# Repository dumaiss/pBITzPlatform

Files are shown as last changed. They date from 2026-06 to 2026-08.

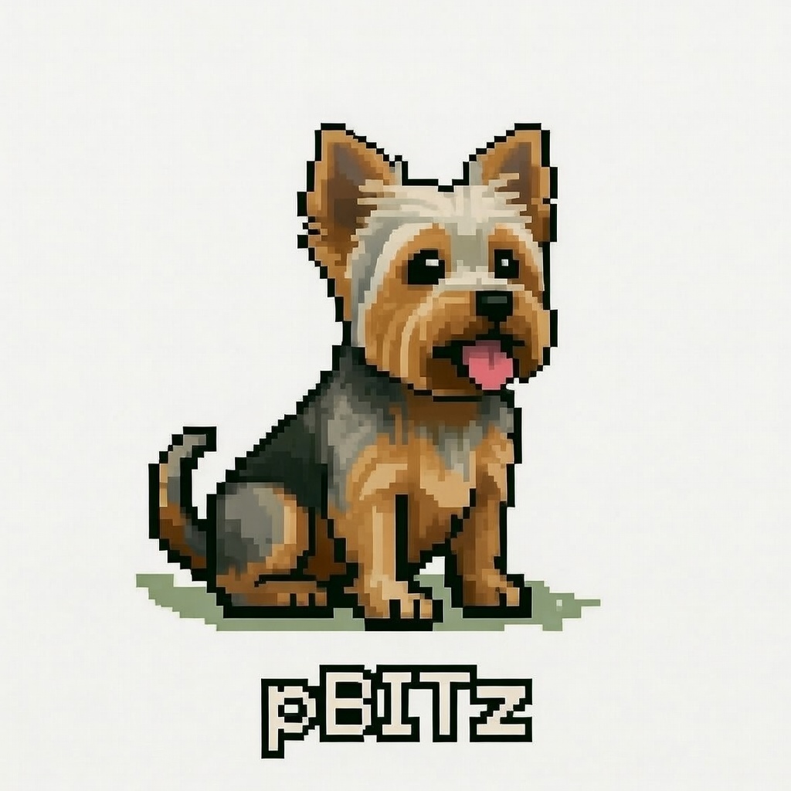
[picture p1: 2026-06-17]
pBITz.jpg

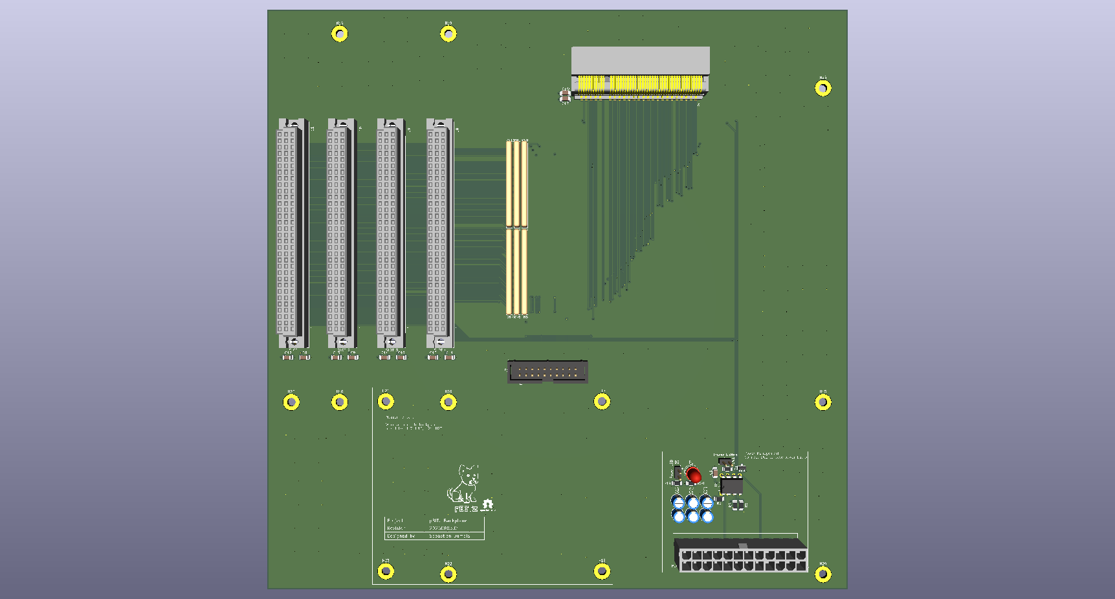
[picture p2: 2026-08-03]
pBITzBackplane/pBITzBackplane.png

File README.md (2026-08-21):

# pBITz Platform

pBITz is the shared hardware platform used by the **Coffee Series** of homebrew computers. It provides the common physical and electrical foundation — backplane, power control, service interfaces, reusable KiCad assets, test hardware, and platform tools — while leaving the personality of each machine to its CPU board and machine-specific peripherals.

The goal is not to define one rigid computer architecture. Instead, pBITz provides a practical common platform on which very different machines can be built: 8-bit, 16-bit, and eventually wider systems can share the same mechanical infrastructure, power distribution, expansion-card format, and platform services without pretending that a Z80, 6309, 68000, 68030, or ARM-class processor has the same bus semantics.

This repository contains the **platform-level** hardware and support material. Machine-specific CPU, video, sound, and operating-system work normally lives in the corresponding Coffee Series repository.

> **Important:** pBITz is a custom parallel expansion bus. The current platform uses DIN 41612-style connectors; it is not PCI Express and is not electrically compatible with PC expansion buses.

## Design philosophy

pBITz deliberately keeps the backplane simple.

The backplane distributes signals, power, clocks, and service connections, but it does not try to impose a universal bus controller or chipset. The CPU board for a particular machine is responsible for turning that machine's native bus into the pBITz signal conventions and for defining how the generic control lines are interpreted.

That leads to a few guiding principles:

- **The backplane is infrastructure, not the computer.** The machine emerges from the CPU board, IO Controller, and installed peripheral cards.
- **Use conventional parallel buses where practical.** Address, data, read/write, interrupt, arbitration, and timing signals remain visible rather than being hidden behind an FPGA SoC.
- **Share mechanics and services without forcing identical CPU semantics.** An 8-bit machine may use only part of the available data/address width; a 16-bit machine can use more of it.
- **Keep platform services separate from machine personality.** Power management, the service SPI bus, removable storage, USB hosting, test interfaces, and reusable CAD assets belong here.
- **Prefer inspectable hardware.** The project is intended to remain understandable with schematics, logic probes, oscilloscopes, PLDs, and ordinary firmware tools.

## Platform overview

At a high level, a pBITz system looks like this:

```text
                        +----------------------+
                        |   Coffee Series      |
                        |     CPU board        |
                        +----------+-----------+
                                   |
          +------------------------+------------------------+
          |                    pBITz bus                    |
          | address / data / control / clocks / power      |
          +-----+------------------+------------------+-----+
                |                  |                  |
          +-----+-----+      +-----+-----+      +-----+-----+
          |  Video    |      |   Sound   |      | Other I/O |
          |   card    |      |   card    |      |   cards   |
          +-----------+      +-----------+      +-----------+
                                   |
                           pBITz backplane
                                   |
                +------------------+------------------+
                |                                     |
          ATX power / PMU                    service / SPI header
                                                      |
                                             +--------+--------+
                                             |   mezzanine     |
                                             | USB host + SD   |
                                             +-----------------+
```

The exact cards and signal meanings depend on the machine being built.

## pBITz bus

The pBITz expansion bus is intentionally broader than any one Coffee Series CPU requires. The current signal set provides room for:

- up to a **24-bit address bus**;
- up to a **16-bit data bus**;
- generic CPU control/status lines (`CTRL_*`) whose meanings are assigned by the CPU implementation;
- chip-select lines;
- multiple clock lines;
- interrupt and bus-control signals;
- a shared platform **SPI/service bus**;
- system reset and power-management signals;
- `+5 V`, `+3.3 V`, and ground distribution.

An individual machine does not need to use every signal. For example, an 8-bit CPU board can use the low data byte and the subset of address/control lines it needs, while a 16-bit machine can make use of the wider path.

The generic control-line approach is deliberate. Signals such as read, write, memory request, I/O request, bus arbitration, wait/ready, interrupt, and byte strobes differ significantly between processor families. The CPU board performs the required mapping rather than forcing every machine through a single artificial protocol.

See [`pBITz_Control_Signals.md`](pBITz_Control_Signals.md) and, more importantly, the current KiCad schematics for the concrete mapping used by a particular hardware revision.

## Backplane

[`pBITzBackplane/`](pBITzBackplane/) contains the main pBITz backplane.

It is primarily a passive bus-distribution board with an always-on power-management island. Its responsibilities include:

- distributing the pBITz address, data, control, clock, and service signals between slots;
- distributing `+5 V`, `+3.3 V`, and ground from an ATX supply;
- providing bus pull-ups where required;
- exposing the platform service interface on an IDC header;
- coordinating ATX power-up and orderly shutdown through the PMU.

The directory contains the KiCad source, fabrication outputs, architecture notes, and revision-specific validation material.

### Power management

The backplane includes an ATtiny-based **PMU** powered from the ATX standby rail. It handles the enclosure power switch and ATX `PS_ON#` / `PWR_OK` sequencing and can coordinate an orderly shutdown with the machine's IO Controller.

PMU firmware lives under [`Code/PMU/`](Code/PMU/).

## Backplane mezzanine

[`pBITzBackplaneMezzanine/`](pBITzBackplaneMezzanine/) contains the platform I/O mezzanine attached through the backplane service connector.

The current design provides:

- a **MAX3421E** SPI USB host controller;
- an **FE1.1** USB hub;
- multiple downstream USB connections;
- an **SD card** operating in SPI mode;
- the necessary buffering, level conversion, power distribution, and card-detect/interrupt paths.

This keeps common storage and USB services out of the CPU-specific logic while still making them available to machines through the platform service interface.

## Platform support hardware

### pBITz Test Card

[`pBITzTestCard/`](pBITzTestCard/) is a work-in-progress platform development and diagnostic card. The current schematic work includes concepts for:

- a console interface;
- external programming support;
- an MCU-based controller;
- USB/JTAG programming and test functions.

This project is currently development hardware rather than a finished production design.

### pBITz Terminal

[`pBITzTerminal/`](pBITzTerminal/) explores a standalone serial terminal suitable for use with pBITz and other retro systems.

The current architecture is based around an HD63C03-family CPU and MC6845-compatible CRTC, with a VGA-style text display, PS/2 keyboard support, serial communications, banked SRAM, programmable character memory, and PLD-based video/bus arbitration.

The terminal is an experimental design and should not be treated as a completed board yet.

## Platform tools and firmware

[`Code/`](Code/) contains code that belongs to the platform rather than to one specific Coffee Series machine.

Current contents include:

- [`Code/PMU/`](Code/PMU/) — ATtiny power-management firmware, including a host-testable state machine;
- [`Code/tools/kicad_nettrace.py`](Code/tools/kicad_nettrace.py) — a KiCad schematic connectivity-analysis helper used during design reviews.

A typical connectivity check is:

```sh
python3 Code/tools/kicad_nettrace.py pBITzBackplane/pBITzBackplane.kicad_sch --check
```

`kicad_nettrace.py` is a review aid, not a replacement for KiCad's own connectivity model. When the helper and KiCad disagree, the **KiCad schematic/netlist is authoritative**.

## Shared KiCad assets

[`99-KiCad-Lib/`](99-KiCad-Lib/) is the shared CAD library used across the platform and Coffee Series projects. It contains:

- custom schematic symbols;
- footprints;
- 3D models;
- pBITz connector definitions;
- reusable parts used by the various machines;
- project artwork and board logos.

Keeping these assets in the platform repository avoids maintaining slightly different copies in every machine repository.

## Datasheets

[`00-Datasheets/`](00-Datasheets/) collects component documentation used while designing the platform and Coffee Series machines. It is organized by broad component class, including:

- analog;
- CPUs and MCUs;
- connectors;
- logic;
- memory;
- oscillators;
- peripherals;
- power components.

The datasheet directory is a working engineering reference, not intended to be a complete historical semiconductor archive.

## Repository layout

| Path | Purpose | Status |
| --- | --- | --- |
| `pBITzBackplane/` | Main backplane, ATX interface, PMU hardware, service bus | Active hardware design |
| `pBITzBackplaneMezzanine/` | Shared USB/SD service mezzanine | Active hardware design |
| `Code/PMU/` | Backplane power-management firmware | Implemented / evolving |
| `Code/tools/` | Platform engineering and KiCad-analysis tools | Active |
| `pBITzTestCard/` | Platform diagnostic/programming card | Work in progress |
| `pBITzTerminal/` | Standalone serial/VGA terminal experiment | Experimental |
| `99-KiCad-Lib/` | Shared KiCad symbols, footprints, and 3D models | Shared infrastructure |
| `00-Datasheets/` | Engineering reference datasheets | Shared infrastructure |
| `pBITz_Control_Signals.md` | Cross-CPU control-signal mapping notes | Design reference |

## Relationship to the Coffee Series

pBITz exists so that the Coffee Series machines can share a physical platform without becoming variants of the same computer.

Examples of machines built or planned around the platform include architectures based on processors such as the Z80, HD6309, 68000/68030, and ARM-class CPUs. Each machine is free to define its own memory architecture, CPU timing, interrupt model, video hardware, sound hardware, firmware, and operating system while reusing the pBITz mechanical and platform infrastructure where it makes sense.

In other words:

> **pBITz provides the chassis and electrical vocabulary; the CPU and peripheral set define the computer.**

## Source of truth and revision notes

This is an actively developed hardware platform. Schematics, PCB layouts, production files, architecture notes, and validation reports do not always change at the same time.

When reviewing a design:

1. treat the current **KiCad schematic and PCB files** as the source of truth for the active hardware revision;
2. use architecture documents to explain intent and operation;
3. check the date/revision of validation reports and fabrication outputs before assuming they describe the current board;
4. regenerate production files after a hardware revision rather than assuming an older BOM/Gerber package remains current.

This is particularly important when a mechanical or connector revision changes without altering the higher-level bus concept.

## Hardware status and validation

Validation reports in this repository document engineering checks performed against particular revisions of the design files. They are useful review records, but they are not certification and do not replace physical bring-up.

Unless explicitly stated otherwise, repository-level validation may include schematic/netlist consistency and selected PCB checks, while powered measurements, signal-integrity characterization, enclosure fit, manufacturing tolerances, and real-hardware testing remain separate activities.

## License

Unless noted otherwise, the hardware and associated source material in this repository are released under the **Solderpad Hardware License v2.1**, with the option described in the license to treat the work under Apache License 2.0.

See [`Licence.md`](Licence.md) for the complete terms.

---

pBITz is an evolving homebrew-computer platform. Expect the schematics to remain understandable, the buses to remain visible, and occasionally a logic analyzer to become part of the debugging process.

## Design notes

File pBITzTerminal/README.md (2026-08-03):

# HD63C03Y VGA Terminal — Preliminary BOM

**Revision:** Rev A draft
**Board:** 100 × 100 mm, 4 layers
**Supply:** Regulated +5 V
**Display target:** 80 × 30 characters, 8 × 16 glyphs, approximately 640 × 480 at 60 Hz
**Host interfaces:** RS-232 fitted; RS-422/pBITz interface DNP
**Keyboard:** PS/2
**Terminal target:** VT100-compatible firmware with ANSI color extensions

## 1. Architecture summary

* Hitachi HD63C03Y CPU at 3 MHz
* Motorola MC6845B CRTC at 3 MHz
* 24.000 MHz master video clock
* 14.7456 MHz baud-rate reference
* 32 KiB firmware EEPROM
* 512 KiB banked SRAM
* 8 KiB programmable character EEPROM
* Two independently mapped 16 KiB CPU SRAM windows
* One independently selected 16 KiB video bank
* Four-slot shared-SRAM cycle:

  1. Character fetch
  2. Primary attribute fetch
  3. Secondary attribute fetch
  4. CPU access
* Multiple ATF22V10 PLDs for clocks, decode, arbitration, baud generation, and video attributes

## 2. CPU memory map

| Address | Function |
| --- | --- |
| `0000–0027` | HD63C03Y internal registers |
| `0028–003F` | Unused/reserved external space |
| `0040–013F` | HD63C03Y internal 256-byte RAM |
| `0140–3FFF` | SRAM window A, selected by `BANK_A` |
| `4000–7FEF` | SRAM window B, selected by `BANK_B` |
| `7FF0–7FFF` | External control-register block |
| `8000–FFFF` | AT28C256 firmware EEPROM and interrupt vectors |

Although the internal register/RAM area obscures part of logical window A, no physical SRAM is lost: the same physical bank can be mapped into window B to access offsets `0000–013F`.

### External register block

| Address | Register | Access |
| --- | --- | --- |
| `7FF0` | MC6845 register index | Write |
| `7FF1` | MC6845 register data  | Read/write |
| `7FF2` | SRAM bank A, bits 0–4 | Write |
| `7FF3` | SRAM bank B, bits 0–4 | Write |
| `7FF4` | Video bank/control | Write |
| `7FF5–7FFF` | Reserved | — |

Suggested `VIDEO_BANK/CONTROL` format:

| Bit | Function |
| --: | --- |
| 0–4 | Physical 16 KiB video bank |
| 5 | Global font-bank select |
| 6 | Video enable |
| 7 | Reserved |

## 3. Video-bank layout

Each video bank is 16 KiB:

| Offset |  Size | Function |
| --- | ----: | --- |
| `0000–0FFF` | 4 KiB | Character cells |
| `1000–1FFF` | 4 KiB | Primary attributes |
| `2000–2FFF` | 4 KiB | Secondary attributes |
| `3000–3FFF` | 4 KiB | Spare: line metadata, tab state, future use |

An 80 × 30 display requires 2,400 entries in each plane, leaving spare space for circular scrolling.

### Suggested attributes

Primary attribute byte:

| Bits | Function |
| ---- | --- |
| 0–2  | Foreground RGB |
| 3–5  | Background RGB |
| 6 | Bright/bold |
| 7 | Blink |

Secondary attribute byte:

| Bit | Function |
| --: | --- |
| 0 | Underline |
| 1 | Protected field |
| 2 | Application-defined |
| 3 | Application-defined |
| 4–7 | Reserved |

Reverse video and conceal can be encoded when the character is written by swapping or replacing foreground/background colors.

## 4. Character EEPROM layout

The AT28C64B contains two programmable 256-character fonts:

| Address | Function |
| --- | --- |
| `0000–0FFF` | Font bank 0: 256 × 16-byte glyphs |
| `1000–1FFF` | Font bank 1: alternate font |

Address assignment:

```text
A0–A3   = MC6845 raster address RA0–RA3
A4–A11  = character code
A12      = global font-bank select
```

DEC Special Graphics characters can be placed in unused positions of the 256-character font and selected by firmware character translation.

## 5. Main integrated circuits

| Ref. | Qty | Selected part/function | Package | Source |
| ---- | --: | --- | --- | --- |
| U1 | 1 | HD63C03YCP CPU | PLCC-68 | BUY |
| U2 | 1 | MC6845B CRTC | DIP-40  | STASH |
| U3 | 1 | AT28C256-15PU firmware EEPROM, 32 KiB  | DIP-28  | STASH |
| U4 | 1 | AS6C4008-55PIN SRAM, 512 KiB | DIP-32  | STASH |
| U5 | 1 | AT28C64B-15PU character EEPROM, 8 KiB  | DIP-28  | STASH |
| U6 | 1 | ATF22V10C-10SU system decode PLD | SOIC-24 | STASH—VERIFY |
| U7 | 1 | ATF22V10C-10SU SRAM arbitration PLD | SOIC-24 | STASH—VERIFY |
| U8 | 1 | ATF22V10C-10SU master-clock/timing PLD | SOIC-24 | STASH—VERIFY |
| U9 | 1 | ATF22V10C-10SU baud-rate PLD | SOIC-24 | STASH—VERIFY |
| U10  | 1 | ATF22V10C-10SU attribute/RGB PLD | SOIC-24 | STASH—VERIFY |

### Intended PLD responsibilities

**U6 — SYS**

* EEPROM chip enable
* MC6845 select
* external register decode
* bank-latch write strobes
* video-control write strobe
* readback qualification

**U7 — ARB**

* shared-SRAM CPU/video ownership
* `MR` wait generation
* SRAM `/OE` and `/WE`
* SRAM/data-transceiver enable
* bank-latch output enables
* CPU/video address-mux select

**U8 — CLOCK**

* 24 MHz phase counter
* 12 MHz HD63C03 EXTAL output
* 3 MHz MC6845 character clock
* character/attribute fetch strobes
* character-boundary pipeline load

**U9 — BAUD**

* programmable division of 14.7456 MHz
* external SCI clocks for:

  * 115200 baud
  * 57600 baud
  * 38400 baud
  * 19200 baud
  * 9600 baud

**U10 — VIDEO**

* foreground/background selection
* bold/highlight
* blink
* underline
* cursor rendering
* blanking
* six RGB intensity outputs

## 6. SRAM banking and video pipeline

| Ref. | Qty | Part/function | Package | Source |
| --- | --: | --- | --- | --- |
| U11–U13 | 3 | SN74HC373 bank/control latches | TSSOP-20 | STASH—VERIFY |
| U14 | 1 | SN74HC373 character staging latch | TSSOP-20 | STASH—VERIFY |
| U15 | 1 | SN74HC373 primary-attribute staging latch | TSSOP-20 | STASH—VERIFY |
| U16 | 1 | SN74HC373 secondary-attribute staging latch | TSSOP-20 | STASH—VERIFY |
| U17 | 1 | SN74HC373 active primary-attribute latch | TSSOP-20 | STASH—VERIFY |
| U18 | 1 | SN74HC273 pipeline/control latch | SOIC-20 | STASH—VERIFY |
| U19–U22 | 4 | 74AHCT157 quad 2:1 address multiplexers | TSSOP-16/SOIC-16 | BUY |
| U23 | 1 | 74HCT245 bidirectional SRAM bus transceiver | TSSOP-20/SOIC-20 | BUY |
| U24 | 1 | CD74HC299 universal shift register | SOIC-20 | STASH—VERIFY |
| U25 | 1 | SN74HC244 VGA output buffer | SOIC-20 | STASH—VERIFY |
| U26 | 1 | 74HC00 sync inversion/miscellaneous glue | SOIC-14 | STASH |

### Bank-latch arrangement

`BANK_A`, `BANK_B`, and `VIDEO_BANK` latch outputs share SRAM physical address lines `A14–A18`.

Only one latch output is enabled at a time:

```text
CPU access in window A → enable BANK_A
CPU access in window B → enable BANK_B
Video fetch            → enable VIDEO_BANK
```

The PLD must guarantee mutually exclusive, break-before-make output enables.

### Shared-SRAM timing

At 24 MHz, one character period contains eight pixel clocks.

```text
Pixel clocks 0–1: character-plane SRAM read
Pixel clocks 2–3: primary-attribute SRAM read
Pixel clocks 4–5: secondary-attribute SRAM read
Pixel clocks 6–7: CPU SRAM access
```

The CPU `MR` input aligns and stretches SRAM accesses when required. EEPROM and internal-register accesses do not require SRAM arbitration.

## 7. Clock generation

| Ref. | Qty | Part/function | Package | Source |
| ---- | --: | --- | --- | --- |
| X1 | 1 | 24.000 MHz, 5 V HCMOS oscillator | SMD | BUY |
| X2 | 1 | ECS-2100AX-147.4, 14.7456 MHz oscillator | Through-hole XO | STASH  |
| Cx | 2 | 100 nF oscillator decoupling | 0603 | STASH  |
| Rx | 2 | 10 kΩ oscillator-enable pull resistors, if required | 0603 | STASH  |

Clock tree:

```text
24.000 MHz
 ├── direct → pixel shift clock
 ├── ÷2     → 12 MHz HD63C03 EXTAL
 └── ÷8     → 3 MHz MC6845 character clock

14.7456 MHz
 └── programmable divider → HD63C03 P22/SCLK
```

## 8. RS-232 interface

| Ref.  | Qty | Part/function | Package | Source |
| ----- | --: | --- | --- | --- |
| U27 | 1 | MAX233-compatible dual RS-232 transceiver | SOIC-20 | BUY |
| J1 | 1 | DE-9 serial connector | Right-angle through-hole | BUY/TBD |
| R1–R6 | 6 | 0 Ω DTE/DCE routing links | 0603 | BUY/STASH |
| C1 | 1 | 100 nF decoupling | 0603 | STASH |
| D1 | 1 | RS-232 ESD protection array | SMD | OPTIONAL/DNP |

One transmitter/receiver pair carries TX/RX. The second pair may carry RTS/CTS.

The connector routing should permit DTE or DCE population through 0 Ω links.

## 9. PS/2 keyboard interface

| Ref. | Qty | Part/function | Package | Source |
| --- | --: | --- | --- | --- |
| J2 | 1 | Mini-DIN-6 PS/2 receptacle | Right-angle through-hole | BUY |
| R7–R8  | 2 | 4.7 kΩ CLK/DATA pull-ups | 0603 | STASH |
| R9–R10 | 2 | 100–220 Ω series resistors | 0603 | BUY/TBD |
| D2 | 1 | Low-capacitance ESD array | SMD | OPTIONAL/DNP |
| F1 | 1 | Keyboard +5 V resettable fuse | 1206 | STASH/TBD |

The HD63C03 drives CLK and DATA low by changing the relevant port pin to an output-low state and releases the line by returning it to input mode.

## 10. VGA output

| Ref. | Qty | Part/function | Package | Source |
| --- | --: | --- | --- | --- |
| J3 | 1 | DE-15 VGA receptacle | Right-angle through-hole | BUY |
| R11–R16 | 6 | 1.0 kΩ RGB normal/bright resistors | 0603 | STASH |
| R17–R18 | 2 | 33 Ω HSYNC/VSYNC series resistors  | 0603 | STASH |
| D3 | 1 | VGA ESD protection array | SMD | OPTIONAL/DNP |

Each color channel uses two approximately equal resistor branches:

```text
normal-color output ── 1 kΩ ──┐
bright-color output ── 1 kΩ ──┼── VGA color pin
                              └── 75 Ω termination in monitor
```

Approximate levels:

```text
Normal:  one 1 kΩ branch active  → approximately 0.35 V
Bright:  two 1 kΩ branches active → approximately 0.65 V
```

U25 supplies six RGB outputs and buffered HSYNC/VSYNC.

## 11. Reset, configuration, and indicators

| Ref. | Qty | Part/function | Package | Source |
| --- | --: | --- | --- | --- |
| U28 | 1 | 5 V active-low reset supervisor, ≥20 ms delay | SOT-23 | BUY |
| SW1 | 1 | Momentary reset switch | SMD/TH | BUY |
| SW2 | 1 | 4-position configuration DIP switch | SMD/TH | STASH/BUY |
| LED1 | 1 | Power LED | 0603/1206 | STASH |
| LED2 | 1 | Status/RX LED | 0603/1206 | STASH |
| LED3 | 1 | Status/TX LED | 0603/1206 | STASH |
| R19–R21 | 3 | 1 kΩ LED resistors | 0603 | STASH |
| BZ1 | 1 | 5 V piezoelectric terminal bell | Through-hole/SMD | OPTIONAL  |
| Q1 | 1 | Small transistor/MOSFET for bell | SOT-23 | OPTIONAL  |
| R22 | 1 | Bell gate/base resistor | 0603 | OPTIONAL  |

The internal 256-byte RAM is available immediately after reset, allowing firmware to establish a stack and initialize the undefined external bank latches before using external SRAM.

## 12. Power and decoupling

| Ref. | Qty | Part/function | Package | Source  |
| --- | --: | --- | --- | --- |
| J4 | 1 | Regulated +5 V input connector | TBD | BUY |
| F2 | 1 | 0.75–1.0 A resettable fuse | SMD | BUY/TBD |
| D4 | 1 | Reverse-polarity protection device | SMD | BUY/TBD |
| C2–C31  | ~30 | 100 nF ceramic decoupling | 0603 | STASH |
| C32–C35 | 4 | 4.7–10 µF local bulk capacitors | 0603/1206 | STASH |
| C36 | 1 | 100 µF input bulk capacitor | Radial TH | STASH |
| TP1 | 1 | +5 V test point | — | PCB |
| TP2 | 1 | Ground test point | — | PCB |

Use one 100 nF capacitor per IC, placed at the power pins. Additional bulk capacitors should be placed near the PLD cluster, memory/video cluster, and external connectors.

## 13. Sockets and mechanical items

| Qty | Item | Source |
| --: | --- | --- |
| 1 | PLCC-68 socket for HD63C03YCP  | BUY |
| 1 | DIP-40 socket for MC6845B | STASH/BUY |
| 1 | DIP-32 socket for AS6C4008 | BUY |
| 2 | DIP-28 sockets for EEPROMs | STASH/BUY |
| 4 | M3 mounting holes and hardware | BUY |
| 1 | 100 × 100 mm four-layer PCB | FAB |
| 1 | Enclosure | TBD |

SOIC ATF22V10 devices must be programmed before assembly. Provide accessible test pads for all PLD pins and retain an optional DIP-24 development footprint or adapter strategy if frequent PLD iterations are expected.

## 14. Future RS-422/pBITz interface — DNP

Do not finalize these parts until the pBITz external peripheral electrical standard is frozen.

| Ref. | Qty | Placeholder function | Status  |
| --- | --: | --- | --- |
| U29 | 1 | RS-422 line driver, e.g. AM26C31 class | DNP |
| U30 | 1 | RS-422 line receiver, e.g. AM26C32 class | DNP |
| J5 | 1 | pBITz external peripheral connector | DNP/TBD |
| R23–R24 | 2 | 120 Ω termination | DNP |
| R25–R28 | 4 | Receiver bias resistors | DNP/TBD |
| D5 | 1 | Differential-line TVS array | DNP |

## 15. Optional service/debug connections

| Ref. | Qty | Function |
| --- | --: | --- |
| J6 | 1 | TTL-level serial/debug header |
| J7 | 1 | Logic-analyzer header: E, R/W, MR, phase bits, SRAM controls |
| J8 | 1 | Video test header: pixel, DE, HSYNC, VSYNC, glyph load |
| TP3–TP8 | 6 | Major clock and arbitration test points |

## 16. Immediate purchase list

### Required

* 1 × HD63C03YCP, verified PLCC-68
* 1 × PLCC-68 socket
* 1 × 24.000 MHz 5 V HCMOS oscillator
* 4 × 74AHCT157 address multiplexers
* 1 × SMD 74HCT245 bus transceiver
* 1 × MAX233-compatible SMD RS-232 transceiver
* 1 × DE-15 VGA connector
* 1 × Mini-DIN-6 PS/2 connector
* 1 × serial connector
* 1 × reset supervisor
* 1 × appropriately rated resettable fuse
* remaining sockets and mechanical hardware

### Verify in stash before ordering

* 5 × ATF22V10C-10SU
* 7 × SN74HC373 SMD
* 1 × SN74HC273 SMD
* 1 × CD74HC299 SMD
* 1 × SN74HC244 SMD
* 1 × 74HC00 SMD
* 1 × 14.7456 MHz oscillator
* AT28C256
* AT28C64B
* AS6C4008-55PIN
* MC6845B

## 17. Open engineering items

1. Verify the exact MC6845B markings and timing grade.
2. Simulate or bench-test the 83.3 ns SRAM fetch slots with the chosen `157` family.
3. Confirm `MR` phase alignment against the HD63C03Y external bus timing.
4. Determine VGA horizontal/vertical totals for the 24 MHz pixel clock.
5. Freeze the DE-9 DTE/DCE arrangement.
6. Confirm SOIC PLD programming and rework strategy.
7. Establish worst-case +5 V current before selecting the input fuse.
8. Freeze the attribute-byte definitions before writing the video PLD equations.
9. Decide whether the second font EEPROM bank is:

   * alternate terminal font,
   * CP437,
   * Japanese/graphics experiment,
   * or a diagnostic font.

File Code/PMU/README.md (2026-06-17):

# PMU Firmware

Power management unit firmware for the Zephyr-80 system.

The project is intentionally self-contained so additional MCU firmware projects
can be added beside it under `Code/MCU/`.

## Layout

```text
PMU/
  Makefile          AVR-GCC build and flash targets
  include/          Project headers and configuration
  src/              Firmware source
  docs/             Device-specific notes, pinout, and programming details
  build/            Generated objects and firmware images
```

## Toolchain

Expected tools:

- `avr-gcc`
- `avr-objcopy`
- `avr-size`
- `avrdude`

On Debian/Ubuntu systems these are usually provided by:

```sh
sudo apt install gcc-avr avr-libc avrdude
```

## Build

```sh
make
```

Generated files are written to `build/`.

## Test

The power-control policy is implemented as a host-testable state machine.

```sh
make test
```

The tests compile with the host C compiler and do not require the AVR toolchain.

## Flash

Update `PROGRAMMER`, `PORT`, and fuse values in `Makefile` before programming a
real device.

```sh
make flash
```

Fuse programming is separated from firmware flashing:

```sh
make fuses
```

## Power-Control Signals

| Signal | Port | Direction | Active State |
| --- | --- | --- | --- |
| `PWR_OFF_RQ` | PB4 | Input | Low |
| `PWR_STATE` | PB3 | Output | High holds reset, low allows run |
| `PWR_SW` | PB2 | Input | Low |
| `PWR_OK` | PB1 | Input | High |
| `PS_ON` | PB0 | Output | High at PB0, low at ATX `PS_ON#` |

See `docs/pinout.md` for the full pinout and signal behavior.

## IO Controller Bypass

Set `PMU_IGNORE_IO_CONTROLLER_SIGNALS` to `1` in `include/config.h`, or pass it
as a compiler define, to build the PMU without the IO Controller handshake. In
that mode the PMU ignores `PWR_OFF_RQ` and leaves `PWR_STATE` as a high
impedance input instead of driving reset/run state toward the IO Controller.
The 5 second force-off button hold remains available when the handshake is
disabled.

## Power-Off Handshake

When the system is already powered and the enclosure power switch is pressed,
the PMU sets `PWR_STATE` high. This tells the IO Controller to hold the
system in reset and finish its shutdown work. The PMU keeps the PSU enabled
until the IO Controller asserts `PWR_OFF_RQ` low. At that point PB0 is turned
off, disabling the `PS_ON#` MOSFET and allowing the ATX supply to shut down.

If the enclosure power switch is held for 5 seconds while the system is powered,
the PMU turns PB0 off directly and shuts the PSU down without waiting for the IO
Controller.

## Power-On Sequence

When the enclosure power switch is pressed while the system is off, the PMU
turns PB0 on immediately, pulling ATX `PS_ON#` low to start the PSU.
`PWR_STATE` remains high during this startup window so the IO Controller holds
the system in reset. When `PWR_OK` is asserted, the PMU sets `PWR_STATE` low to
allow the IO Controller to run.

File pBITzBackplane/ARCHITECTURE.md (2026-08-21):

# pBITz Backplane Architecture

This document describes the current architecture and physical signal distribution of the `pBITzBackplane` KiCad project.

The source of truth for connectivity is the schematic hierarchy rooted at [`pBITzBackplane.kicad_sch`](pBITzBackplane.kicad_sch). This document explains that design in human-readable form; if this document and the current KiCad sources disagree, the **KiCad schematic wins**.

The logical meaning of the portable `CTRL_*` and `CS[3:0]` conventions is documented separately in [`../pBITz_Control_Signals.md`](../pBITz_Control_Signals.md). This file is intentionally the place where the **physical backplane connectors and their pin mappings** are documented.

---

## 1. Schematic hierarchy

The active design is divided into three sheets:

| Sheet | File | Role |
| --- | --- | --- |
| Root | `pBITzBackplane.kicad_sch` | Top-level hierarchy and board-level interconnect. |
| Power | `Power.kicad_sch` | ATX input, standby-powered PMU, power switch, indicators, and `PS_ON#` control. |
| Backplane | `Backplane.kicad_sch` | DIN expansion connectors, cartridge connector, service header, bus pull-ups, and slot decoupling. |

The backplane is deliberately simple. Apart from the power-management island it is primarily a passive distribution board; CPU-specific decode, timing adaptation, and bus semantics live on the CPU board or its associated glue logic.

---

## 2. Physical connector architecture

The current backplane has **two different expansion connector types** serving different mechanical roles:

| Ref | Role | Connector | Notes |
| --- | --- | --- | --- |
| `J8` | pBITz expansion slot | DIN 41612, 96-position | Amphenol `86093968114T55F1LF`; right-angle backplane connector. |
| `J9` | pBITz expansion slot | DIN 41612, 96-position | Same electrical pinout as J8. |
| `J10` | pBITz expansion slot | DIN 41612, 96-position | Same electrical pinout as J8. |
| `J11` | pBITz expansion slot | DIN 41612, 96-position | Same electrical pinout as J8. |
| `J6` | Cartridge slot | PCIe x8-style, 98-contact | Samtec `PCIE-098-02-X-D-RA`; right-angle connector. **Mechanical connector only: this is not PCI Express.** |
| `J7` | Platform service header | 2x10 IDC | Exposes power and the SPI/service interface to the backplane mezzanine. |

The four ordinary expansion positions therefore use the DIN connector introduced with the current pBITz mechanical architecture, while the cartridge slot deliberately retains the compact right-angle PCIe x8 connector.

### Important: the cartridge connector is not PCI Express

`J6` uses a connector mechanically associated with PCI Express, but its electrical interface is the **pBITz parallel bus**. A PCI Express card must never be connected to it, and a pBITz cartridge must never be inserted into a PC PCIe slot.

The cartridge connector is now part of the **main backplane**, not the USB/SD mezzanine. It receives the same current pBITz bus presented to the DIN expansion slots, including the general clock lines.

---

## 3. pBITz bus carried by the backplane

The current backplane distributes the following logical groups:

| Group | Signals | Notes |
| --- | --- | --- |
| Address | `A0..A23` | 24-bit parallel address bus. |
| Data | `D0..D15` | 16-bit parallel data bus. |
| Control | `CTRL_0..CTRL_19` | Cross-CPU control vocabulary; see `pBITz_Control_Signals.md`. |
| Device select | `CS0..CS3` | Push-pull 4-bit device address `CS[3:0]`; `0000` means no device selected. |
| General clocks | `CLK0`, `CLK1` | Two current general-purpose pBITz clock lines. Passive distribution only. |
| Auxiliary control | `/PROG`, `/CART` | Platform/machine auxiliary control lines. |
| Service SPI | `SPI_CLK`, `MOSI`, `MISO`, `SPI_CS0`, `SPI_CS1`, `/SPI_INT`, `/SPI_CD` | Shared platform service interface. `SPI_CLK` is separate from the general pBITz clock lines. |
| Power management | `/PWR_OFF`, `/SHUTDOWN_RQ` | PMU/IO-controller shutdown handshake. |
| Power | `+5V`, `+3V3`, `GND` | Distributed to expansion and cartridge connectors. |

### Clock count

The **current bus has two general clock lines: `CLK0` and `CLK1`**.

Older pBITz connector symbols and documentation contained additional `CLK2`/`CLK3` names. They are not active clocks in the current backplane. On the instantiated cartridge connector `J6`, the legacy A5/A6 positions associated with those old symbol names are explicitly unconnected; `CLK0` and `CLK1` are carried on J6 B5 and B6.

`SPI_CLK` is the clock of the separate service SPI interface and is not counted as a general pBITz CPU/peripheral clock.

The backplane does not synthesize or condition `CLK0` or `CLK1`; it only distributes them. Their source and meaning are defined by the machine/CPU implementation.

---

## 4. DIN 41612 expansion-slot pinout

`J8` through `J11` are electrically identical 96-position DIN 41612 pBITz slots. The connector uses rows A, B, and C with positions 1 through 32.

| Pos. | Row A | Row B | Row C |
| ---: | --- | --- | --- |
| 1 | `+5V` | `+5V` | `/PWR_OFF` |
| 2 | `+5V` | `+5V` | `/SHUTDOWN_RQ` |
| 3 | `+3V3` | `+3V3` | `GND` |
| 4 | `+3V3` | `+3V3` | `GND` |
| 5 | `CLK0` | `CLK1` | `SPI_CLK` |
| 6 | `/PROG` | `/CART` | `/SPI_CD` |
| 7 | `CTRL_0` (`/RESET`) | `CTRL_1` | `CTRL_2` |
| 8 | `CTRL_3` | `CTRL_4` | `CTRL_5` |
| 9 | `CTRL_6` | `CTRL_7` | `CTRL_8` |
| 10 | `CTRL_9` | `CTRL_10` | `CTRL_11` |
| 11 | `CTRL_12` | `CTRL_13` | `CTRL_14` |
| 12 | `CTRL_15` | `CTRL_16` | `CTRL_17` |
| 13 | `CTRL_18` | `CTRL_19` | `CS0` |
| 14 | `CS1` | `CS2` | `CS3` |
| 15 | `D0` | `D1` | `D2` |
| 16 | `D3` | `D4` | `D5` |
| 17 | `D6` | `D7` | `D8` |
| 18 | `D9` | `D10` | `D11` |
| 19 | `D12` | `D13` | `D14` |
| 20 | `D15` | `GND` | `GND` |
| 21 | `A0` | `A1` | `A2` |
| 22 | `A3` | `A4` | `A5` |
| 23 | `A6` | `A7` | `A8` |
| 24 | `A9` | `A10` | `A11` |
| 25 | `A12` | `A13` | `A14` |
| 26 | `A15` | `A16` | `A17` |
| 27 | `A18` | `A19` | `A20` |
| 28 | `A21` | `A22` | `A23` |
| 29 | `GND` | `GND` | `GND` |
| 30 | `/SPI_INT` | `MISO` | `MOSI` |
| 31 | `SPI_CS0` | `SPI_CS1` | `GND` |
| 32 | `GND` | `GND` | `GND` |

The connector shield/mechanical contacts `S1` and `S2` are also tied to `GND`.

The DIN layout deliberately groups related signals while inserting ground positions through the connector, particularly around the address and service portions of the bus.

---

## 5. Cartridge slot J6

`J6` is the dedicated cartridge connector. It uses the right-angle Samtec `PCIE-098-02-X-D-RA`, a 98-contact connector with A and B sides numbered 1 through 49.

Although the mechanical format is PCIe x8, **the entire electrical assignment is custom pBITz**.

### 5.1 Cartridge bus coverage

The cartridge connector exposes the full current pBITz interface needed by a cartridge to behave like a directly attached bus device:

- all `A0..A23` address lines;
- all `D0..D15` data lines;
- all `CTRL_0..CTRL_19` control lines;
- all four `CS[3:0]` device-select lines;
- both current general clocks, `CLK0` and `CLK1`;
- `/PROG` and `/CART`;
- the complete SPI/service interface;
- `/PWR_OFF` and `/SHUTDOWN_RQ`;
- `+5V`, `+3V3`, and ground.

The cartridge slot is therefore not a reduced sideband interface. Electrically it is another endpoint on the pBITz bus, with a different mechanical connector chosen for cartridge use.

### 5.2 Cartridge physical pinout

| Pos. | Side A | Side B |
| ---: | --- | --- |
| 1 | `+5V` | `+5V` |
| 2 | `+5V` | `+5V` |
| 3 | `/SHUTDOWN_RQ` | `/PWR_OFF` |
| 4 | `GND` | `GND` |
| 5 | **NC** (legacy `CLK2` position) | `CLK0` |
| 6 | **NC** (legacy `CLK3` position) | `CLK1` |
| 7 | `SPI_CLK` | `/SPI_CD` |
| 8 | `/PROG` | `/CART` |
| 9 | `+3V3` | `+3V3` |
| 10 | `+3V3` | `+3V3` |
| 11 | `CTRL_10` | `CTRL_0` (`/RESET`) |
| 12 | `CTRL_11` | `CTRL_1` |
| 13 | `CTRL_12` | `CTRL_2` |
| 14 | `CTRL_13` | `CTRL_3` |
| 15 | `CTRL_14` | `CTRL_4` |
| 16 | `CTRL_15` | `CTRL_5` |
| 17 | `CTRL_16` | `CTRL_6` |
| 18 | `CTRL_17` | `CTRL_7` |
| 19 | `CTRL_18` | `CTRL_8` |
| 20 | `CTRL_19` | `CTRL_9` |
| 21 | `CS2` | `CS0` |
| 22 | `CS3` | `CS1` |
| 23 | `D8` | `D0` |
| 24 | `D9` | `D1` |
| 25 | `D10` | `D2` |
| 26 | `D11` | `D3` |
| 27 | `D12` | `D4` |
| 28 | `D13` | `D5` |
| 29 | `D14` | `D6` |
| 30 | `D15` | `D7` |
| 31 | `GND` | `GND` |
| 32 | `A12` | `A0` |
| 33 | `A13` | `A1` |
| 34 | `A14` | `A2` |
| 35 | `GND` | `GND` |
| 36 | `A15` | `A3` |
| 37 | `A16` | `A4` |
| 38 | `A17` | `A5` |
| 39 | `GND` | `GND` |
| 40 | `A18` | `A6` |
| 41 | `A19` | `A7` |
| 42 | `A20` | `A8` |
| 43 | `GND` | `GND` |
| 44 | `A21` | `A9` |
| 45 | `A22` | `A10` |
| 46 | `A23` | `A11` |
| 47 | `/SPI_INT` | `GND` |
| 48 | `MISO` | `MOSI` |
| 49 | `SPI_CS0` | `SPI_CS1` |

The two explicit NC entries at A5 and A6 are intentional in the current design. They are remnants of the older connector symbol's larger clock allocation and must not be interpreted as active `CLK2`/`CLK3` signals.

---

## 6. Device selection and control semantics

The backplane transports the four `CS0..CS3` lines without decoding them. Collectively they form the push-pull 4-bit pBITz device address `CS[3:0]`:

- `0000` means **no pBITz device selected**;
- `0001` through `1111` select device addresses 1 through 15.

The CPU-side I/O decoder/MMU determines that a valid peripheral access is occurring and drives the device address. The selected card normally compares that value with a configured device number and then uses normal address lines for register or sub-device decode.

The meanings and CPU-family mappings of `CTRL_0..CTRL_19` are intentionally not duplicated here. See [`../pBITz_Control_Signals.md`](../pBITz_Control_Signals.md).

---

## 7. Backplane pull-ups and idle state

The backplane defines the idle state of the ordinary parallel bus with pull-up resistor networks.

The following shared bus groups are pulled high by the backplane:

- `A0..A23`;
- `D0..D15`;
- the parallel `CTRL_*` controls, including reset;
- `CS0..CS3`;
- the non-clock auxiliary parallel controls such as `/PROG` and `/CART`.

The current design uses 4.7 kΩ bussed resistor networks (`4614X-101-472LF`) for these parallel-bus pull-ups.

The general clock lines and SPI/service bus are **not** part of this pull-up network:

- `CLK0` and `CLK1` are not pulled up by the general bus networks;
- `SPI_CLK`, `MOSI`, `MISO`, `SPI_CS0`, `SPI_CS1`, `/SPI_INT`, and `/SPI_CD` are not treated as ordinary pulled-up parallel bus lines.

The power-management handshake lines have their own electrical rules and are described separately below.

This distinction is important for card design: cards can assume a defined high idle state on the normal address/data/control bus, but must not assume the same biasing on clocks or the SPI/service interface.

---

## 8. Platform service header J7

`J7` is a 2x10 IDC header (`SBH11-PBPC-D10-ST-BK`) used to connect the backplane service interface to the USB/SD mezzanine.

| J7 pin | Signal |
| ---: | --- |
| 1 | `+5V` |
| 2 | `+3V3` |
| 3 | `MOSI` |
| 4 | `SPI_CS0` |
| 5 | `MISO` |
| 6 | `GND` |
| 7 | `GND` |
| 8 | `SPI_CS1` |
| 9 | `SPI_CLK` |
| 10 | `GND` |
| 11 | `GND` |
| 12 | NC |
| 13 | `/SPI_INT` |
| 14 | `GND` |
| 15 | `GND` |
| 16 | `GND` |
| 17 | `/SPI_CD` |
| 18 | `GND` |
| 19 | `GND` |
| 20 | `GND` |

The service SPI bus is a platform facility and is separate from CPU-family-specific parallel bus timing. The mezzanine currently uses this interface for shared USB-host and SD-card services.

---

## 9. Power architecture

### 9.1 ATX input

`J1` is the 24-pin ATX power connector. The backplane uses:

- `+3.3V` to create the distributed `+3V3` rail;
- `+5V` to create the distributed `+5V` rail;
- `+5VSB` as the always-on `+5V_AON` rail for the PMU;
- `GND`;
- `PWR_OK`; and
- `PS_ON#`.

The pBITz bus does not distribute the ATX `+12V` or `-12V` rails in the current design.

### 9.2 PMU

The backplane contains a small always-on power-management island built around:

- `U1`, an `ATtiny85-20P` powered from `+5V_AON`;
- `Q1`, a `BSS138` used to pull ATX `PS_ON#` low;
- the enclosure power-switch input;
- `PWR_OK` sensing; and
- the `/PWR_OFF` / `/SHUTDOWN_RQ` handshake with the machine's IO Controller.

This is the only significant active logic on the backplane itself.

### 9.3 Shutdown handshake

The intended active-low power-control protocol is:

| Signal | Role | Electrical behavior |
| --- | --- | --- |
| `/PWR_OFF` | Request to the PMU to remove main power | Pulled up to `+5V_AON` on the backplane. Requesters assert by driving low and otherwise release the line. |
| `/SHUTDOWN_RQ` | PMU request for orderly machine shutdown | PMU asserts low/release; the IO Controller provides the operating-side pull-up. |

Typical orderly shutdown sequence:

1. `/PWR_OFF` is high during normal operation.
2. The PMU asserts `/SHUTDOWN_RQ` to ask the IO Controller to perform shutdown cleanup.
3. The IO Controller completes pending work and prepares the machine for power removal.
4. The IO Controller asserts `/PWR_OFF` low.
5. The PMU removes main ATX power through `PS_ON#` control.

The exact PMU state machine is implemented in [`../Code/PMU/`](../Code/PMU/).

---

## 10. Architectural boundaries

The backplane deliberately does **not** define:

- the CPU's memory map;
- where the pBITz peripheral aperture lives;
- which physical CPU signal directly corresponds to every `CTRL_*` line;
- clock frequencies carried on `CLK0` or `CLK1`;
- interrupt encoding inside a particular CPU family;
- wait-state translation for a particular CPU; or
- which device number is assigned to a particular peripheral card.

Those decisions belong to the CPU board and machine architecture. The backplane provides the common electrical vocabulary and mechanical infrastructure on which those machines are built.

---

## 11. Source-of-truth and revision policy

For the current hardware revision:

1. the KiCad schematic hierarchy rooted at `pBITzBackplane.kicad_sch` is authoritative for connectivity;
2. this architecture document describes the intent and physical pin mapping of that schematic;
3. [`../pBITz_Control_Signals.md`](../pBITz_Control_Signals.md) is authoritative for the portable logical meanings of `CTRL_*` and `CS[3:0]`;
4. PCB, BOM, Gerber, validation, and production files should always be checked against the revision from which they were generated.

Useful repo-relative review commands include:

```sh
python3 Code/tools/kicad_nettrace.py pBITzBackplane/pBITzBackplane.kicad_sch --check
python3 Code/tools/kicad_nettrace.py pBITzBackplane/pBITzBackplane.kicad_sch --list-nets
```

When helper tooling and KiCad disagree, the current KiCad schematic/netlist is the source of truth.

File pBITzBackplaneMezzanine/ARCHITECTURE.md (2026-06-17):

# pBITzBackplaneMezzanine Architecture

This document describes the active `pBITzBackplaneMezzanine` KiCad project as
checked out in this repository. The source of truth for connectivity is the
schematic hierarchy rooted at `pBITzBackplaneMezzanine.kicad_sch`, with the
generated KiCad schematic netlist used to resolve cases where
`kicad_nettrace.py` misses a connection. If the schematic and
`kicad_nettrace.py` disagree, the schematic wins.

## Scope And Sources

Active schematic hierarchy:

| Sheet | File | Role |
| --- | --- | --- |
| Root | `pBITzBackplaneMezzanine.kicad_sch` | Board-level hierarchy wiring between mezzanine connector, USB subsystem, and SD-card subsystem. |
| USBPorts | `USBPorts.kicad_sch` | MAX3421E SPI USB host controller, FE1.1 USB hub, downstream USB connectors, fuses, crystals, and USB support parts. |
| MezzanineConnector | `MezzanineConnector.kicad_sch` | 2x10 IDC mezzanine connector and mounting holes. |
| SD_Card | `SD_Card.kicad_sch` | SD-card socket, CD74HC4050 level shifter, SD-card pull-up, and decoupling. |

Trace commands used:

```sh
HOME=/tmp XDG_CONFIG_HOME=/tmp XDG_DATA_HOME=/tmp kicad-cli sch export netlist -o /tmp/pbitzbackplane-mezzanine-kicad.net pBITzBackplaneMezzanine/pBITzBackplaneMezzanine.kicad_sch
python3 Code/tools/kicad_nettrace.py pBITzBackplaneMezzanine/pBITzBackplaneMezzanine.kicad_sch
python3 Code/tools/kicad_nettrace.py pBITzBackplaneMezzanine/pBITzBackplaneMezzanine.kicad_sch --check
```

`kicad_nettrace.py` reported:

| Sheet | Pin hits | Coverage |
| --- | ---: | ---: |
| Root | 0/0 | 0% |
| USBPorts | 136/173 | 79% |
| MezzanineConnector | 27/28 | 96% |
| SD_Card | 31/37 | 84% |

The tracer found 97 nets and 211 placed pins, with no output-driver conflicts.
Its `--check` output is useful for finding obvious opens, but it misses several
connections that the KiCad schematic netlist resolves, including global power
connections on J5, fuses, the SD-card VDD pin, and 4050 power pins. The KiCad
schematic netlist is therefore used for the final connectivity tables.

## Board Overview

The mezzanine is an SPI-attached peripheral module. It takes power, ground, SPI,
interrupt, and card-detect/service signals from a 2x10 IDC mezzanine connector
and provides:

- A MAX3421E SPI USB host controller.
- An FE1.1 USB 2.0 hub behind the MAX3421E host interface.
- Two downstream USB-A receptacles on a stacked USB connector.
- Two auxiliary downstream USB 1x4 headers.
- An SPI-mode SD-card socket.

Physical PCB facts from `pBITzBackplaneMezzanine.kicad_pcb`:

| Item | Value |
| --- | --- |
| KiCad PCB version | 20260206 format |
| Copper stack | 4 layers: `F.Cu`, `In1.Cu`, `In2.Cu`, `B.Cu` |
| Footprints | 41 placed footprints |
| Mezzanine connector | `J5`, 2x10 IDC, footprint `Connector_IDC:IDC-Header_2x10_P2.54mm_Vertical` |
| USB-A connector | `J1`, stacked USB-A, footprint `Connector_USB:USB3_A_Molex_48406-0001_Horizontal_Stacked` |
| Auxiliary USB headers | `J2`, `J3`, 1x4 pin headers |
| SD-card connector | `J4`, footprint `Footprints:AMPHENOL_10067847-001RLF` |

Mechanical fit, board outline, connector mating height, and enclosure concerns
are outside the validation scope.

## Mezzanine Connector J5

`J5` is the module interface to the rest of the pBITz system. It carries both
rails, ground, SPI, interrupt, and SD-card-present information.

| J5 pin | Net | Role |
| ---: | --- | --- |
| 1 | `+5V` | USB hub supply and downstream USB VBUS source. |
| 2 | `+3V3` | Logic, MAX3421E, 4050 buffers, and SD-card supply. |
| 3 | `/MezzanineConnector/MOSI` | SPI MOSI from host/backplane into the mezzanine. |
| 4 | `/MezzanineConnector/SPI_CS0` | SD-card chip select input. |
| 5 | `/MezzanineConnector/MISO` | Shared SPI MISO back to host/backplane. |
| 6 | `GND` | Ground. |
| 7 | `GND` | Ground. |
| 8 | `/MezzanineConnector/SPI_CS1` | USB controller chip select input. |
| 9 | `/MezzanineConnector/SPI_CLK` | SPI clock input. |
| 10 | `GND` | Ground. |
| 11 | `GND` | Ground. |
| 12 | `unconnected-(J5-Pin_12-Pad12)` | Intentionally unused. |
| 13 | `/MezzanineConnector/~{SPI_INT}` | MAX3421E interrupt output to host/backplane. |
| 14 | `GND` | Ground. |
| 15 | `GND` | Ground. |
| 16 | `GND` | Ground. |
| 17 | `/MezzanineConnector/~{SD_PRESENT}` | SD-card-detect output to host/backplane. On the backplane service header this occupies the pin named `SPI_CD`. |
| 18 | `GND` | Ground. |
| 19 | `GND` | Ground. |
| 20 | `GND` | Ground. |

## Power Architecture

The board does not generate the main `+5V` or `+3V3` rails. They enter through
`J5`.

| Rail | Source | Loads |
| --- | --- | --- |
| `+5V` | `J5.1` | FE1.1 `VBUSM`/`VDD5`, USB downstream VBUS fuses, bulk/decoupling capacitors. |
| `+3V3` | `J5.2` | MAX3421E `VL`, `VCC`, and `~{RES}` pull-high; U3/U4 CD74HC4050 supplies; SD-card `VDD`; SD MISO pull-up; local decoupling. |
| `+3V3_INTERNAL` | FE1.1 `U1.21/VD33F` | FE1.1 support net for `OVCJ`, `BUSJ`/`XRSTJ` pull-ups, and local decoupling. |
| `GND` | J5 ground pins | Logic ground, shields, mounting-hole pads, hub/controller ground, SD ground. |

Downstream USB VBUS is protected per port by 500 mA polyfuses:

| Fuse | Input | Output |
| --- | --- | --- |
| `F2` | `+5V` | `/USBPorts/VBUS_PIN1` to stacked USB-A port 1. |
| `F1` | `+5V` | `/USBPorts/VBUS_PIN2` to stacked USB-A port 2. |
| `F3` | `+5V` | `/USBPorts/VBUS_PIN3` to auxiliary header `J2`. |
| `F4` | `+5V` | `/USBPorts/VBUS_PIN4` to auxiliary header `J3`. |

## SPI Fanout And Level Buffering

The mezzanine uses two CD74HC4050 non-inverting buffers to present 3.3 V logic
to local devices on host-driven SPI signals.

| Signal | Host/backplane net | Buffer | Local target net | Target |
| --- | --- | --- | --- | --- |
| USB MOSI | `/MezzanineConnector/MOSI` | `U3.3 -> U3.2` | `/USBPorts/MOSI` | `U2.16/MOSI` |
| USB chip select | `/MezzanineConnector/SPI_CS1` | `U3.5 -> U3.4` | `/USBPorts/~{CS}` | `U2.14/~{SS}` |
| USB SPI clock | `/MezzanineConnector/SPI_CLK` | `U3.7 -> U3.6` | `/USBPorts/CLK` | `U2.13/SCLK` |
| SD MOSI | `/MezzanineConnector/MOSI` | `U4.9 -> U4.10` | `/SD_Card/MOSI` | `J4.2/CMD` |
| SD chip select | `/MezzanineConnector/SPI_CS0` | `U4.11 -> U4.12` | `/SD_Card/~{CS}` | `J4.1/DAT3/CD` |
| SD SPI clock | `/MezzanineConnector/SPI_CLK` | `U4.14 -> U4.15` | `/SD_Card/CLK` | `J4.5/CLK` |

Shared return and status paths:

| Signal | Net | Members |
| --- | --- | --- |
| MISO | `/MezzanineConnector/MISO` | `J5.5`, `U2.15/MISO`, `J4.7/DAT0`, `R6.2`. |
| MISO pull-up | `+3V3` through `R6` | `R6.1` is `+3V3`, `R6.2` is MISO. |
| USB interrupt | `/MezzanineConnector/~{SPI_INT}` | `U2.18/INT`, `J5.13`. |
| SD present | `/MezzanineConnector/~{SD_PRESENT}` | `J4.CD`, `J5.17`. |

Unused 4050 inputs are tied to `GND`, and their paired outputs are intentionally
left unconnected. This keeps unused buffer inputs from floating.

## USB Subsystem

`U2` is a MAX3421E USB peripheral/host controller with SPI interface. In this
design it is the SPI-attached USB host controller for the module.

Key MAX3421E connections:

| U2 pin | Function | Net |
| ---: | --- | --- |
| 2 | `VL` | `+3V3` |
| 3, 19, 33 | Ground/exposed pad | `GND` |
| 12 | `~{RES}` | `+3V3` |
| 13 | `SCLK` | `/USBPorts/CLK` |
| 14 | `~{SS}` | `/USBPorts/~{CS}` |
| 15 | `MISO` | `/MezzanineConnector/MISO` |
| 16 | `MOSI` | `/USBPorts/MOSI` |
| 18 | `INT` | `/MezzanineConnector/~{SPI_INT}` |
| 20 | `D-` | `Net-(U2-D-)` through `R5` to `/USBPorts/D-` |
| 21 | `D+` | `Net-(U2-D+)` through `R4` to `/USBPorts/D+` |
| 23 | `VCC` | `+3V3` |
| 24, 25 | `XI`, `XO` | 12 MHz crystal `Y2` with 22 pF load capacitors. |

The MAX3421E USB pair connects to the FE1.1 upstream port:

| Path | Net |
| --- | --- |
| `U2.21/D+` -> `R4.2` -> `R4.1` -> `U1.16/DPU` | `Net-(U2-D+)` then `/USBPorts/D+` |
| `U2.20/D-` -> `R5.2` -> `R5.1` -> `U1.15/DMU` | `Net-(U2-D-)` then `/USBPorts/D-` |

`U1` is the FE1.1 USB 2.0 hub. It is supplied from `+5V`, generates
`+3V3_INTERNAL` on `VD33F`, and uses a 12 MHz crystal `Y1`. `R1` and `R2`
pull `BUSJ` and `XRSTJ` to `+3V3_INTERNAL`; `R3` is the 2.7k `REXT` resistor
to ground. `OVCJ` is tied to `+3V3_INTERNAL`, which holds the overcurrent input
inactive in this design.

Downstream ports:

| Port | FE1.1 nets | Connector |
| --- | --- | --- |
| 1 | `/USBPorts/DM1`, `/USBPorts/DP1`, `/USBPorts/VBUS_PIN1` | `J1` stacked USB-A port 1 |
| 2 | `/USBPorts/DM2`, `/USBPorts/DP2`, `/USBPorts/VBUS_PIN2` | `J1` stacked USB-A port 2 |
| 3 | `/USBPorts/DM3`, `/USBPorts/DP3`, `/USBPorts/VBUS_PIN3` | `J2` 1x4 auxiliary header |
| 4 | `/USBPorts/DM4`, `/USBPorts/DP4`, `/USBPorts/VBUS_PIN4` | `J3` 1x4 auxiliary header |

The current schematic and PCB assign the stacked USB-A connector `J1` USB 2.0
pins as follows:

| J1 pin | USB-A function | Current net |
| ---: | --- | --- |
| 2 | `D1-` | `/USBPorts/DM1` |
| 3 | `D1+` | `/USBPorts/DP1` |
| 11 | `D2-` | `/USBPorts/DM2` |
| 12 | `D2+` | `/USBPorts/DP2` |

This matches the expected polarity: FE1.1 `DMx` nets go to USB `D-` pins, and
`DPx` nets go to USB `D+` pins.

The USB3 SuperSpeed pins on `J1` are intentionally unconnected. This board uses
USB 2.0 signaling from the FE1.1 hub.

## SD-Card Subsystem

`J4` is wired for SPI-mode SD-card operation.

| J4 pin | SD function | Net |
| --- | --- | --- |
| 1 | `DAT3/CD` used as SPI CS | `/SD_Card/~{CS}` |
| 2 | `CMD` used as SPI MOSI | `/SD_Card/MOSI` |
| 3 | `VSS` | `GND` |
| 4 | `VDD` | `+3V3` |
| 5 | `CLK` | `/SD_Card/CLK` |
| 6 | `VSS` | `GND` |
| 7 | `DAT0` used as SPI MISO | `/MezzanineConnector/MISO` |
| 8 | `DAT1` | Intentionally unconnected. |
| 9 | `DAT2` | Intentionally unconnected. |
| `CD` | Card detect | `/MezzanineConnector/~{SD_PRESENT}` |
| `WP` | Write protect | Intentionally unconnected. |
| `G1`, `G2` | Shield/ground | `GND` |

`U4` buffers host-driven SD inputs down to the local 3.3 V domain. The SD MISO
line is not buffered; it is shared directly with the mezzanine MISO net and has
a 10k pull-up to `+3V3` through `R6`.

## Intentional Opens And No-Connects

Important intentional no-connects in the schematic netlist:

| Ref pins | Reason |
| --- | --- |
| `J5.12` | Unused mezzanine connector pin. |
| `J1.5`, `J1.6`, `J1.8`, `J1.9`, `J1.14`, `J1.15`, `J1.17`, `J1.18` | USB3 SuperSpeed pins unused on a USB 2.0 hub design. |
| `J4.8`, `J4.9`, `J4.WP` | SD `DAT1`, `DAT2`, and write-protect unused in SPI-mode design. |
| `U1.12`, `U1.13`, `U1.22`, `U1.23`, `U1.24`, `U1.25`, `U1.27`, `U1.28` | FE1.1 pins not used by this design. |
| `U2` GPIN/GPOUT pins, `U2.17/GPX`, `U2.22/VBCOMP` | MAX3421E auxiliary GPIO/status features not used by this design. |
| `U3.10`, `U3.12`, `U3.15`, `U4.2`, `U4.4`, `U4.6` | Outputs of unused 4050 buffer sections. |

Review note: the local MAX3421E datasheet identifies `VBCOMP` as the VBUS
comparator input and recommends bypassing it to ground. The current schematic
marks `U2.22/VBCOMP` no-connect. This was not counted as a blocking validation
failure because the comparator may be intentionally unused, but it should be
reviewed before fabrication.

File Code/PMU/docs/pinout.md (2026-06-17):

# PMU Pinout Notes

Power-control firmware pin assignments.

| Signal | PMU Pin | AVR Port | Direction | Active State | Type | Notes |
| --- | --- | --- | --- | --- | --- | --- |
| RESET | Physical pin 1 | PB5 | Input | High | Level | Held high for normal operation |
| PWR_OFF_RQ | Physical pin 3 | PB4 | Input | Low | Level | IO Controller requests soft power off |
| PWR_STATE | Physical pin 2 | PB3 | Output | High holds reset, low allows run | Level | Controls whether the IO Controller may run |
| PWR_SW | Physical pin 7 | PB2 | Input | Low | Edge | Physical power switch on the enclosure |
| PWR_OK | Physical pin 6 | PB1 | Input | High | Level | ATX connector `PWR_OK` |
| PS_ON | Physical pin 5 | PB0 | Output | High at PB0, low at ATX `PS_ON#` | Level | Drives ATX connector `PS_ON#` through a MOSFET |

## Firmware Behavior

- If `PMU_IGNORE_IO_CONTROLLER_SIGNALS` is set to `1`, the PMU does not sample
  `PWR_OFF_RQ` and leaves `PWR_STATE` as a high impedance input.
- `PWR_OFF_RQ` and `PWR_SW` use the PMU internal pull-ups.
- `PWR_OK` is treated as an externally driven ATX status signal.
- PB0 controls the `PS_ON#` MOSFET gate. PB0 high turns the MOSFET on and pulls
  ATX `PS_ON#` low. PB0 low turns the MOSFET off and lets the PSU turn off.
- `PWR_STATE` is a level signal. Low means the IO Controller is allowed to run.
  High means the IO Controller must hold the system in reset.
- During startup, `PWR_STATE` stays high until `PWR_OK` is asserted. When
  `PWR_OK` is asserted, the PMU sets `PWR_STATE` low.
- A falling edge on `PWR_SW` while off turns PB0 on immediately, pulling ATX
  `PS_ON#` low to start the PSU. `PWR_STATE` stays high until `PWR_OK` is
  asserted.
- When the system is already powered and the user presses `PWR_SW`, the PMU
  sets `PWR_STATE` high so the IO Controller can finish its shutdown
  work.
- The PMU waits for the IO Controller to assert `PWR_OFF_RQ` low before
  shutting off the PSU in the normal shutdown path.
- If the system is already powered and `PWR_SW` is held for 5 seconds, the
  PMU turns PB0 off directly, disabling the PSU without waiting for the IO
  Controller.
- Holding `PWR_OFF_RQ` low turns PB0 off, disabling the MOSFET and allowing the
  ATX supply to turn off.

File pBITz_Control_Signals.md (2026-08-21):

# pBITz Control Signal Conventions

This document defines the **logical meaning and recommended use of the pBITz control and device-selection signals**.

It intentionally does **not** define connector pin numbers, connector rows, PCB routing, pull-up component values, or other connector-specific implementation details. Those belong in the pBITz Backplane Architecture documentation and the KiCad design files.

The purpose of the pBITz signal convention is to make expansion cards as reusable as practical across machines built around different CPU and bus families. In particular, simple video, sound, storage, and I/O cards should see a familiar peripheral-facing bus even when the CPU itself does not natively provide Z80-style `/RD`, `/WR`, `/MREQ`, or `/IORQ` signals.

The guiding principle is:

> **CPU boards translate their native bus into pBITz transaction semantics; expansion cards should not need to understand the CPU that is driving the backplane.**

This is a compatibility convention rather than an attempt to force every processor into an identical bus architecture. Some CPU-specific signals have no useful cross-family equivalent and are therefore optional or reserved.

---

## 1. Design goals

The control-signal map is intended to provide four things:

1. **A stable peripheral interface.** Common cards should be able to depend on reset, read, write, device-select, wait-state, and interrupt semantics without caring which CPU family is installed.
2. **A natural mapping for simple 8-bit CPUs.** A Z80-like bus can expose most of the core pBITz controls directly.
3. **A normalization target for other buses.** Memory-mapped CPUs, 16/32-bit CPUs, and MCU/SoC external buses can use glue logic to synthesize the same peripheral-facing controls.
4. **Room for family-specific extensions.** Signals with no meaningful common semantic are not forced into false equivalence merely to fill the connector.

The CPU board, or the glue logic associated with it, is therefore responsible for generating canonical pBITz transactions when the native processor bus does not already provide them.

---

## 2. Naming, polarity, and idle state

The physical control signals remain named `CTRL_0` through `CTRL_19`.

This document assigns semantic names such as `/RD` or `/WAIT` to those signals for discussion. A leading `/` means **active low**.

The four device-selection lines are named `CS0` through `CS3` and are treated collectively as the 4-bit device-select address `CS[3:0]`. They are described separately from the `CTRL_*` block because they encode **which peripheral is being addressed**, rather than the type or phase of the bus transaction.

Unless a machine-specific extension explicitly says otherwise, expansion cards should interpret the canonical controls according to the semantics in this document rather than according to the native signal name of any particular CPU.

### Backplane pull-ups

The pBITz backplane provides pull-ups on the shared **control, device-select, address, and data lines**. This includes:

- `CTRL_*`;
- `CS[3:0]`;
- the address bus; and
- the data bus.

The backplane does **not** provide these general pull-ups on the clock signals or on the SPI/service-bus signals.

This gives the ordinary parallel bus a defined high idle state when a driver is inactive, in reset, or has released the bus. Card designs should take this into account and should not add strong conflicting bias networks to these shared lines without a specific reason.

The exact pull-up implementation and resistor values remain a backplane electrical-design detail and belong in the Backplane Architecture and KiCad design rather than in this logical signal convention.

---

## 3. Canonical control map

| pBITz signal | Canonical role | Direction relative to CPU board | Portability | Notes |
| --- | --- | --- | --- | --- |
| `CTRL_0` | `/RESET` | System → cards/CPU | **Core** | Shared system reset. Low means reset asserted. |
| `CTRL_1` | `/RD` | CPU → card | **Core** | Peripheral read strobe. Low means the selected target must drive read data. |
| `CTRL_2` | `/WR` | CPU → card | **Core** | Peripheral write strobe. Low means the selected target should capture write data. |
| `CTRL_3` | `/MREQ` | CPU → card | Common | Memory-space transaction qualifier. May be synthesized on CPUs with only memory-mapped I/O. |
| `CTRL_4` | `/IORQ` | CPU → card | Common | I/O-space transaction qualifier. May be synthesized from an address aperture on CPUs with no native I/O space. |
| `CTRL_5` | Primary CPU cycle/status | CPU → card | Family-specific | Directly useful on buses with an instruction/special-cycle qualifier. Portable cards should not require it. |
| `CTRL_6` | Reserved family status | — | Reserved | Available for family-specific status such as refresh if a future design requires it. |
| `CTRL_7` | `/HALT` or CPU-stop status | Normally CPU → card | Family-specific | Indicates a stopped/halted CPU where the processor provides a useful status output. Direction and semantics are not portable across all families. |
| `CTRL_8` | `/BYTE_HI` | CPU → card | 16-bit extension | Recommended upper-byte lane qualifier for `D15..D8`. Unused by an 8-bit bus master. |
| `CTRL_9` | `/BYTE_LO` | CPU → card | 16-bit extension | Recommended lower-byte lane qualifier for `D7..D0`. Unused by an 8-bit bus master. |
| `CTRL_10` | `/BUSREQ` | Bus master/card → CPU | DMA extension | Requests that the CPU release the bus. Native arbitration may require glue logic. |
| `CTRL_11` | `/BUSACK` | CPU → bus master/card | DMA extension | Indicates that the CPU-side bridge has granted/released the bus. |
| `CTRL_12` | `/WAIT` | Card → CPU | **Core optional** | Low means the current transaction must be extended because the selected target is not ready. |
| `CTRL_13` | Reserved | — | Reserved | Intentionally unassigned. Suitable for a future cross-family function only when a real requirement exists. |
| `CTRL_14` | `/IRQ` | Card → CPU | **Core optional** | Normal maskable interrupt request. CPU-side glue converts this to the processor's native interrupt mechanism. |
| `CTRL_15` | `/NMI` | Card → CPU | Common optional | Highest-priority/non-maskable interrupt request where the CPU architecture supports such a concept. |
| `CTRL_16` | Secondary interrupt / family extension | Card → CPU | Optional | Reserved for a useful secondary interrupt class, such as a fast interrupt, when a machine defines one. Portable cards should not require it. |
| `CTRL_17` | Reserved | — | Reserved | No portable interrupt-chain or vectoring semantic is currently assigned. |
| `CTRL_18` | Reserved | — | Reserved | No portable interrupt-chain or vectoring semantic is currently assigned. |
| `CTRL_19` | `/CS_CART` | CPU/decode → card | Platform optional | Dedicated cartridge/boot-ROM select generated by machine decode when that feature exists. It is separate from the normal `CS[3:0]` device-select address. |

### Core peripheral subset

A simple reusable 8-bit peripheral should ideally need only:

- its normal address and data lines;
- the `CS[3:0]` device-select address;
- `CTRL_0` (`/RESET`);
- `CTRL_1` (`/RD`);
- `CTRL_2` (`/WR`);
- optionally `CTRL_12` (`/WAIT`); and
- optionally `CTRL_14` (`/IRQ`).

This is the preferred compatibility target for video, sound, and other register-oriented cards.

A card that is fully qualified by its decoded device-select generally does **not** need to depend on `/MREQ` or `/IORQ`. This is desirable because it allows the CPU board to choose whether a peripheral appears in native I/O space, a memory-mapped compatibility aperture, or another MMU-defined region.

---

## 4. Transaction and device-selection semantics

### 4.1 `/RD` and `/WR` are peripheral strobes, not raw CPU pins

`CTRL_1` and `CTRL_2` are deliberately defined as separate active-low transaction strobes even though many processors expose only a single `R/W` signal.

The CPU-side glue must generate clean pBITz `/RD` and `/WR` strobes qualified by the processor's valid-bus-cycle timing.

This is important for card reuse: a peripheral designed around `/RD` and `/WR` should not need alternate logic merely because the host CPU happens to use `R/W`, `/AS`, `E`, or some other bus-cycle convention.

### 4.2 `/MREQ` and `/IORQ` describe address spaces

Some CPUs provide distinct memory and I/O cycles; others are entirely memory mapped.

For a CPU with native memory and I/O strobes, `CTRL_3` and `CTRL_4` can map naturally to those cycles.

For a memory-mapped CPU, the CPU board may reserve an address region as a **pBITz I/O aperture** and generate:

- `CTRL_4` (`/IORQ`) for accesses inside that aperture; and
- `CTRL_3` (`/MREQ`) for ordinary memory-space accesses.

This lets a card that genuinely requires an I/O-cycle qualifier remain reusable on a memory-mapped processor.

Simple cards should still prefer the standard decoded device-select mechanism where possible and avoid depending on the distinction.

### 4.3 `CS[3:0]` is a device address, not four one-hot chip selects

The pBITz device-selection mechanism separates **device selection** from **device-internal address decoding**.

The CPU-side I/O decoder, MMU, or equivalent glue first determines whether the current CPU access represents a valid pBITz peripheral transaction. When it does, the normal address bus is presented as usual **and** the CPU-side decode logic drives a 4-bit device address on `CS[3:0]`.

The encoding is:

| `CS[3:0]` | Meaning |
| --- | --- |
| `0000` | No pBITz device selected; reserved and invalid as a card address |
| `0001`–`1111` | Device address 1–15 selected |

Thus pBITz supports up to **15 normal device addresses** through this first-stage decode.

On an expansion card, the usual implementation is:

1. decode or compare `CS[3:0]` against the card's configured device address;
2. generate a local card-select signal when the values match; and
3. use the ordinary address lines for any required register, port, memory-window, or sub-device decoding within that card.

The device address is commonly configured with a small DIP switch, rotary hexadecimal/BCD-style switch, jumper field, or equivalent configuration mechanism. **Device address `0000` must never be assigned to a card.** It is the actively driven "no pBITz device selected" value, not a disabled or tri-stated condition.

This distinction is important because `CS[3:0]` is driven push-pull by the CPU-side decode logic. During cycles that are not valid pBITz peripheral accesses—including ordinary memory cycles—the decode logic drives `CS[3:0] = 0000`. A card configured to compare equal to device address zero would therefore falsely select itself on those cycles.

Conceptually:

```text
CPU address/MMU decode
        │
        ├── normal address bus ───────────────────────► card sub-decode
        │
        └── valid pBITz device number ─► CS[3:0] ───► address compare
                                                        │
                                                        └── local /CS
```

This mechanism is deliberately independent of the CPU's native I/O model. A Z80 can derive it from an `/IORQ` decode, a 6809/68k system can derive it from a memory-mapped I/O aperture, and an MCU can derive it from an external-memory-controller region. In each case, the expansion card sees the same device number.

The CPU-side decoder must drive `CS[3:0] = 0000` whenever no pBITz peripheral is selected. A non-zero device address therefore represents an explicit first-stage selection rather than requiring every card to decode the full system address map itself.

`CTRL_19` (`/CS_CART`) is a separate optional dedicated cartridge/boot-ROM select and is **not** device address 15 or otherwise part of the `CS[3:0]` namespace.

### 4.4 `/WAIT` always means "the target is not ready"

`CTRL_12` has one portable semantic:

> **Low means extend the current bus transaction.**

The CPU board must translate that request into the processor's native cycle-extension mechanism.

This distinction matters on buses such as the 68000 family. `/DTACK` is an active-low **completion/acknowledge** signal, while pBITz `/WAIT` is an active-low **hold/not-ready** signal. They therefore must not simply be treated as the same wire. A 68k CPU-side bridge should withhold `/DTACK` while pBITz `/WAIT` is asserted and complete the native transaction only when the pBITz target is ready.

### 4.5 Interrupt lines carry semantic requests

`CTRL_14` and `CTRL_15` describe interrupt classes rather than specific CPU pins.

- `CTRL_14` is the normal maskable interrupt request.
- `CTRL_15` is the highest-priority/non-maskable request when the host architecture supports one.

A CPU with encoded interrupt-priority inputs should use glue logic to convert these requests into its native interrupt representation. The pBITz lines should **not** be wired arbitrarily to individual encoded priority bits merely because the pin count happens to match.

Interrupt acknowledge cycles, vector presentation, and priority daisy chains are **not currently part of the portable pBITz control convention**. Cards that require CPU-family-specific vectoring are therefore family-aware unless a later pBITz extension standardizes a common mechanism.

---

## 5. CPU-family mapping guidance

The mappings below describe how a CPU board should normally adapt its native signals to the pBITz semantics. They are guidance for CPU-board glue design, not additional signals exposed by the backplane.

For every CPU family, the CPU-side address decoder or MMU is also responsible for producing the `CS[3:0]` device address for a valid peripheral access and `0000` when no pBITz device is selected. This first-stage device decode is intentionally kept on the CPU side so expansion cards do not need to know the host machine's full address map.

### 5.1 Z80-family buses

A Z80-style bus is close to the canonical pBITz model and requires little translation.

| pBITz signal | Z80-family mapping |
| --- | --- |
| `CTRL_0` | `/RESET` |
| `CTRL_1` | `/RD` |
| `CTRL_2` | `/WR` |
| `CTRL_3` | `/MREQ` |
| `CTRL_4` | `/IORQ` |
| `CTRL_5` | `/M1` |
| `CTRL_6` | Normally unused; `/RFSH` is a possible family-specific use if ever required |
| `CTRL_7` | `/HALT` |
| `CTRL_8` | Unused on an 8-bit implementation |
| `CTRL_9` | Unused on an 8-bit implementation |
| `CTRL_10` | `/BUSREQ` |
| `CTRL_11` | `/BUSACK` |
| `CTRL_12` | `/WAIT` |
| `CTRL_13` | Reserved |
| `CTRL_14` | `/INT` |
| `CTRL_15` | `/NMI` |
| `CTRL_16` | Unused / family extension |
| `CTRL_17` | Reserved |
| `CTRL_18` | Reserved |
| `CTRL_19` | `/CS_CART`, generated by address decode if supported |

For ordinary peripherals, the I/O decoder can use the Z80 address and `/IORQ` cycle to produce the appropriate `CS[3:0]` device number. The card then needs only the device-select code plus whatever low-order address bits it uses internally.

`/M1` is useful as a native Z80 status signal, but portable expansion cards should not assume that another CPU family can reproduce its exact semantics.

The pBITz convention does **not** currently require the Z80 `IEI`/`IEO` daisy chain to be carried by `CTRL_17` and `CTRL_18`. A physical interrupt-priority chain is topology-sensitive and should not be implied by two ordinary shared control signals.

### 5.2 6809 / 6309-family buses

The 6809/6309 family is memory mapped and uses `R/W` rather than separate read and write strobes. CPU-side glue should therefore normalize the bus before presenting it to pBITz.

Recommended behaviour:

- Generate `CTRL_1` (`/RD`) and `CTRL_2` (`/WR`) from `R/W`, qualified by the valid portion of the processor bus cycle.
- Generate `CTRL_3` (`/MREQ`) from the processor's valid-memory-cycle timing.
- If I/O-space compatibility is desired, reserve an address aperture and generate `CTRL_4` (`/IORQ`) when that aperture is accessed.
- Decode that aperture into `CS[3:0]` device numbers so normal pBITz cards do not need to decode the machine's full memory map.
- Do not force an approximate instruction-cycle signal onto `CTRL_5` merely to imitate `/M1`; leave it unused unless a machine has a genuine use for family-specific cycle status.
- Treat `CTRL_7` cautiously. The native `HALT` function on this family is primarily a CPU-control input, not a portable equivalent of the Z80 `/HALT` status output.
- Translate `CTRL_10`/`CTRL_11` into the family's bus-release mechanism. A typical implementation can use HALT/bus-control logic for the request and BA/BS-derived state to determine when the bus is actually available.
- Translate `CTRL_12` to the processor's memory-ready or cycle-stretching mechanism.
- Map `CTRL_14` to `/IRQ` and `CTRL_15` to `/NMI`.
- `CTRL_16` is a natural candidate for `/FIRQ` on a machine that chooses to use the optional secondary-interrupt convention, but a portable card must not assume it is present.
- `CTRL_8` and `CTRL_9` remain unused on the native 8-bit bus.

### 5.3 65xx / 65816-family buses

65xx-family processors are also memory mapped and expose `R/W` rather than separate peripheral strobes.

Recommended behaviour:

- Generate pBITz `/RD` and `/WR` from `R/W` and the valid phase of `PHI2`.
- On a 65816, use `VDA`/`VPA` as appropriate to ensure that pBITz transactions are generated only for valid external address cycles.
- Generate `CTRL_4` (`/IORQ`) from an address-decoded I/O aperture when compatibility with I/O-space peripherals is useful; otherwise peripherals may simply remain memory mapped and use `CS[3:0]` as their first-stage selection.
- Decode the chosen I/O/peripheral region into `CS[3:0]` device numbers 1–15.
- `VPA` may be useful internally to CPU glue, but it is not an exact replacement for Z80 `/M1` and should not be treated as a portable `CTRL_5` semantic.
- Translate pBITz `/WAIT` into the native `RDY` mechanism.
- Map `CTRL_14` and `CTRL_15` to the native maskable and non-maskable interrupt inputs where available.
- The 65816 has an 8-bit external data bus despite its 16-bit CPU architecture, so `CTRL_8` and `CTRL_9` are normally unused.
- Bus mastering on parts with a bus-enable facility should still be mediated by CPU-side glue so `CTRL_10` means **request ownership** and `CTRL_11` means **ownership has actually been granted**. CPU-specific lock/state signals must be respected before the grant is issued.

The 65816 `ABORT` input has no current portable pBITz control assignment. It should not be silently mapped onto a reserved control line without first defining a platform-wide bus-fault semantic.

### 5.4 68000 / 68010-family buses

The 68000 family differs more substantially from an 8-bit peripheral bus, but its asynchronous bus can be translated cleanly by CPU-side glue.

Recommended behaviour:

- Derive `CTRL_1` (`/RD`) and `CTRL_2` (`/WR`) from `/AS`, `R/W`, and the active byte-lane strobes. Do **not** expose the raw `R/W` line as though it were pBITz `/WR`.
- Generate `CTRL_3` (`/MREQ`) for ordinary pBITz memory transactions.
- Since the 68000 has memory-mapped I/O, generate `CTRL_4` (`/IORQ`) from a reserved pBITz I/O aperture if I/O-space card compatibility is desired.
- Decode that aperture into `CS[3:0]`, leaving the card to use only its local address bits for sub-decoding.
- For a native 16-bit pBITz transfer, map `CTRL_8` to the upper-byte lane and `CTRL_9` to the lower-byte lane. On a 68000/68010 these correspond naturally to `/UDS` and `/LDS` respectively.
- For reusable 8-bit cards on `D7..D0`, the CPU-side bridge/address decode should hide the 68000's byte-lane and odd/even-address details from the card whenever practical.
- Map the arbitration request toward `/BR`; generate the pBITz `/BUSACK` semantic only when the native grant/acknowledge sequence has actually made the bus available.
- Do **not** connect pBITz `/WAIT` directly to `/DTACK`. The CPU-side state machine should delay `/DTACK` while the selected pBITz target asserts `/WAIT`.
- Convert pBITz interrupt requests into the native encoded `/IPL[2:0]` levels. A normal `/IRQ` may be assigned a machine-defined interrupt level; pBITz `/NMI` can be represented by the architecture's highest-priority interrupt level when appropriate.
- Native interrupt-acknowledge cycles and autovector/vector-device behaviour remain CPU-family glue concerns unless a future pBITz extension standardizes them.

### 5.5 68020 / 68030-family buses

Later 68k processors should generally be treated as requiring a **bus bridge**, not a collection of one-to-one signal substitutions.

Their wider buses and transfer-size/acknowledge conventions should be translated into the canonical pBITz transaction model:

- separate `/RD` and `/WR` peripheral strobes;
- the pBITz memory/I/O-space convention;
- CPU/MMU first-stage decode into the `CS[3:0]` device address;
- appropriate `CTRL_8`/`CTRL_9` byte-lane qualification for the 16-bit pBITz data path;
- `/WAIT` translated into the CPU's native acknowledge/termination mechanism;
- bus arbitration translated into pBITz `/BUSREQ` and `/BUSACK`; and
- interrupt requests encoded into the CPU's native priority inputs.

A 32-bit CPU board may use only a 16-bit portion of the pBITz data bus for expansion cycles or may implement lane steering in glue logic. That is a CPU-board implementation detail; expansion cards should continue to see the same pBITz semantics.

### 5.6 Other external-memory buses and MCU/SoC buses

A processor does not need to resemble any of the classic buses above to participate in pBITz.

An MCU or SoC with an asynchronous external-memory controller can normally provide the canonical interface by translating its native chip-select, read, write, wait/ready, and interrupt mechanisms in glue logic.

The same rules apply:

- expose clean peripheral-facing `/RD` and `/WR` strobes;
- synthesize `/IORQ` from an address aperture when useful;
- map native address regions or chip-selects into the portable `CS[3:0]` device-address namespace;
- preserve the pBITz `/WAIT` meaning rather than copying a native acknowledge signal with opposite polarity/semantics; and
- hide native interrupt encoding and bus-width details from ordinary expansion cards.

---

## 6. Card compatibility profiles

The following informal profiles help card designers decide how portable a design is likely to be.

### Profile A — Simple peripheral

Uses `CS[3:0]` device selection, `CTRL_0`, `CTRL_1`, and `CTRL_2`, plus address/data lines.

The card compares `CS[3:0]` against its configured device address and uses only the address bits needed for its own internal register or memory map. Valid configured device addresses are `0001` through `1111`; `0000` is reserved for "no device selected" and must not be used by a card.

Optional use of `CTRL_12` and `CTRL_14` is still considered highly portable.

**Typical examples:** sound generators, register-based video devices, UART-like peripherals, simple storage interfaces.

This is the preferred profile for maximum Coffee-series reuse.

### Profile B — Address-space-aware peripheral

Adds `CTRL_3` and/or `CTRL_4` because the device needs to distinguish memory and I/O transactions in addition to its `CS[3:0]` selection.

This remains portable, but memory-mapped CPU boards may need to synthesize the distinction.

### Profile C — 16-bit peripheral

Adds `CTRL_8` and `CTRL_9` for byte-lane qualification.

The card should still use canonical `/RD` and `/WR` semantics and `CS[3:0]` device selection rather than depending on a native 68k-style bus cycle.

### Profile D — Bus master / DMA device

Adds `CTRL_10`, `CTRL_11`, and usually `CTRL_12`.

The CPU board is responsible for translating the request/grant handshake into its processor's native arbitration protocol.

### Profile E — CPU-family-aware device

Depends on `CTRL_5`, `CTRL_6`, `CTRL_7`, `CTRL_16`, or future assignments of the reserved controls.

Such a card may still be useful, but it should be documented as requiring a particular CPU-family capability rather than presented as a generally portable pBITz peripheral.

---

## 7. Reserved controls and future extensions

A reserved `CTRL_*` line should remain reserved until a requirement exists on more than one design or there is a strong compatibility reason to standardize it.

In particular:

- `CTRL_6` is **not automatically `/RFSH`** simply because a Z80 can provide that signal.
- `CTRL_13` is intentionally available for a future cross-family function such as bus fault/abort handling, but no such semantic is currently standardized.
- `CTRL_17` and `CTRL_18` are **not automatically Z80 `IEI`/`IEO`**. Interrupt priority chains have physical topology requirements that are distinct from assigning two shared connector signals.

When a new assignment is proposed, the preferred question is not "what unused CPU pin can go here?" but:

> **What peripheral-facing function would make a useful card portable across more than one CPU family?**

That keeps the pBITz control block focused on compatibility rather than on reproducing the pinout of whichever CPU board happened to be designed first.

---

## 8. Source of truth

This document is the source of truth for the **logical convention** associated with `CTRL_0` through `CTRL_19`, the `CS[3:0]` device-selection convention, and the platform-level shared-bus idle/pull-up rule.

It is **not** the source of truth for physical connector locations or the component-level implementation of the pull-ups. Physical signal placement, connector orientation, power pins, ground pins, resistor values, clocks, SPI wiring, and other electrical implementation details belong to the current pBITz backplane schematic and Backplane Architecture document.

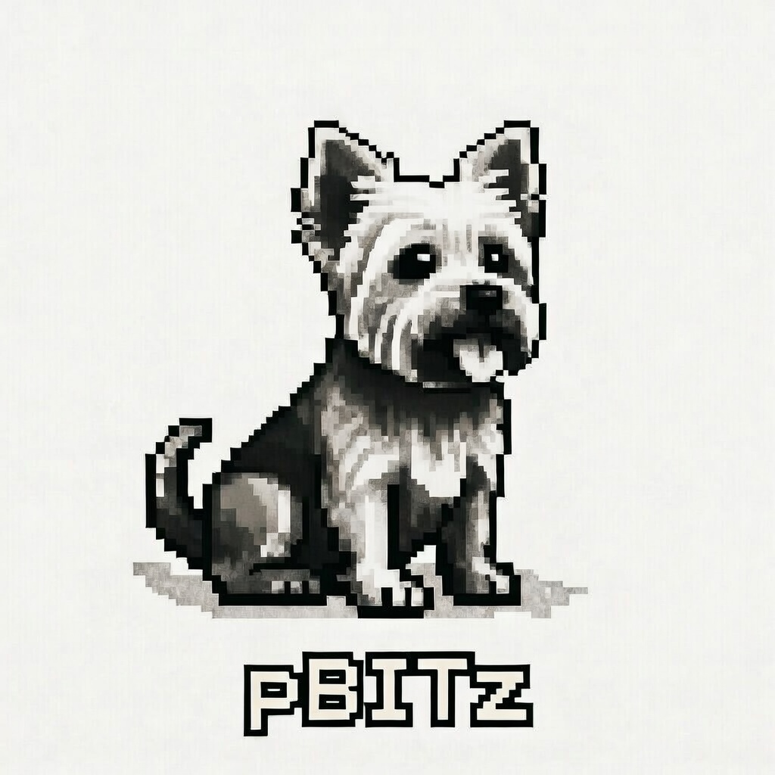
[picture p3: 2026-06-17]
pBITz-HiC.jpg

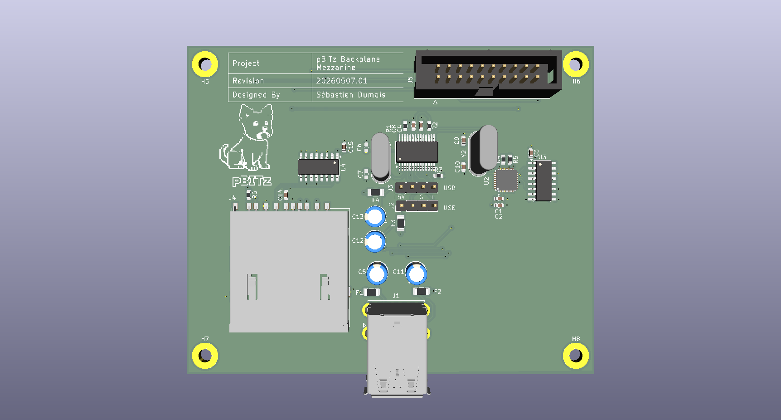
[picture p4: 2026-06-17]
pBITzBackplaneMezzanine/pBITzBackplaneMezzanine.png

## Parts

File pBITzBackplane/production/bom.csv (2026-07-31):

Designator | Footprint | Quantity | Value | LCSC Part #
C1, C10, C11, C12, C13, C14, C15, C16, C17, C8, C9 | 1206 | 11 | 100n
C2, C4, C6 | CP_Radial_D5.0mm_P2.00mm | 3 | 100u
C3, C5, C7 | CP_Radial_D5.0mm_P2.00mm | 3 | 47u
J1 | MOLEX_39281243 | 1 | ATX-24
J10, J11, J8, J9 | AMPHENOL_86093968114T55F1LF | 4 | ~
J6 | SAMTEC_PCIE-098-02-X-D-RA | 1 | pBITzBus
J7 | IDC-Header_2x10_P2.54mm_Vertical | 1 | Conn_02x10_Odd_Even
Q1 | SOT-23 | 1 | BSS138
R1, R5, R6, R8 | 1206 | 4 | 10k
R19, R20 | 1206 | 2 | 4k7
RN10, RN5, RN6, RN7, RN8, RN9 | R_Array_SIP14 | 6 | 4614X-101-472LF
U1 | DIP-8_W7.62mm | 1 | ATtiny85-20P

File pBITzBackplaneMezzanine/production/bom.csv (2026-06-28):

Designator | Footprint | Quantity | Value | LCSC Part #
C1, C16 | 0603 | 2 | 1u
C10, C6, C7, C9 | 0603 | 4 | 22p
C11, C12, C13, C5 | CP_Radial_D5.0mm_P2.50mm | 4 | 100u
C14, C15, C2, C3 | 0603 | 4 | 100n
C4, C8 | 0603 | 2 | 10u
F1, F2, F3, F4 | 1206 | 4 | 1206L050YR
J1 | USB3_A_Molex_48406-0001_Horizontal_Stacked | 1 | USB3_A_Stacked
J2, J3 | PinHeader_1x04_P2.54mm_Vertical | 2 | Conn_01x04
J4 | AMPHENOL_10067847-001RLF | 1 | 10067847-001RLF
J5 | IDC-Header_2x10_P2.54mm_Vertical | 1 | Conn_02x10_Odd_Even
R1, R2 | 0603 | 2 | 100k
R3 | 0603 | 1 | 2k7
R4, R5 | 0603 | 2 | 33
R6, R7 | 0603 | 2 | 10k
U1 | SSOP-28_5.3x10.2mm_P0.65mm | 1 | FE1.1S-BSOP28BCN
U2 | QFN50P500X500X80-33N | 1 | MAX3421EETJ_T
U3, U4 | SOIC-16_3.9x9.9mm_P1.27mm | 2 | CD74HC4050M96
Y1, Y2 | Crystal_HC49-U_Vertical | 2 | ABL-12.000MHZ-B2

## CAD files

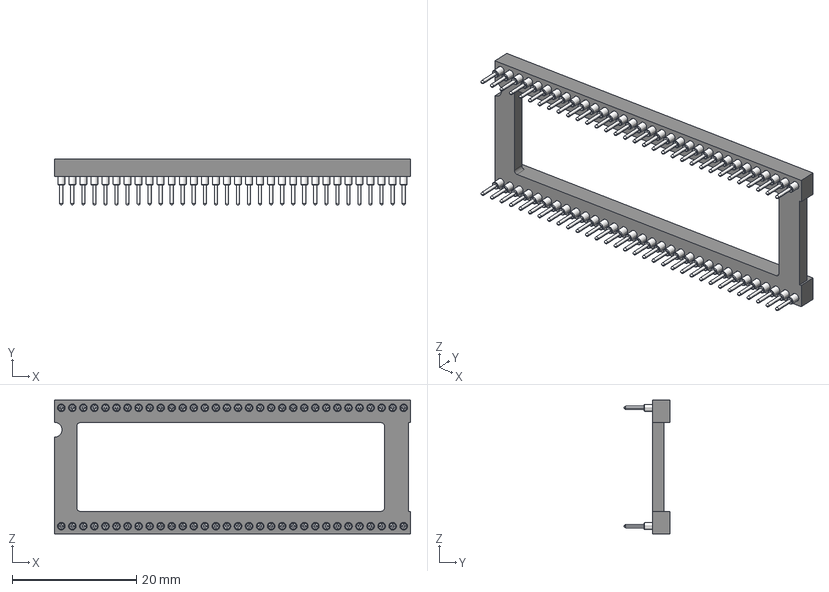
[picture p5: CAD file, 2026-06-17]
99-KiCad-Lib/3D-Models/D8864-42_asm.stp
57.3 x 7.40 x 21.5 mm
D8864-MOULD
D8864-SHELL x 64
D8864-CLIP x 64

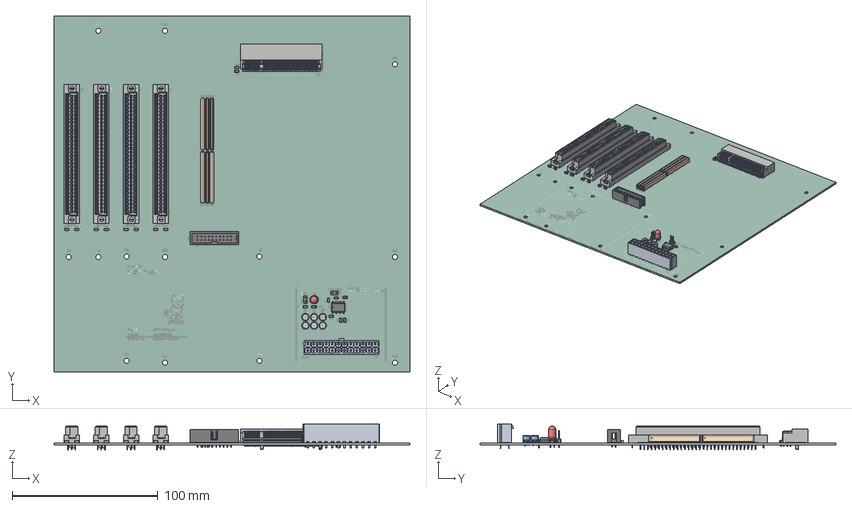
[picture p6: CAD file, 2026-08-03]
pBITzBackplane/pBITzBackplane.step
243.8 x 243.8 x 17.5 mm
R_Array_SIP14 x 6
SOT-23
C_1206_3216Metric x 11
LED_D5.0mm
CP_Radial_D50mm_P200mm x 6
DIP-8_W7.62mm
PinHeader_1x02_P254mm_Vertical
R_1206_3216Metric x 6
86093968114T55F1LF x 4
IDC_Header_2x10_P254mm_Vertical
PinHeader_2x01_P254mm_Vertical
PCIE-098-02-F-D-RA_body
PCIE-098-02-F-D-RA_pins1
PCIE-098-02-F-D-RA_pins2
pBITzBackplane-unsaved-export-sTe9Gk_silkscreen
pBITzBackplane-unsaved-export-sTe9Gk_soldermask x 2
pBITzBackplane-unsaved-export-sTe9Gk_PCB

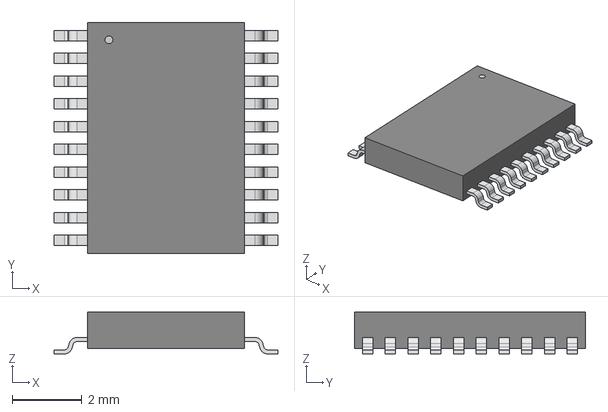
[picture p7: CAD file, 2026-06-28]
99-KiCad-Lib/3D-Models/RU_20_ADI.step
6.40 x 6.60 x 1.20 mm

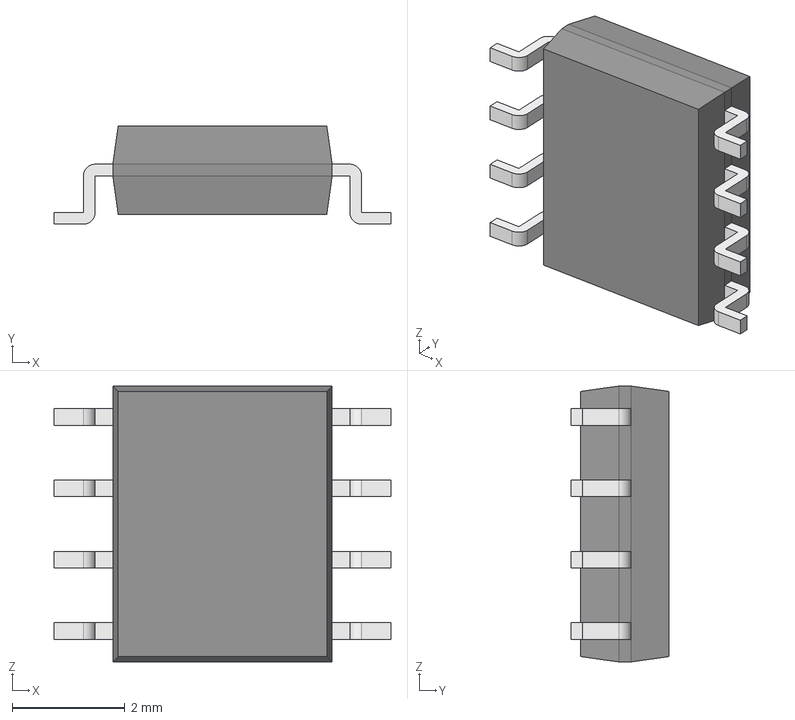
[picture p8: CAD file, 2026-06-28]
99-KiCad-Lib/3D-Models/LM4871MX_NOPB.step
5.99 x 1.75 x 4.91 mm
Body001 (Mirror #1) x 4
XY-plane x 12
X-axis x 12

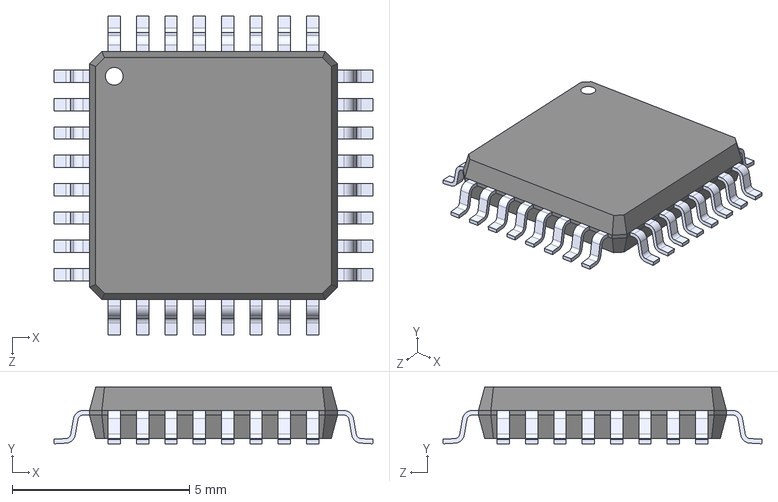
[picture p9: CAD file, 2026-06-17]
99-KiCad-Lib/3D-Models/TUSB2046BVFR.step
9.00 x 1.60 x 9.00 mm

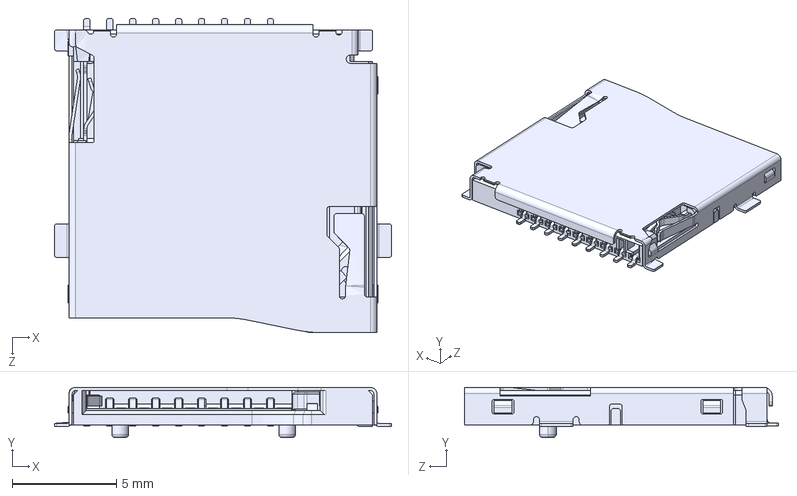
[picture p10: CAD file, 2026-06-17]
99-KiCad-Lib/3D-Models/MSD-1-A.step
16.1 x 2.40 x 15.0 mm

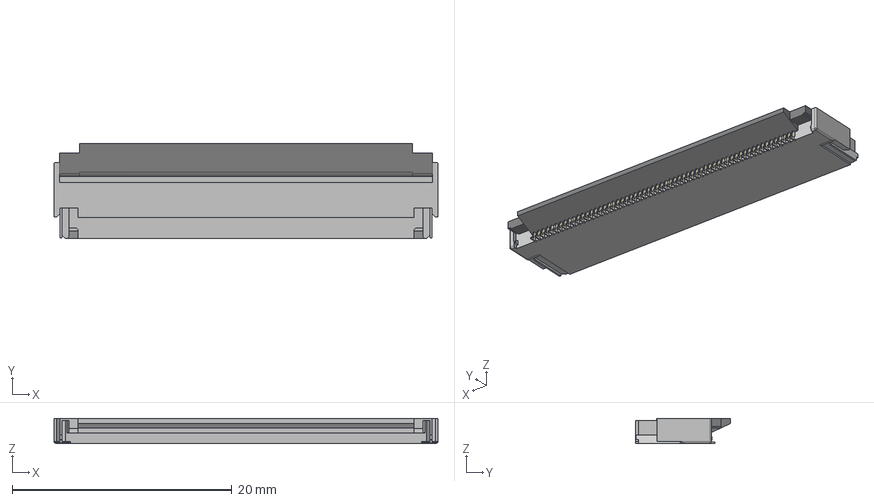
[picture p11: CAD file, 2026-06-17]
99-KiCad-Lib/3D-Models/fh69-60s-0_5sh.step
35.0 x 8.68 x 2.30 mm

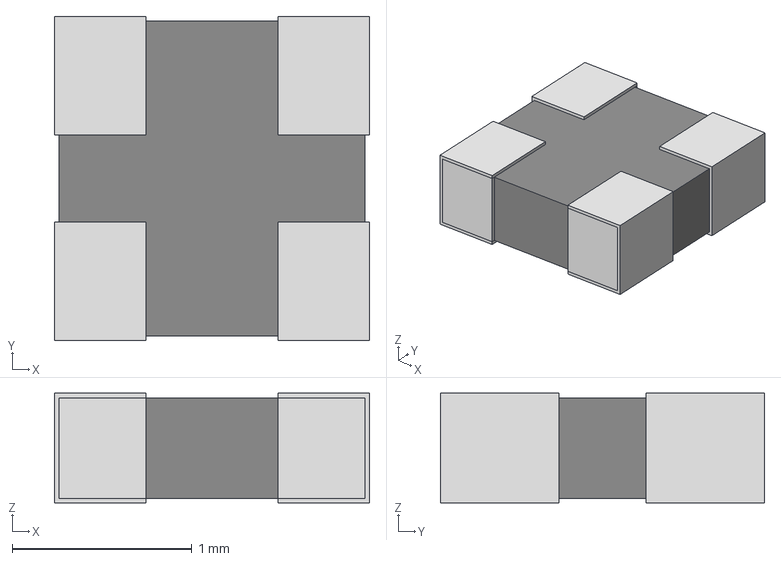
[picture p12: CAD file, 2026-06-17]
99-KiCad-Lib/3D-Models/C_ARRAY_EXB34V_PAN.step
1.75 x 1.80 x 0.61 mm

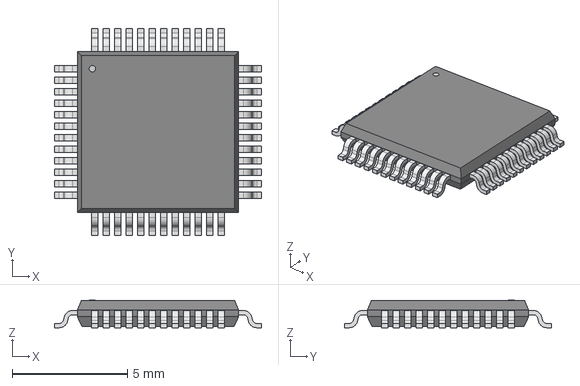
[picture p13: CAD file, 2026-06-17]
99-KiCad-Lib/3D-Models/TQFP48_PT_MCH.step
8.99 x 8.99 x 1.20 mm

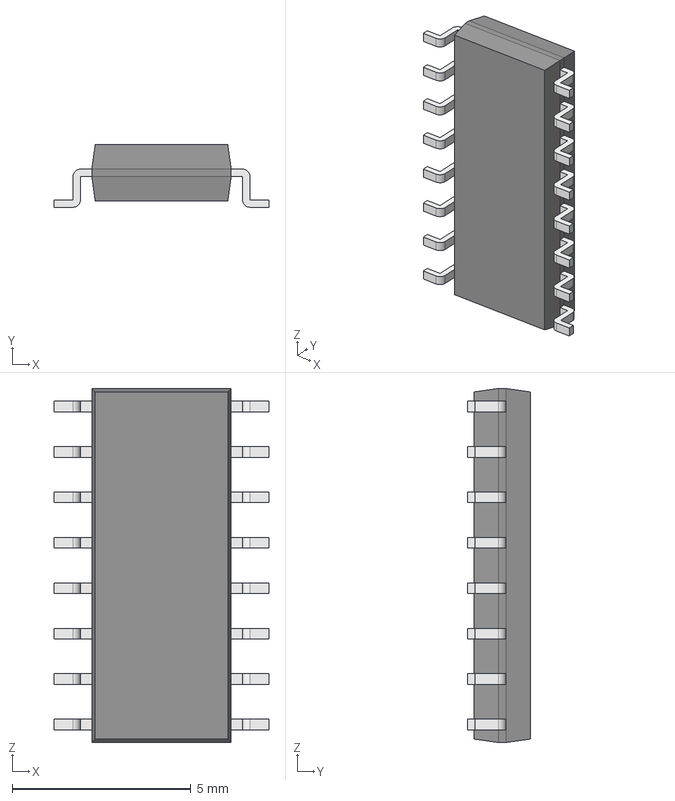
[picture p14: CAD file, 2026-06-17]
99-KiCad-Lib/3D-Models/CD74HC4050M96.step
6.00 x 1.75 x 9.90 mm
Body001 (Mirror #1) x 8
XY-plane x 12
X-axis x 12

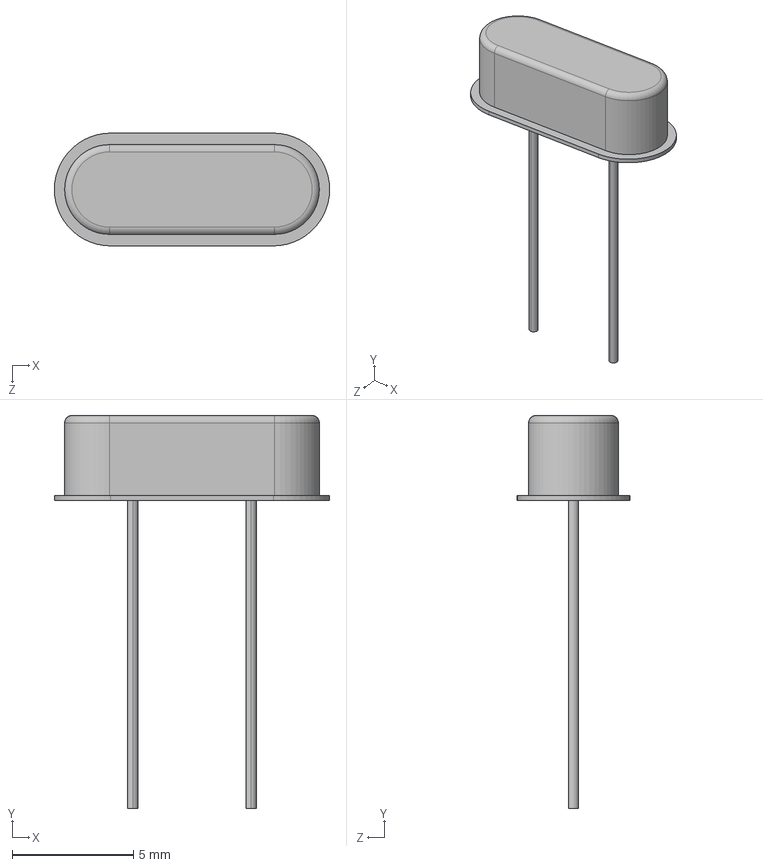
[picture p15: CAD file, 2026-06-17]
99-KiCad-Lib/3D-Models/ECS-221-S-4X.step
11.3 x 16.2 x 4.65 mm

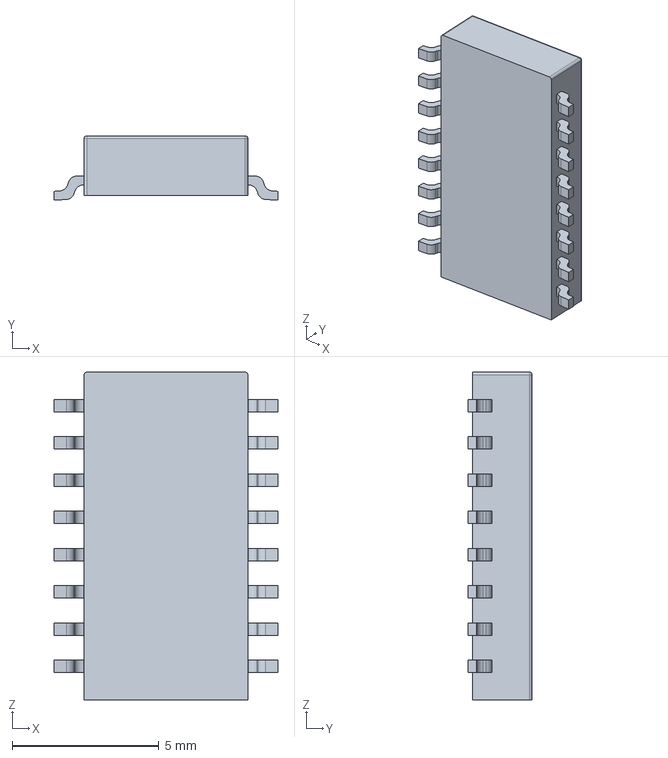
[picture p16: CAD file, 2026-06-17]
99-KiCad-Lib/3D-Models/4816p.stp
7.62 x 2.20 x 11.2 mm

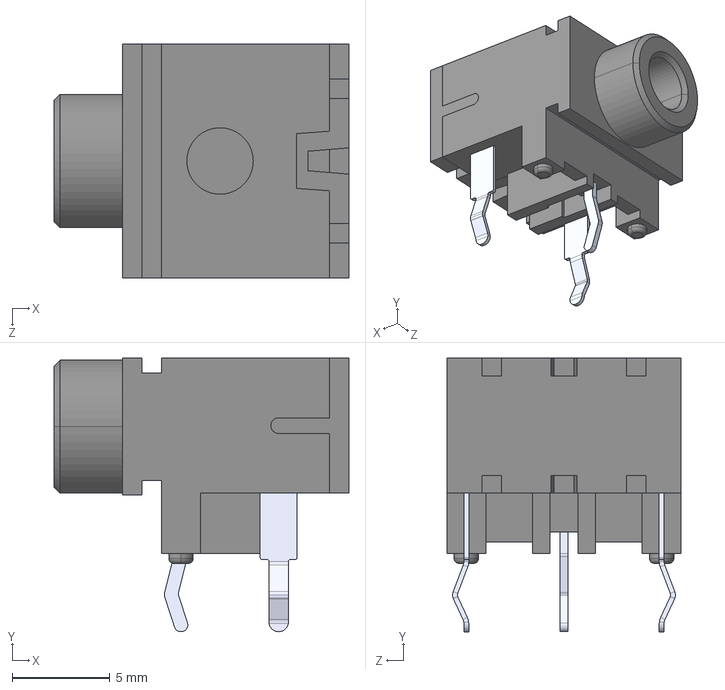
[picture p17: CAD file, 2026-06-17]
99-KiCad-Lib/3D-Models/STX-3120-3B.step
15.1 x 14.0 x 12.0 mm

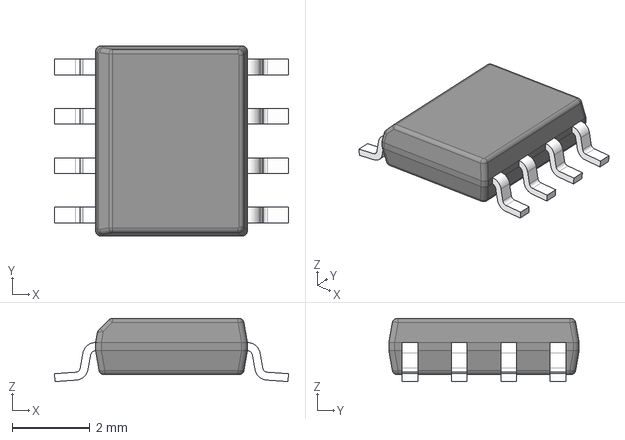
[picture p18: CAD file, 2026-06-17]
99-KiCad-Lib/3D-Models/D0008A.stp
6.02 x 4.90 x 1.63 mm
BODY-SO
LEAD-D0008A x 8

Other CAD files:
99-KiCad-Lib/3D-Models/FT230XS-U.step
99-KiCad-Lib/3D-Models/EXB-2HV330JV.STEP
99-KiCad-Lib/3D-Models/TSOP-44_MIL400_ALL.step
99-KiCad-Lib/3D-Models/4820p.stp
99-KiCad-Lib/3D-Models/039281243.stp
99-KiCad-Lib/3D-Models/1-2199300-2.STEP
99-KiCad-Lib/3D-Models/10018783-10202TLF.step
99-KiCad-Lib/3D-Models/10067847-001RLF.step
99-KiCad-Lib/3D-Models/39281243.step
99-KiCad-Lib/3D-Models/484060001.stp
99-KiCad-Lib/3D-Models/548190519.stp
99-KiCad-Lib/3D-Models/86093967113T55F1LF.step
99-KiCad-Lib/3D-Models/86093968114T55F1LF.step
99-KiCad-Lib/3D-Models/C_ARRAY_EXB28V_PAN.step
99-KiCad-Lib/3D-Models/D0016A.stp
99-KiCad-Lib/3D-Models/ECS-2100AX-147.4.step
99-KiCad-Lib/3D-Models/EXB-2HV330JV.step
99-KiCad-Lib/3D-Models/EXB-E10C472J.step
99-KiCad-Lib/3D-Models/LTC2954CTS8-2_TRMPBF.step
99-KiCad-Lib/3D-Models/MAX3421EETJ_T.step
99-KiCad-Lib/3D-Models/PJ-037A.step
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

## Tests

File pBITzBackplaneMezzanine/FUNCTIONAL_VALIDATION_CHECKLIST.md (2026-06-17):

# pBITzBackplaneMezzanine Functional Validation Checklist

This checklist validates the `pBITzBackplaneMezzanine` design files for
reasonable functional assurance before fabrication or bring-up. The goal is to
catch obvious gotchas that would stop the board from powering on or acting as
the intended SPI-attached USB/SD mezzanine, not to prove certification readiness
or remove all possible risk.

Out of scope:

- Mechanical fit, dimensions, connector keying, mounting, and enclosure fit.
- DRC/ERC closure.
- Power-budget/current-capacity analysis.
- Firmware/software behavior for MAX3421E, SD-card protocol, or host drivers.
- Physical-board continuity, powered voltage measurements, and bench bring-up.

Authority rule: the schematic and KiCad schematic netlist are authoritative. If
`kicad_nettrace.py` disagrees with the schematic, the schematic wins.

## 1. Source And Artifact Setup

- [ ] Confirm the active root schematic is `pBITzBackplaneMezzanine.kicad_sch`.
- [ ] Confirm the active hierarchy contains only `USBPorts.kicad_sch`, `MezzanineConnector.kicad_sch`, and `SD_Card.kicad_sch`.
- [ ] Export a fresh KiCad schematic netlist:

```sh
HOME=/tmp XDG_CONFIG_HOME=/tmp XDG_DATA_HOME=/tmp kicad-cli sch export netlist -o /tmp/pbitzbackplane-mezzanine-kicad.net pBITzBackplaneMezzanine/pBITzBackplaneMezzanine.kicad_sch
```

- [ ] Run the hierarchy tracer as a secondary cross-check:

```sh
python3 Code/tools/kicad_nettrace.py pBITzBackplaneMezzanine/pBITzBackplaneMezzanine.kicad_sch
python3 Code/tools/kicad_nettrace.py pBITzBackplaneMezzanine/pBITzBackplaneMezzanine.kicad_sch --check
```

- [ ] Confirm the tracer reports no output-driver conflicts.
- [ ] Record tracer-reported opens that are resolved by the KiCad netlist as tracer limitations, not design failures.

## 2. Mezzanine Connector J5

Validate J5 as the board interface for rails, ground, SPI, interrupt, and SD
card-detect.

- [ ] Confirm `J5.1` is `+5V`.
- [ ] Confirm `J5.2` is `+3V3`.
- [ ] Confirm `J5.3` is `/MezzanineConnector/MOSI`.
- [ ] Confirm `J5.4` is `/MezzanineConnector/SPI_CS0`.
- [ ] Confirm `J5.5` is `/MezzanineConnector/MISO`.
- [ ] Confirm `J5.8` is `/MezzanineConnector/SPI_CS1`.
- [ ] Confirm `J5.9` is `/MezzanineConnector/SPI_CLK`.
- [ ] Confirm `J5.13` is `/MezzanineConnector/~{SPI_INT}`.
- [ ] Confirm `J5.17` is `/MezzanineConnector/~{SD_PRESENT}`.
- [ ] Confirm `J5.12` is intentionally unconnected.
- [ ] Confirm J5 ground pins 6, 7, 10, 11, 14, 15, 16, 18, 19, and 20 are `GND`.

Pass criteria: J5 maps exactly to the interface table in `ARCHITECTURE.md`.

## 3. Rail And Ground Distribution

Validate rail presence and support connections, not current capacity.

- [ ] Confirm `+5V` enters at `J5.1`.
- [ ] Confirm `+5V` powers FE1.1 `U1.18/VBUSM` and `U1.20/VDD5`.
- [ ] Confirm `+5V` feeds the four downstream USB VBUS fuses `F1` through `F4`.
- [ ] Confirm `+3V3` enters at `J5.2`.
- [ ] Confirm `+3V3` powers MAX3421E `U2.2/VL`, `U2.23/VCC`, and reset pin `U2.12/~{RES}`.
- [ ] Confirm `+3V3` powers U3/U4 `VCC` pins and SD socket `J4.4/VDD`.
- [ ] Confirm FE1.1 `U1.21/VD33F` generates `+3V3_INTERNAL`.
- [ ] Confirm `+3V3_INTERNAL` is used for FE1.1 support pull-ups and `U1.26/OVCJ`.
- [ ] Confirm all IC ground pins, SD ground pins, connector shields, and J5 ground pins connect to `GND`.
- [ ] Confirm `+5V`, `+3V3`, `+3V3_INTERNAL`, and `GND` are not shorted together in the schematic netlist.
- [ ] Confirm every schematic symbol intended to create the `+3V3` net uses the actual `power:+3V3` symbol identity, not a relabeled `+5V` power symbol.

Pass criteria: every required supply and ground pin is on the documented net,
and rail names remain distinct except through intended component paths.

## 4. SPI Signal Routing

Validate the host/backplane SPI wiring and local fanout.

- [ ] Confirm `MOSI` from `J5.3` reaches `U3.3` and `U4.9`.
- [ ] Confirm `U3` buffers MOSI to `/USBPorts/MOSI` and that `/USBPorts/MOSI` reaches `U2.16/MOSI`.
- [ ] Confirm `U4` buffers MOSI to `/SD_Card/MOSI` and that `/SD_Card/MOSI` reaches `J4.2/CMD`.
- [ ] Confirm `SPI_CLK` from `J5.9` reaches `U3.7` and `U4.14`.
- [ ] Confirm `U3` buffers SPI clock to `/USBPorts/CLK` and that `/USBPorts/CLK` reaches `U2.13/SCLK`.
- [ ] Confirm `U4` buffers SPI clock to `/SD_Card/CLK` and that `/SD_Card/CLK` reaches `J4.5/CLK`.
- [ ] Confirm `SPI_CS0` from `J5.4` is buffered by `U4` to `/SD_Card/~{CS}` and reaches `J4.1/DAT3/CD`.
- [ ] Confirm `SPI_CS1` from `J5.8` is buffered by `U3` to `/USBPorts/~{CS}` and reaches `U2.14/~{SS}`.
- [ ] Confirm shared MISO connects `J5.5`, `U2.15/MISO`, `J4.7/DAT0`, and `R6.2`.
- [ ] Confirm `R6` pulls shared MISO to `+3V3`.
- [ ] Confirm `U2.18/INT` reaches `J5.13`.
- [ ] Confirm `J4.CD` reaches `J5.17`.

Pass criteria: every SPI and status signal reaches the intended device pin and
no chip-select or clock line is swapped between USB and SD.

## 5. USB Host Controller And Hub

Validate MAX3421E and FE1.1 support wiring.

- [ ] Confirm MAX3421E `U2.21/D+` reaches FE1.1 `U1.16/DPU` through `R4`.
- [ ] Confirm MAX3421E `U2.20/D-` reaches FE1.1 `U1.15/DMU` through `R5`.
- [ ] Confirm `R4` and `R5` are 33 ohm series resistors.
- [ ] Confirm `U2` has a 12 MHz crystal on `XI`/`XO` and 22 pF load capacitors to ground.
- [ ] Confirm `U1` has a 12 MHz crystal on `XIN`/`XOUT` and 22 pF load capacitors to ground.
- [ ] Confirm FE1.1 `BUSJ` and `XRSTJ` are pulled to `+3V3_INTERNAL`.
- [ ] Confirm FE1.1 `REXT` has a 2.7k resistor to `GND`.
- [ ] Confirm FE1.1 `OVCJ` is held inactive by `+3V3_INTERNAL`.
- [ ] Confirm FE1.1 `DRV`, `LED1`, `LED2`, `PWRJ`, and `TESTJ` are intentionally unused or no-connected.

Pass criteria: MAX3421E can electrically talk to the FE1.1 upstream port, and
the FE1.1 support pins match the intended simplified hub design.

## 6. USB Downstream Connectors

Validate downstream VBUS and USB 2.0 D+/D- polarity.

- [ ] Confirm `F2` feeds `/USBPorts/VBUS_PIN1` to `J1.1`.
- [ ] Confirm `F1` feeds `/USBPorts/VBUS_PIN2` to `J1.10`.
- [ ] Confirm `F3` feeds `/USBPorts/VBUS_PIN3` to `J2.1`.
- [ ] Confirm `F4` feeds `/USBPorts/VBUS_PIN4` to `J3.1`.
- [ ] Confirm FE1.1 `DM1` reaches USB-A port 1 `D1-` at `J1.2`.
- [ ] Confirm FE1.1 `DP1` reaches USB-A port 1 `D1+` at `J1.3`.
- [ ] Confirm FE1.1 `DM2` reaches USB-A port 2 `D2-` at `J1.11`.
- [ ] Confirm FE1.1 `DP2` reaches USB-A port 2 `D2+` at `J1.12`.
- [ ] Confirm auxiliary header `J2` carries port 3 as `VBUS`, `DM3`, `GND`, `DP3`.
- [ ] Confirm auxiliary header `J3` carries port 4 as `VBUS`, `DM4`, `GND`, `DP4`.
- [ ] Confirm USB3 SuperSpeed pins on `J1` are intentionally unconnected.
- [ ] Confirm connector shields/drains connect to `GND`.

Pass criteria: each downstream USB 2.0 port has fused VBUS, ground, and correct
D+/D- polarity.

## 7. SD-Card Interface

Validate the SD socket in SPI mode.

- [ ] Confirm `J4.1/DAT3/CD` is `/SD_Card/~{CS}`.
- [ ] Confirm `J4.2/CMD` is `/SD_Card/MOSI`.
- [ ] Confirm `J4.5/CLK` is `/SD_Card/CLK`.
- [ ] Confirm `J4.7/DAT0` is `/MezzanineConnector/MISO`.
- [ ] Confirm `J4.4/VDD` is `+3V3`.
- [ ] Confirm `J4.3`, `J4.6`, `J4.G1`, and `J4.G2` are `GND`.
- [ ] Confirm `J4.CD` is `/MezzanineConnector/~{SD_PRESENT}`.
- [ ] Confirm `J4.8/DAT1`, `J4.9/DAT2`, and `J4.WP` are intentionally unconnected.
- [ ] Confirm SD input signals are driven from U4 3.3 V buffer outputs.

Pass criteria: the socket supports SPI-mode SD access and card detect without
unexpected extra SD-bus dependencies.

## 8. Level-Shifter Unused Gates

Validate unused 4050 channels do not float.

- [ ] Confirm U3 unused inputs are tied to `GND`.
- [ ] Confirm U3 unused outputs are intentionally unconnected.
- [ ] Confirm U4 unused inputs are tied to `GND`.
- [ ] Confirm U4 unused outputs are intentionally unconnected.
- [ ] Confirm the exact U3/U4 device variant permits 5 V inputs while powered from `+3V3`; do not accept a generic buffer whose input absolute maximum is limited to `VCC + 0.3 V`.

Pass criteria: no unused CMOS input is floating.

## 9. Intentional Opens And No-Connects

Validate that unconnected pins are intentional and limited to expected functions.

- [ ] Confirm `J5.12` is unconnected.
- [ ] Confirm USB3 SuperSpeed pins on `J1` are unconnected.
- [ ] Confirm SD `DAT1`, `DAT2`, and `WP` are unconnected.
- [ ] Confirm unused FE1.1 pins are no-connected as documented in `ARCHITECTURE.md`.
- [ ] Confirm unused MAX3421E GPIO/auxiliary pins are no-connected as documented in `ARCHITECTURE.md`.
- [ ] Confirm unused 4050 outputs are no-connected.
- [ ] Confirm MAX3421E `U2.22/VBCOMP` has an optional capacitor footprint directly to `GND`, with no series resistor.
- [ ] Confirm the VBCOMP capacitor is `DNP` by default for host-mode use, and document `1 uF ceramic` as the optional populated value.

Pass criteria: no functional connector, power, ground, USB 2.0, SPI, interrupt,
or SD-card pin is unexpectedly open.

## 10. PCB Pad-Net Agreement

Validate the PCB file agrees with the schematic netlist for functional nets.

- [ ] Confirm J5 schematic nets match J5 PCB pad nets.
- [ ] Confirm J1, J2, and J3 schematic nets match PCB pad nets.
- [ ] Confirm J4 schematic nets match PCB pad nets.
- [ ] Confirm U1, U2, U3, and U4 schematic nets match PCB pad nets.
- [ ] Confirm F1-F4 and R1-R6 schematic nets match PCB pad nets.
- [ ] Confirm crystal and load-capacitor schematic nets match PCB pad nets.

Pass criteria: no key functional component has schematic/PCB net assignment
drift.

## 11. Gotcha Review

Review the design intent at the system level after detailed connectivity checks.

- [ ] Confirm the module has no local voltage regulator for the main `+5V` or `+3V3` rails; those rails must arrive through J5.
- [ ] Confirm MAX3421E reset is held high and any reset behavior must be managed by power cycling or SPI chip reset.
- [ ] Confirm the shared MISO topology depends on inactive SPI devices tri-stating their outputs.
- [ ] Confirm the USB hub's downstream USB-A D+/D- polarity matches connector pin functions, not only net labels.
- [ ] Confirm auxiliary USB header pin order is documented for the intended harness or mating board.
- [ ] Confirm the SD-card detect polarity expected by the host/backplane matches the socket's `CD` behavior.
- [ ] Confirm all tracer limitations are resolved against the KiCad schematic netlist before accepting the result.

Pass criteria: no unresolved design-file issue remains that would obviously
prevent the mezzanine from receiving power, communicating over SPI, operating
the USB hub/controller path, or operating the SD-card path.

## 12. Cross-Board Electrical Compatibility

Validate the mezzanine together with the backplane and IO Controller. This
section catches voltage-domain and naming problems that cannot be seen by
reviewing the mezzanine schematic alone.

- [ ] Confirm J5 pad numbers and signal names agree with the matching backplane/mezzanine connector at the PCB-pad level, not only by schematic label.
- [ ] Confirm `J5.13/~{SPI_INT}` is never pulled above the MAX3421E `VL` rail (`+3V3`).
- [ ] If MAX3421E `INT` is configured open-drain, confirm there is exactly one effective pull-up to `+3V3`; no `+5V` pull-up may remain on the IO Controller or backplane.
- [ ] Confirm the IO Controller input receiving `~{SPI_INT}` recognizes a 3.3 V high while the PIC runs from 5 V; document the required PIC input-threshold/`INLVL` configuration.
- [ ] Confirm shared `MISO` has one intended idle pull-up to `+3V3` on the mezzanine.
- [ ] Confirm any upstream `MISO` pull-up to `+5V` is DNP/removed so it cannot bias the 3.3 V bus above the peripheral supply.
- [ ] Confirm both inactive SPI slaves (MAX3421E and SD card) release `MISO` when their chip selects are inactive.
- [ ] Confirm physical chip-select mapping is documented end-to-end: `SPI_CS0` selects the SD card and `SPI_CS1` selects the MAX3421E.
- [ ] Confirm IO Controller net names and firmware constants match that physical mapping; misleading names must be corrected or explicitly documented.
- [ ] Confirm all host-driven 5 V SPI signals (`MOSI`, `SPI_CLK`, and both chip selects) pass through the 3.3 V translation buffers before reaching the MAX3421E or SD card.
- [ ] Confirm no 3.3 V peripheral output is exposed to an external 5 V pull-up or actively driven 5 V source.

Pass criteria: the complete IO Controller -> backplane -> mezzanine path has no
5 V injection into 3.3 V device pins, no competing pull-ups across voltage
domains, and the physical chip-select mapping is unambiguous.

## 13. Final Acceptance

- [ ] Schematic hierarchy matches the intended active design.
- [ ] KiCad schematic netlist agrees with the architecture document.
- [ ] `kicad_nettrace.py` reports no output-driver conflicts.
- [ ] J5 interface mapping passes.
- [ ] Rail and ground distribution passes.
- [ ] SPI fanout and status routing passes.
- [ ] USB host-controller and hub support wiring passes.
- [ ] USB downstream VBUS and D+/D- polarity passes.
- [ ] SD-card interface passes.
- [ ] Intentional opens are limited to the documented list.
- [ ] PCB pad-net agreement passes for key functional parts.
- [ ] Gotcha review finds no unresolved obvious functional risk.
- [ ] Cross-board voltage-domain and pull-up checks pass for `~{SPI_INT}` and shared `MISO`.
- [ ] Physical `SPI_CS0`/`SPI_CS1` destination mapping agrees with upstream names and firmware documentation.
- [ ] VBCOMP optional-capacitor population decision is recorded (`DNP` default; `1 uF` optional).

Functional validation passes when every applicable item above is checked and
all deviations are either corrected in the design or explicitly recorded as
accepted design changes.

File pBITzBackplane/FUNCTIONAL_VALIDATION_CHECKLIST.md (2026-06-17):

# pBITzBackplane Functional Validation Checklist

This checklist validates the `pBITzBackplane` design files for reasonable
functional assurance before fabrication or bring-up. The goal is to catch
obvious gotchas that would stop the board from powering on or acting as the
intended shared bus backplane, not to prove certification readiness or remove
all possible risk.

Out of scope:

- Mechanical fit, dimensions, connector keying, mounting, and enclosure fit.
- DRC/ERC closure.
- Power-budget/current-capacity analysis.
- ATtiny firmware behavior and any external software behavior.
- Physical-board continuity, powered voltage measurements, and bench bring-up.

Authority rule: the schematic and KiCad schematic netlist are authoritative. If
`kicad_nettrace.py` disagrees with the schematic, the schematic wins.

## 1. Source And Artifact Setup

- [ ] Confirm the active root schematic is `pBITzBackplane.kicad_sch`.
- [ ] Confirm only `Power.kicad_sch` and `Backplane.kicad_sch` are in the active hierarchy.
- [ ] Confirm `ClockTree.kicad_sch` is not used for this validation.
- [ ] Export a fresh KiCad schematic netlist:

```sh
HOME=/tmp XDG_CONFIG_HOME=/tmp XDG_DATA_HOME=/tmp kicad-cli sch export netlist -o /tmp/pbitzbackplane-kicad.net pBITzBackplane/pBITzBackplane.kicad_sch
```

- [ ] Run the hierarchy tracer as a secondary cross-check:

```sh
python3 Code/tools/kicad_nettrace.py /home/kitamura/Documents/pBITzPlatform/pBITzBackplane/pBITzBackplane.kicad_sch
python3 Code/tools/kicad_nettrace.py /home/kitamura/Documents/pBITzPlatform/pBITzBackplane/pBITzBackplane.kicad_sch --check
```

- [ ] Confirm the tracer reports no output-driver conflicts.
- [ ] Record any tracer-reported opens that are resolved by the KiCad netlist as tracer limitations, not design failures.

## 2. Backplane Slot Connectivity

Validate `J2` through `J6` as electrically parallel pBITz slots.

- [ ] For every slot connector `J2`, `J3`, `J4`, `J5`, and `J6`, confirm pins A1-A49 and B1-B49 match the pinout in `ARCHITECTURE.md`.
- [ ] Pick one connector as the reference slot, preferably `J2`.
- [ ] Confirm each address net is commoned across all five slots: `A0` through `A23`.
- [ ] Confirm each data net is commoned across all five slots: `D0` through `D15`.
- [ ] Confirm each control net is commoned across all five slots: `~{RESET}` and `CTRL_1` through `CTRL_19`.
- [ ] Confirm each chip-select net is commoned across all five slots: `CS0`, `CS1`, `CS2`, `CS3`.
- [ ] Confirm each slot clock net is commoned across all five slots: `CLK0`, `CLK1`, `CLK2`, `CLK3`.
- [ ] Confirm each SPI/service net is commoned across all five slots: `MOSI`, `MISO`, `SLK_CLK`, `SPI_CS0`, `SPI_CS1`, `SPI_CD`, `~{SPI_INT}`.
- [ ] Confirm the power-control nets are commoned across all five slots: `~{SHUTDOWN_RQ}` and `~{PWR_OFF}`.
- [ ] Confirm every slot has the same `+5V`, `+3V3`, and `GND` pin distribution.

Pass criteria: every shared bus net appears on all expected slot pins, and no
slot has a swapped, missing, or extra connection relative to the schematic
pinout.

## 3. Bus Isolation

Validate that the backplane behaves as a shared bus without unintended shorts
between unrelated nets.

- [ ] Confirm no address net is shorted to another address net.
- [ ] Confirm no data net is shorted to another data net.
- [ ] Confirm no control net is shorted to another control net.
- [ ] Confirm no chip-select net is shorted to another chip-select net.
- [ ] Confirm no SPI/service net is shorted to another SPI/service net.
- [ ] Confirm no address, data, control, chip-select, clock, or SPI/service net is shorted to `+5V`, `+3V3`, `+5V_AON`, or `GND`, except through intentional pull-ups or component paths.
- [ ] Confirm `+5V`, `+3V3`, and `+5V_AON` are not shorted to each other.
- [ ] Confirm `+5V`, `+3V3`, and `+5V_AON` are not shorted to `GND`.

Pass criteria: unrelated nets are isolated. Nets with resistor-network pull-ups
may show resistance to `+5V`; they must not read as direct shorts.

## 4. Slot Power Rail Distribution

Validate rail presence and distribution, not current capacity.

- [ ] Confirm ATX `J1` pins 4, 6, 21, 22, and 23 connect to schematic net `+5V`.
- [ ] Confirm ATX `J1` pins 1, 2, 12, and 13 connect to schematic net `+3V3`.
- [ ] Confirm ATX `J1` pin 9 connects to schematic net `+5V_AON`.
- [ ] Confirm all ATX ground pins connect to schematic net `GND`.
- [ ] Confirm every slot has `+5V` on A1, A2, B1, and B2.
- [ ] Confirm every slot has `+3V3` on A9, A10, B9, and B10.
- [ ] Confirm every slot has `GND` on A4, A31, A35, A39, A43, B4, B31, B35, B39, B43, and B47.
- [ ] Confirm `J7.1` is `+5V`.
- [ ] Confirm `J7.2` is `+3V3`.
- [ ] Confirm J7 ground pins 6, 7, 10, 11, 14, 15, 16, 18, 19, and 20 connect to `GND`.

Pass criteria: rail and ground distribution matches the schematic netlist.

## 5. Pull-Up Network Function

Validate that the resistor networks implement the D/A/C pull-up architecture:
all Data, Address, and non-SPI/non-clock bus Control/select lines are pulled up
to `+5V`; SPI/service and slot clock nets are not.

- [ ] Confirm `RN1.20` is `+5V`.
- [ ] Confirm `RN1` covers `CART`, `~{RESET}`, `CTRL_1` through `CTRL_8`, `CTRL_10` through `CTRL_17`, and `PROG`.
- [ ] Confirm `RN2.20` is `+5V`.
- [ ] Confirm `RN2` covers `A4` through `A11` and `A15` through `A23`.
- [ ] Confirm `RN2.10` and `RN2.11` are intentionally unconnected.
- [ ] Confirm `RN3.16` is `+5V`.
- [ ] Confirm `RN3` covers `A0` through `A3`, `A12` through `A14`, `D4` through `D7`, and `D12` through `D15`.
- [ ] Confirm `RN4.16` is `+5V`.
- [ ] Confirm `RN4` covers `CTRL_9`, `CTRL_18`, `CTRL_19`, `CS0` through `CS3`, `D0` through `D3`, and `D8` through `D11`.
- [ ] Confirm all address nets `A0` through `A23` are pulled up through `RN1`-`RN4`.
- [ ] Confirm all data nets `D0` through `D15` are pulled up through `RN1`-`RN4`.
- [ ] Confirm bus control/select nets `~{RESET}`, `CTRL_1` through `CTRL_19`, `CS0` through `CS3`, `CART`, and `PROG` are pulled up through `RN1`-`RN4`.
- [ ] Confirm slot clock nets `CLK0` through `CLK3` are not tied into `RN1`-`RN4`.
- [ ] Confirm SPI/service nets `MOSI`, `MISO`, `SLK_CLK`, `SPI_CS0`, `SPI_CS1`, `SPI_CD`, and `~{SPI_INT}` are not tied into `RN1`-`RN4`.

Pass criteria: every D/A/C bus net has a resistor path to `+5V`, and no
SPI/service or slot clock net is pulled up through these networks.

## 6. Service Header J7

Validate J7 as a direct breakout of power, ground, and shared SPI/service nets.

- [ ] Confirm `J7.1` is `+5V`.
- [ ] Confirm `J7.2` is `+3V3`.
- [ ] Confirm `J7.3` is `/Backplane/MOSI`.
- [ ] Confirm `J7.4` is `/Backplane/SPI_CS0`.
- [ ] Confirm `J7.5` is `/Backplane/MISO`.
- [ ] Confirm `J7.8` is `/Backplane/SPI_CS1`.
- [ ] Confirm `J7.9` is `/Backplane/SLK_CLK`.
- [ ] Confirm `J7.13` is `/Backplane/~{SPI_INT}`.
- [ ] Confirm `J7.17` is `/Backplane/SPI_CD`.
- [ ] Confirm `J7.12` is intentionally unconnected.
- [ ] Confirm all J7 ground pins match the schematic netlist.
- [ ] Confirm each J7 SPI/service signal is commoned to the matching pins on `J2` through `J6`.

Pass criteria: J7 is a faithful service breakout and does not introduce any
slot-only or header-only variant of the SPI/service nets.

## 7. Power-Control Signal Paths

Validate electrical connectivity of the always-on power-control island without
validating ATtiny firmware behavior.

- [ ] Confirm `+5V_AON` powers `U1.8`.
- [ ] Confirm `U1.4` connects to `GND`.
- [ ] Confirm `J1.8` ATX `PWR_OK` connects to `U1.6/PB1`.
- [ ] Confirm `U1.5/PB0` connects to `Q1.1` gate.
- [ ] Confirm `Q1.2` source connects to `GND`.
- [ ] Confirm `Q1.3` drain connects to `J1.16` ATX `PS_ON#`.
- [ ] Confirm `R6` pulls the Q1 gate net to `GND`.
- [ ] Confirm `SW1` and `R1` form the schematic-defined `PWR_SW` input path to `U1.7/PB2`.
- [ ] Confirm `R5` pulls the ATtiny reset net to `+5V_AON`.
- [ ] Confirm `R7` pulls `/Backplane/~{SHUTDOWN_RQ}` to `+5V_AON`.
- [ ] Confirm `R8` pulls `/Backplane/~{PWR_OFF}` to `+5V_AON`.
- [ ] Confirm `/Backplane/~{SHUTDOWN_RQ}` appears on every slot A3 and at `U1.2/PB3`.
- [ ] Confirm `/Backplane/~{PWR_OFF}` appears on every slot B3 and at `U1.3/PB4`.

Pass criteria: the ATtiny can electrically observe `PWR_OK`, observe the power
button path, drive the MOSFET gate net, and connect to the two backplane
power-control nets. Firmware behavior is not evaluated here.

## 8. Intentional Opens And No-Connects

Validate that unconnected pins are intentional and limited to the expected list.

- [ ] Confirm ATX `J1.10` and `J1.11` `+12V` are unconnected.
- [ ] Confirm ATX `J1.14` `-12V` is unconnected.
- [ ] Confirm ATX `J1.20` `NC` is unconnected.
- [ ] Confirm `J7.12` is unconnected.
- [ ] Confirm `RN2.10` and `RN2.11` are unconnected.
- [ ] Confirm no additional connector pins or resistor-network pins are unconnected in the KiCad schematic netlist.

Pass criteria: all opens match the schematic netlist and no unexpected open
exists on a functional bus, rail, ground, service, or power-control signal.

## 9. Gotcha Review

Review the design intent at the system level after the detailed connectivity
checks pass.

- [ ] Confirm the board has exactly one active logic island: the always-on ATtiny power-control circuit.
- [ ] Confirm the main pBITz bus is passive and shared across `J2` through `J6`.
- [ ] Confirm the design does not depend on any active local address decode, buffering, or slot-select logic on the backplane.
- [ ] Confirm every net required for a card to see the bus is present on every slot: power, ground, address, data, control, chip select, clock, SPI/service, and power-control nets.
- [ ] Confirm all D/A/C bus lines are pulled up and that pull-ups are not accidentally applied to SPI/service or slot clock nets.
- [ ] Confirm the always-on power-control path can electrically connect ATX `PWR_OK`, `PS_ON#`, power button input, `~{SHUTDOWN_RQ}`, and `~{PWR_OFF}` to the ATtiny pins.
- [ ] Confirm all known unconnected pins are intentional and documented.
- [ ] Confirm any tracer limitations are resolved against the schematic netlist before accepting the result.

Pass criteria: no unresolved design-file issue remains that would obviously
prevent the backplane from distributing rails, ground, slot bus signals,
service signals, or power-control signals as intended.

## 10. Final Acceptance

- [ ] Schematic hierarchy matches the intended active design.
- [ ] KiCad schematic netlist agrees with the architecture document.
- [ ] `kicad_nettrace.py` reports no output-driver conflicts.
- [ ] Slot-to-slot continuity passes for all shared bus nets.
- [ ] Isolation checks pass for unrelated nets and rails.
- [ ] J7 maps exactly to the documented service header pinout.
- [ ] Pull-up networks cover exactly the documented nets.
- [ ] Power-control connectivity passes without requiring firmware validation.
- [ ] Intentional opens are limited to the documented list.
- [ ] Gotcha review finds no unresolved obvious functional risk.

Functional validation passes when every applicable item above is checked and
all deviations are either corrected in the design or explicitly recorded as
accepted design changes.

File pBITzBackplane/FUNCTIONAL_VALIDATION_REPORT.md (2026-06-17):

# pBITzBackplane Functional Validation Report

Date: 2026-06-17

Result: PASS for the workspace-only functional validation scope.

This report validates the `pBITzBackplane` design files for reasonable
assurance that the board should power on and behave as the intended passive
shared bus backplane with an always-on ATtiny power-control island. The goal is
to catch obvious schematic/netlist/PCB gotchas, not to certify the design or
prove hardware behavior on a fabricated board.

## Scope

In scope:

- Active schematic hierarchy.
- KiCad schematic netlist connectivity.
- `kicad_nettrace.py` secondary connectivity cross-check.
- Selected PCB pad-net agreement for functional connectors and control parts.
- Slot-to-slot bus consistency.
- Rail and ground distribution in the design files.
- Pull-up network coverage.
- J7 service-header mapping.
- ATtiny power-control connectivity.
- Intentional opens/no-connects.

Out of scope:

- Physical-board continuity checks.
- Powered rail measurements.
- Bench bring-up.
- Mechanical validation.
- DRC/ERC closure.
- Power-budget/current-capacity validation.
- Firmware/software behavior.

## Artifacts Used

| Artifact | Purpose |
| --- | --- |
| `pBITzBackplane.kicad_sch` | Root schematic and active hierarchy. |
| `Power.kicad_sch` | ATX and always-on power-control circuitry. |
| `Backplane.kicad_sch` | Slot connectors, service header, pull-ups, and rail decoupling. |
| `pBITzBackplane.kicad_pcb` | PCB pad-net cross-check for functional nets. |
| `Code/tools/kicad_nettrace.py` | Secondary hierarchy/connectivity check. |
| `/tmp/pbitzbackplane-kicad.net` | KiCad schematic netlist exported for validation. |
| `ARCHITECTURE.md` | Design intent reference. |
| `FUNCTIONAL_VALIDATION_CHECKLIST.md` | Validation checklist. |

Authority rule: the schematic and KiCad schematic netlist are authoritative.
`kicad_nettrace.py` is used only as a secondary check.

## Commands Run

```sh
HOME=/tmp XDG_CONFIG_HOME=/tmp XDG_DATA_HOME=/tmp kicad-cli sch export netlist -o /tmp/pbitzbackplane-kicad.net pBITzBackplane/pBITzBackplane.kicad_sch
python3 Code/tools/kicad_nettrace.py /home/kitamura/Documents/pBITzPlatform/pBITzBackplane/pBITzBackplane.kicad_sch
python3 Code/tools/kicad_nettrace.py /home/kitamura/Documents/pBITzPlatform/pBITzBackplane/pBITzBackplane.kicad_sch --check
```

Additional temporary Python checks parsed the KiCad schematic netlist and PCB
file to verify the functional pin/net expectations in the checklist.

## Summary Results

| Area | Result | Evidence |
| --- | --- | --- |
| Active hierarchy | PASS | Exported netlist contains only `/`, `/Power/`, and `/Backplane/`. |
| Nettrace coverage | PASS | Root 2/2, Power 75/79, Backplane 613/616 pin hits. |
| Nettrace conflicts | PASS | No driver-driver conflicts reported. |
| Schematic-netlist functional checks | PASS | 712 checks passed, 0 failed. |
| Selected PCB pad-net checks | PASS | 546 checks passed, 0 failed. |
| D/A/C pull-up rule | PASS | 66 expected D/A/C pull-up nets found, none missing; no SPI/service or slot clock nets pulled up through `RN1`-`RN4`. |
| Intentional opens | PASS | Only expected connector/resistor-network opens were found. |
| Hardware/powered checks | OUT OF SCOPE | Requires physical board or powered bench setup. |

## Checklist Results

| Checklist section | Result | Notes |
| --- | --- | --- |
| 1. Source And Artifact Setup | PASS | KiCad netlist export succeeded; active hierarchy matched expected sheets; nettrace found no output-driver conflicts. |
| 2. Backplane Slot Connectivity | PASS | `J2` through `J6` all match the expected 98-pin pBITz slot map. Address, data, control, chip-select, clock, service, rail, ground, and power-control nets are commoned as intended. |
| 3. Bus Isolation | PASS | The schematic netlist shows unrelated bus, service, control, rail, and ground nets remain separate, except for intentional component paths such as resistor-network pull-ups. |
| 4. Slot Power Rail Distribution | PASS | ATX `+5V`, `+3V3`, `+5V_AON`, and `GND` map to the expected slot, J7, and control-circuit pins in the design files. |
| 5. Pull-Up Network Function | PASS | `RN1`, `RN2`, `RN3`, and `RN4` implement the D/A/C pull-up rule: all address, data, and non-SPI/non-clock bus control/select nets are pulled up to `+5V`; SPI/service and slot clock nets are not pulled up through the resistor networks. |
| 6. Service Header J7 | PASS | J7 maps to `+5V`, `+3V3`, `GND`, and the shared SPI/service nets exactly as documented; `J7.12` is intentionally unconnected. |
| 7. Power-Control Signal Paths | PASS | `U1`, `Q1`, `J1`, `SW1`, `R1`, `R5`, `R6`, `R7`, and `R8` connect to the intended power-control nets. Firmware behavior is not evaluated. |
| 8. Intentional Opens And No-Connects | PASS | Expected opens only: ATX `+12V`, `-12V`, `NC`; `J7.12`; `RN2.10`; `RN2.11`. |
| 9. Gotcha Review | PASS | No unresolved design-file issue was found that obviously prevents rail distribution, shared bus distribution, service-header breakout, pull-up behavior, or power-control connectivity. |
| 10. Final Acceptance | PASS | All workspace-only validation items pass. |

## Expected Opens

The KiCad schematic netlist contains these expected connector/resistor-network
opens:

| Ref.pin | Net |
| --- | --- |
| `J1.10` | `unconnected-(J1-+12V-Pad10)` |
| `J1.11` | `unconnected-(J1-+12V-Pad10)` |
| `J1.14` | `unconnected-(J1--12V-Pad14)` |
| `J1.20` | `unconnected-(J1-NC-Pad20)` |
| `J7.12` | `unconnected-(J7-Pin_12-Pad12)` |
| `RN2.10` | `unconnected-(RN2-Pad10)` |
| `RN2.11` | `unconnected-(RN2-Pad11)` |

No pBITz slot connector pins were unconnected.

## Nettrace Notes

`kicad_nettrace.py --check` reported isolated pins on several nets that the
KiCad schematic netlist resolves correctly, including global power/common pins
such as `J7.1`, `J7.2`, resistor-network common pins, and `+5V_AON` pull-up
nodes. These are treated as tracer limitations because the schematic netlist is
the authority and the PCB pad-net cross-check agrees with it.

The useful nettrace result is that it found no output-driver conflicts.

## Functional Assessment

Within the workspace-only scope, the design files provide reasonable assurance
that:

- The ATX connector distributes the intended `+5V`, `+3V3`, `+5V_AON`, and
  `GND` nets.
- Every pBITz slot sees the same address, data, control, chip-select, clock,
  SPI/service, power-control, rail, and ground nets.
- J7 is a direct breakout of the intended service SPI nets plus rails and
  ground.
- The resistor networks pull up the intended bus/control nets and do not
  accidentally pull up the SPI/service or slot clock nets.
- The ATtiny power-control island is electrically connected to `PWR_OK`,
  `PS_ON#`, the power button path, `~{SHUTDOWN_RQ}`, and `~{PWR_OFF}`.
- The only connector/resistor-network opens are expected and documented.

The D/A/C pull-up validation found all 66 expected resistor-network pull-up
nets: `A0`-`A23`, `D0`-`D15`, `~{RESET}`, `CTRL_1`-`CTRL_19`, `CS0`-`CS3`,
`CART`, and `PROG`. No SPI/service nets or slot clock nets were found on the
bus pull-up networks.

No obvious design-file gotcha was found that would prevent the board from
powering on or acting as the intended passive backplane, assuming the out-of-
scope DRC/ERC, power budget, manufacturing, and physical bring-up assumptions
remain valid.

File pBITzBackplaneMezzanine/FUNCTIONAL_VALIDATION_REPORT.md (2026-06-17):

# pBITzBackplaneMezzanine Functional Validation Report

Date: 2026-06-17

Result: PASS for the workspace-only functional validation scope, with one
nonblocking advisory.

The current design files provide reasonable assurance, within the stated
workspace-only scope, that the mezzanine should receive power and support the
intended SPI-attached USB and SD-card functions. The stacked USB-A connector
polarity was explicitly checked against the connector pin functions and passes
in the current schematic and PCB.

## Scope

In scope:

- Active schematic hierarchy.
- KiCad schematic netlist connectivity.
- `kicad_nettrace.py` secondary connectivity cross-check.
- Selected PCB pad-net agreement for functional connectors and active parts.
- J5 mezzanine connector mapping.
- Rail and ground distribution in the design files.
- SPI fanout and status signal routing.
- USB host-controller/hub connectivity.
- SD-card SPI-mode connectivity.
- Intentional opens/no-connects.

Out of scope:

- Physical-board continuity checks.
- Powered rail measurements.
- Bench bring-up.
- Mechanical validation.
- DRC/ERC closure.
- Power-budget/current-capacity validation.
- Firmware/software behavior.

Authority rule: the schematic and KiCad schematic netlist are authoritative.
`kicad_nettrace.py` is used only as a secondary check.

## Artifacts Used

| Artifact | Purpose |
| --- | --- |
| `pBITzBackplaneMezzanine.kicad_sch` | Root schematic and active hierarchy. |
| `USBPorts.kicad_sch` | USB host controller, hub, USB connectors, fuses, crystals, support parts. |
| `MezzanineConnector.kicad_sch` | J5 mezzanine connector and mounting-hole pads. |
| `SD_Card.kicad_sch` | SD-card socket and SD signal buffering. |
| `pBITzBackplaneMezzanine.kicad_pcb` | PCB pad-net cross-check for functional nets. |
| `Code/tools/kicad_nettrace.py` | Secondary hierarchy/connectivity check. |
| `/tmp/pbitzbackplane-mezzanine-kicad.net` | KiCad schematic netlist exported for validation. |
| `00-Datasheets/Peripheral/max3421e.pdf` | Local reference for MAX3421E pin behavior. |
| `00-Datasheets/Peripheral/fe1.1s应用电路.pdf` | Local FE1.1 reference circuit used for D+/D- convention. |
| `ARCHITECTURE.md` | Design intent reference. |
| `FUNCTIONAL_VALIDATION_CHECKLIST.md` | Validation checklist. |

## Commands Run

```sh
HOME=/tmp XDG_CONFIG_HOME=/tmp XDG_DATA_HOME=/tmp kicad-cli sch export netlist -o /tmp/pbitzbackplane-mezzanine-kicad.net pBITzBackplaneMezzanine/pBITzBackplaneMezzanine.kicad_sch
python3 Code/tools/kicad_nettrace.py pBITzBackplaneMezzanine/pBITzBackplaneMezzanine.kicad_sch
python3 Code/tools/kicad_nettrace.py pBITzBackplaneMezzanine/pBITzBackplaneMezzanine.kicad_sch --check
```

Additional temporary Python checks parsed the KiCad schematic netlist and PCB
file to verify the functional pin/net expectations in the checklist.

During this pass, `Code/tools/kicad_nettrace.py` was patched so `_resolve()`
checks a relative path as supplied before joining it to the root schematic
directory. This fixes the tool when called as:

```sh
python3 Code/tools/kicad_nettrace.py pBITzBackplaneMezzanine/pBITzBackplaneMezzanine.kicad_sch
```

## Summary Results

| Area | Result | Evidence |
| --- | --- | --- |
| Active hierarchy | PASS | Exported netlist contains only `/`, `/USBPorts/`, `/SD_Card/`, and `/MezzanineConnector/`. |
| Nettrace coverage | PASS | Root 0/0, USBPorts 136/173, MezzanineConnector 27/28, SD_Card 31/37 pin hits. |
| Nettrace conflicts | PASS | No driver-driver conflicts reported. |
| Schematic/PCB functional checks | PASS | 494 checks run: 494 passed, 0 failed. |
| J5 interface | PASS | J5 maps to `+5V`, `+3V3`, SPI, interrupt, SD-present, and ground as documented. |
| Rails and ground | PASS | `+5V`, `+3V3`, `+3V3_INTERNAL`, and `GND` are distributed to expected pins. |
| SPI fanout | PASS | MOSI, clock, CS0, CS1, MISO, USB interrupt, and SD-present paths match the architecture. |
| USB upstream path | PASS | MAX3421E D+/D- connect through 33 ohm resistors to FE1.1 upstream DPU/DMU. |
| USB downstream J1 polarity | PASS | FE1.1 `DM1/DM2` nets land on USB-A `D-` pins, and `DP1/DP2` nets land on USB-A `D+` pins. |
| SD-card interface | PASS | SPI-mode SD socket wiring and card-detect path match the architecture. |
| Intentional opens | PASS with advisory | Expected no-connects are documented; review `U2.22/VBCOMP` before fabrication. |
| Hardware/powered checks | OUT OF SCOPE | Requires physical board or powered bench setup. |

## Key Gotcha Check

### 1. USB-A D+/D- Polarity Passes On J1

The FE1.1 hub nets use the conventional names `DMx` for D- and `DPx` for D+.
The local FE1.1 reference circuit follows that convention. In the current
mezzanine design, both stacked USB-A ports on `J1` match that convention:

| Port | Connector pin | Connector function | Current net | Expected net |
| --- | ---: | --- | --- | --- |
| 1 | `J1.2` | `D1-` | `/USBPorts/DM1` | `/USBPorts/DM1` |
| 1 | `J1.3` | `D1+` | `/USBPorts/DP1` | `/USBPorts/DP1` |
| 2 | `J1.11` | `D2-` | `/USBPorts/DM2` | `/USBPorts/DM2` |
| 2 | `J1.12` | `D2+` | `/USBPorts/DP2` | `/USBPorts/DP2` |

The PCB has the same assignments as the schematic.

## Advisory Finding

### 2. Review MAX3421E `VBCOMP` No-Connect

`U2.22/VBCOMP` is intentionally marked no-connect in the schematic netlist. The
local MAX3421E datasheet describes `VBCOMP` as the VBUS comparator input and
recommends bypassing it to ground with a 1.0 uF ceramic capacitor. If this
design never uses the MAX3421E VBUS comparator, the no-connect may be an
intentional simplification; however, it should be reviewed before fabrication.

This was not counted as a blocking validation failure because the workspace
design files mark it as intentional and the main MAX3421E USB data path does
not depend on it in the schematic connectivity.

## Checklist Results

| Checklist section | Result | Notes |
| --- | --- | --- |
| 1. Source And Artifact Setup | PASS | KiCad netlist export succeeded; active hierarchy matched expected sheets; nettrace found no driver-driver conflicts. |
| 2. Mezzanine Connector J5 | PASS | J5 pinout matches `ARCHITECTURE.md`. |
| 3. Rail And Ground Distribution | PASS | Rails and grounds route to expected functional pins in schematic and PCB. |
| 4. SPI Signal Routing | PASS | USB and SD chip-selects, MOSI, clock, MISO, interrupt, and SD-present paths are correct. |
| 5. USB Host Controller And Hub | PASS | MAX3421E-to-FE1.1 upstream path and FE1.1 support pins match the intended simplified hub design. |
| 6. USB Downstream Connectors | PASS | J1 stacked USB-A D+/D- polarity passes on ports 1 and 2. J2/J3 auxiliary headers match the documented board nets. |
| 7. SD-Card Interface | PASS | SD socket is wired for SPI mode with card detect and expected no-connects. |
| 8. Level-Shifter Unused Gates | PASS | Unused 4050 inputs are tied to `GND`; paired outputs are no-connected. |
| 9. Intentional Opens And No-Connects | PASS with advisory | Expected no-connects only; `VBCOMP` should be reviewed. |
| 10. PCB Pad-Net Agreement | PASS | Schematic and PCB agree for key functional parts, including the J1 polarity-sensitive USB nets. |
| 11. Gotcha Review | PASS with advisory | No blocking design-file issue remains; review `VBCOMP` no-connect before fabrication. |
| 12. Final Acceptance | PASS with advisory | Current workspace-only validation passes with the `VBCOMP` review note. |
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

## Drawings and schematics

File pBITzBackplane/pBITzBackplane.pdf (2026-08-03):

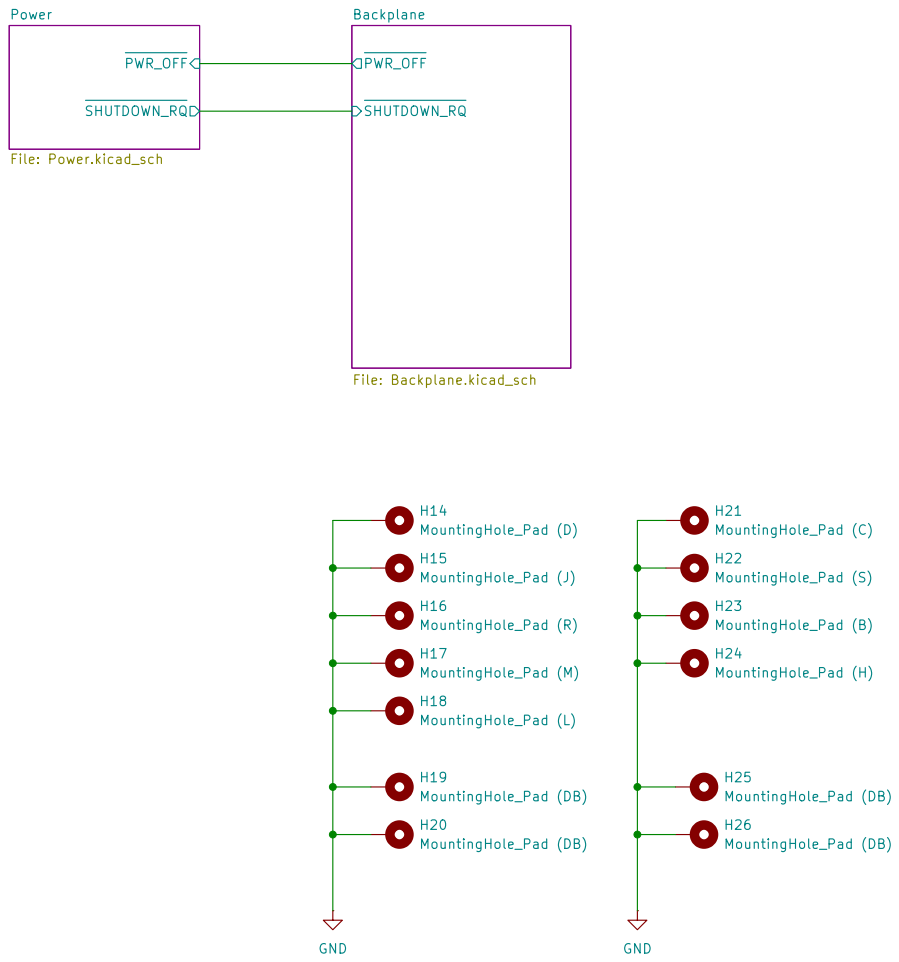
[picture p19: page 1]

Size: D | Rev:
KiCad E.D.A. 10.0.5 | Id: 1/3

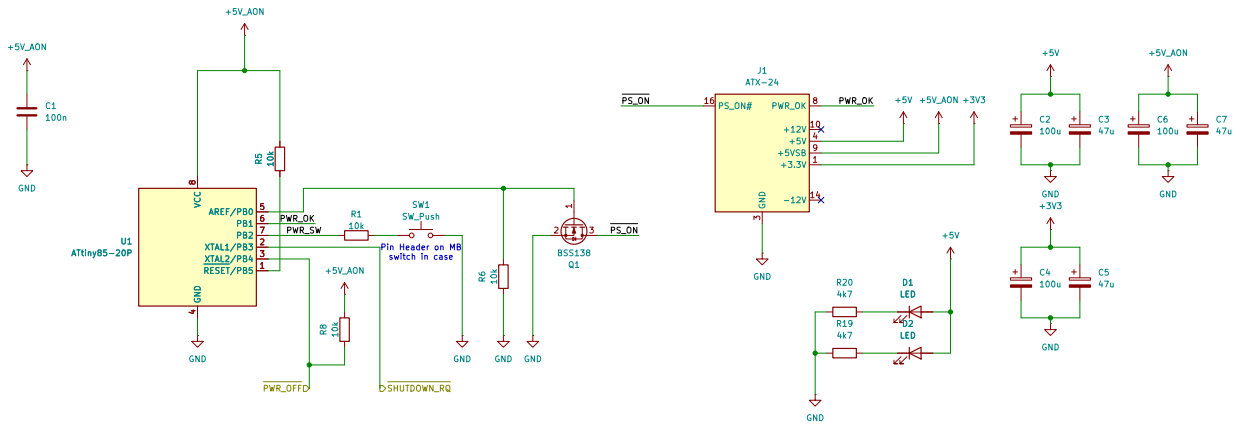
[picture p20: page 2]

Pin Header on MB

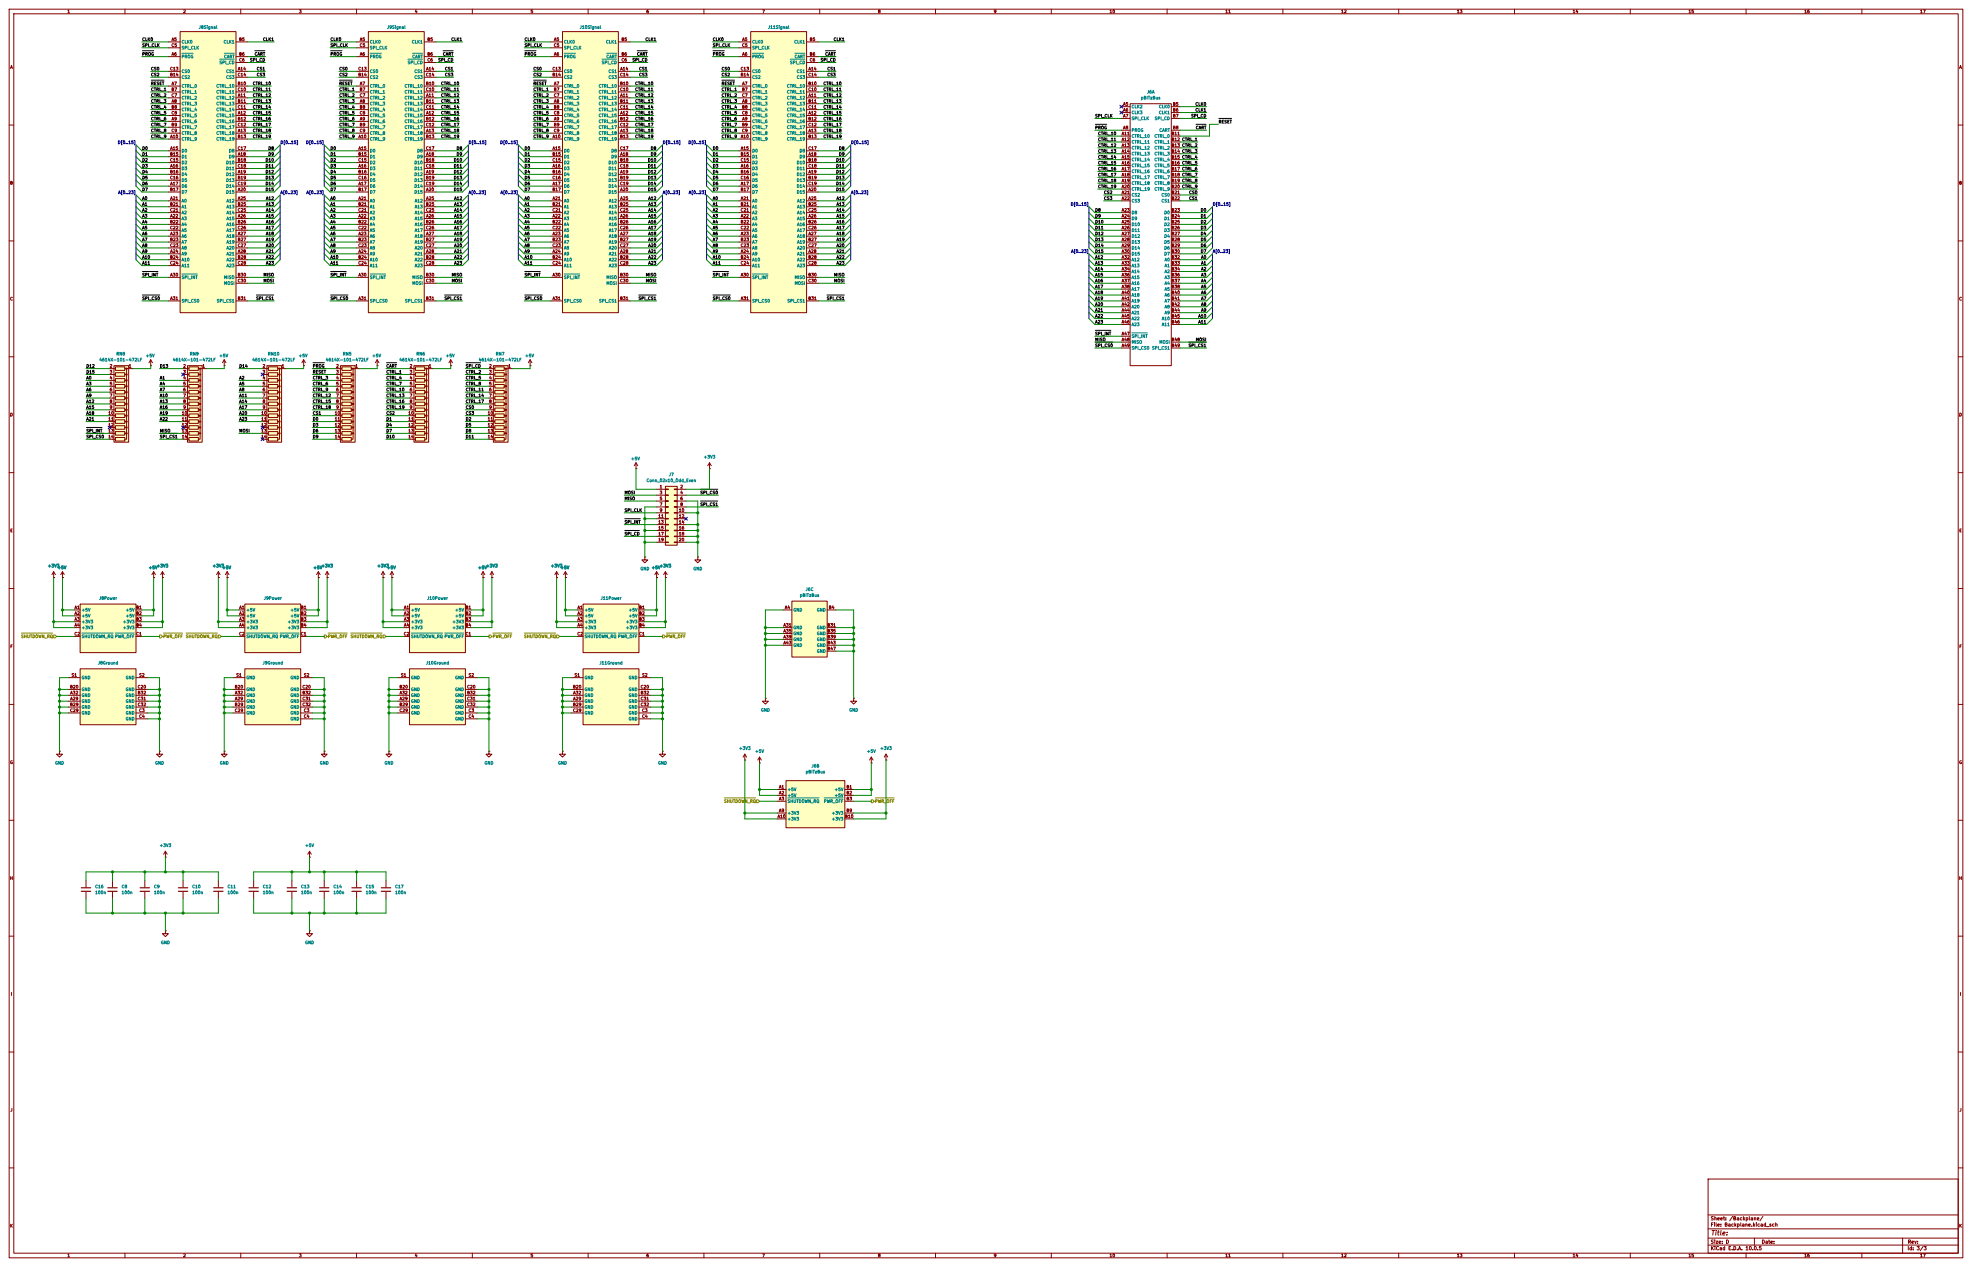
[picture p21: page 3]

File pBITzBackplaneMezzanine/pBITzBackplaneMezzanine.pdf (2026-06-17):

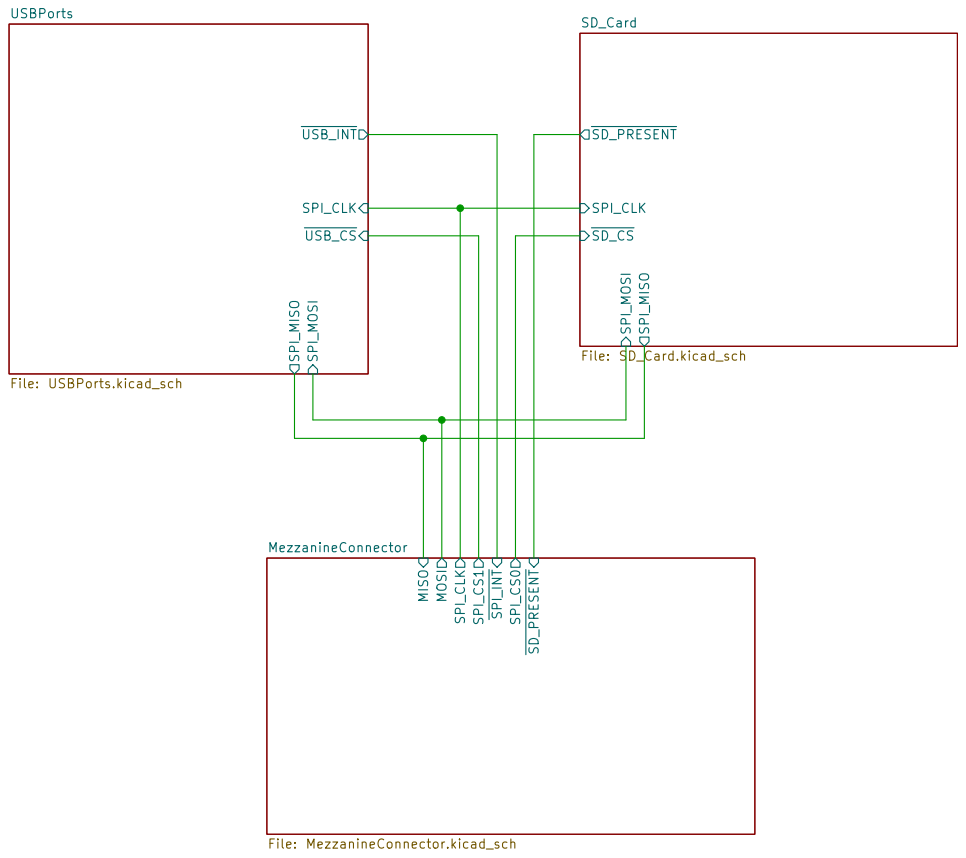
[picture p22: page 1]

Size: D | Rev:
KiCad E.D.A. 10.0.3 | Id: 1/4

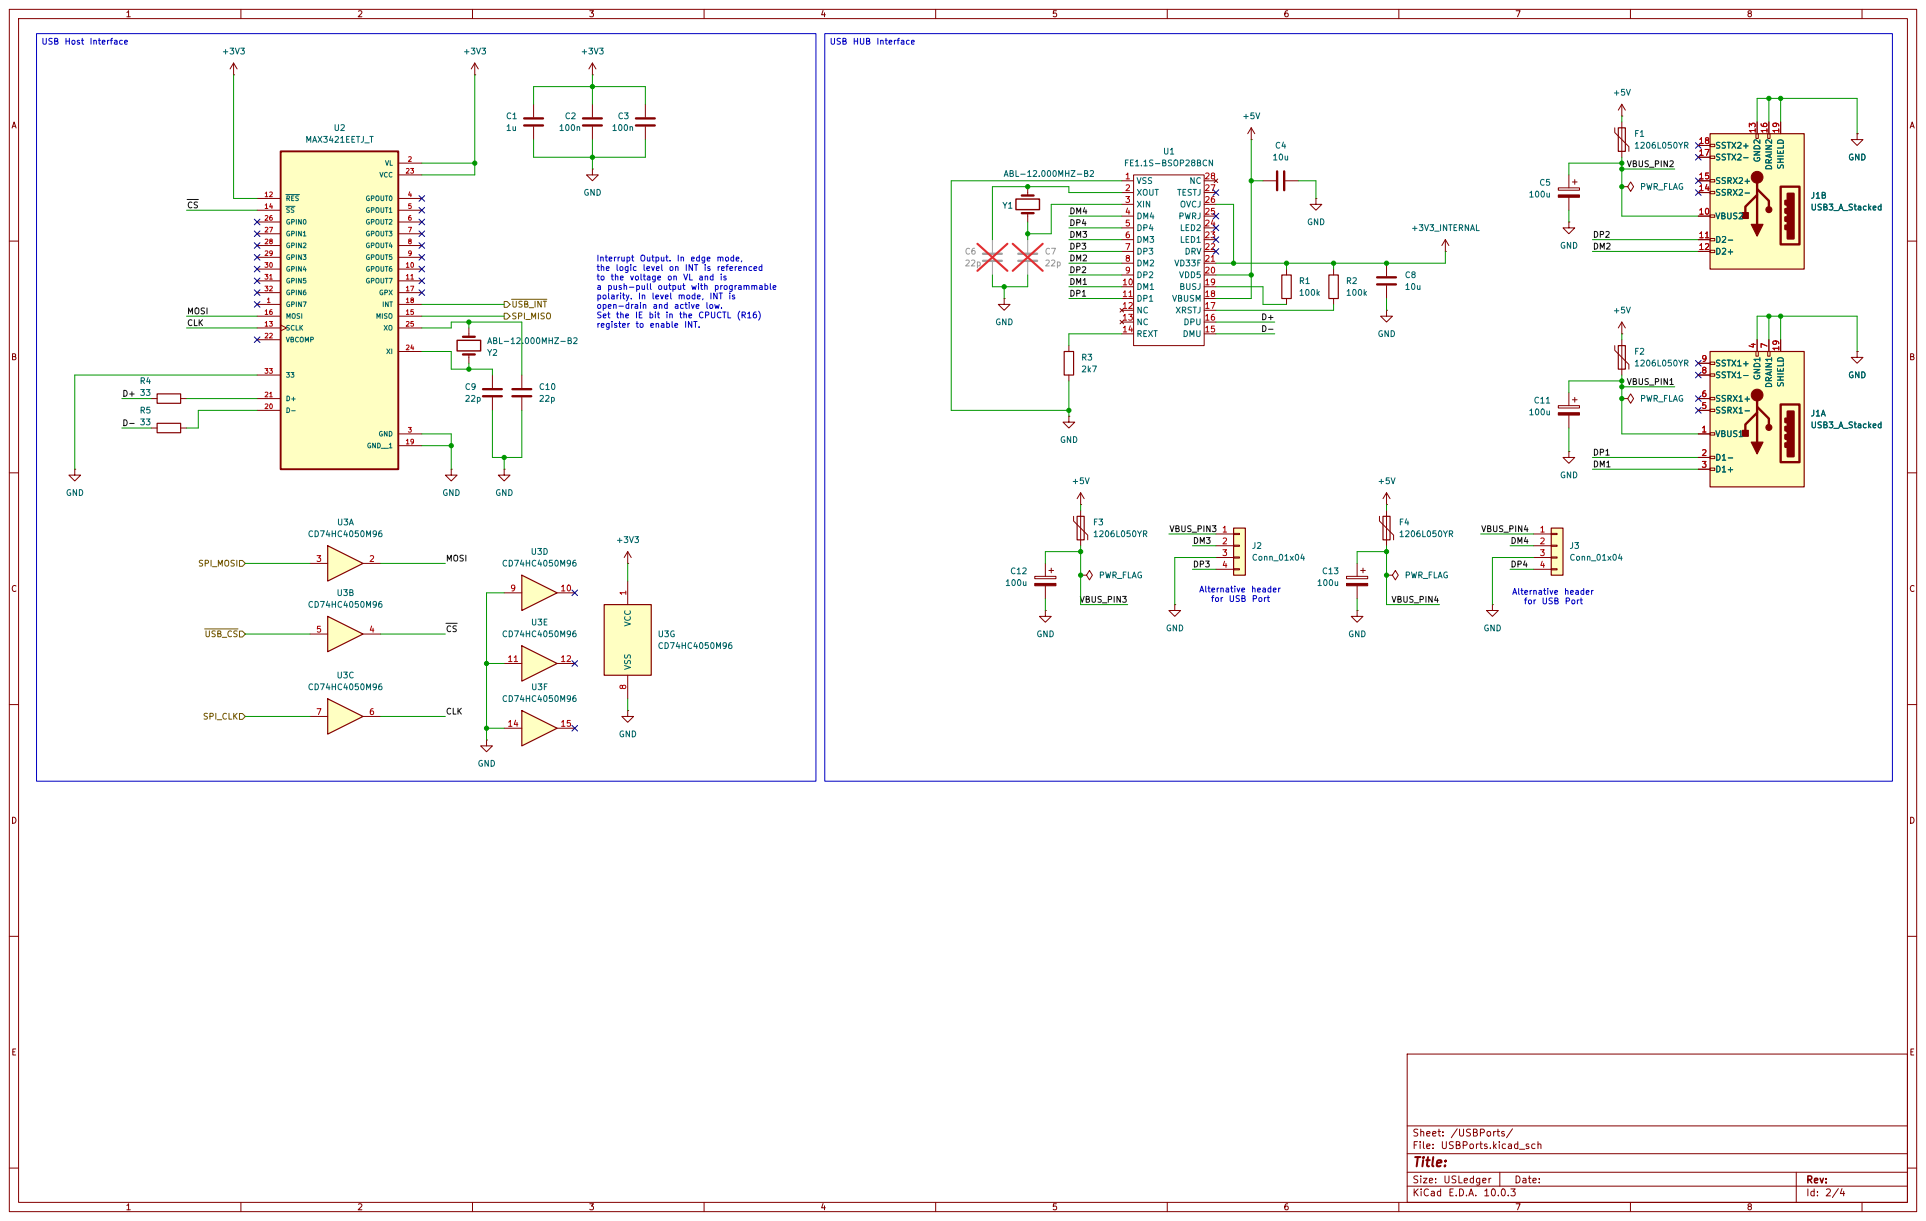
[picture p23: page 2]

Interrupt Output. In edge mode,
the logic level on INT is referenced
to the voltage on VL and is a push-pull output with programmable

polarity. In level mode, INT is open-drain and active low. Set the IE bit in the CPUCTL (R16)

for USB Port Alternative header
for USB Port

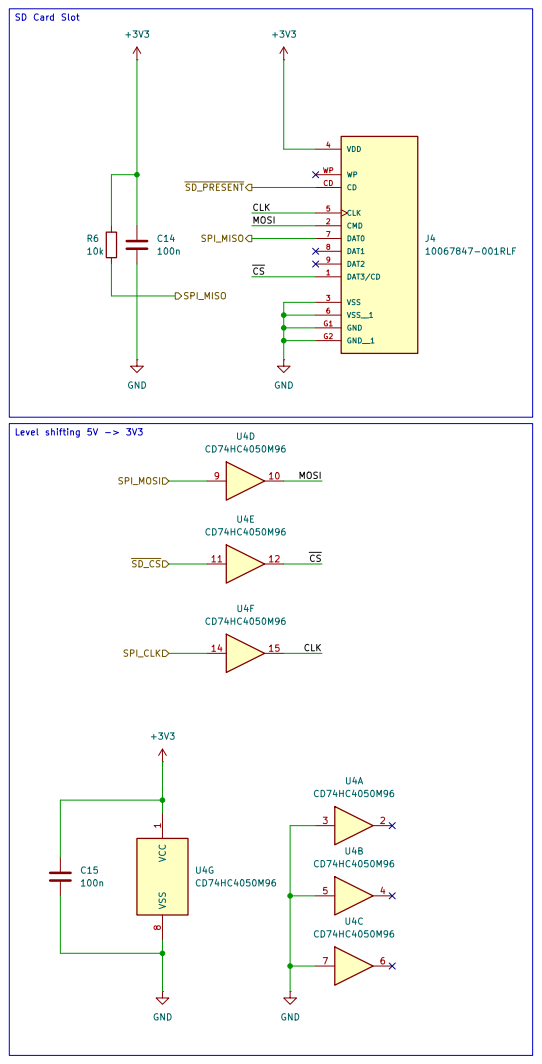
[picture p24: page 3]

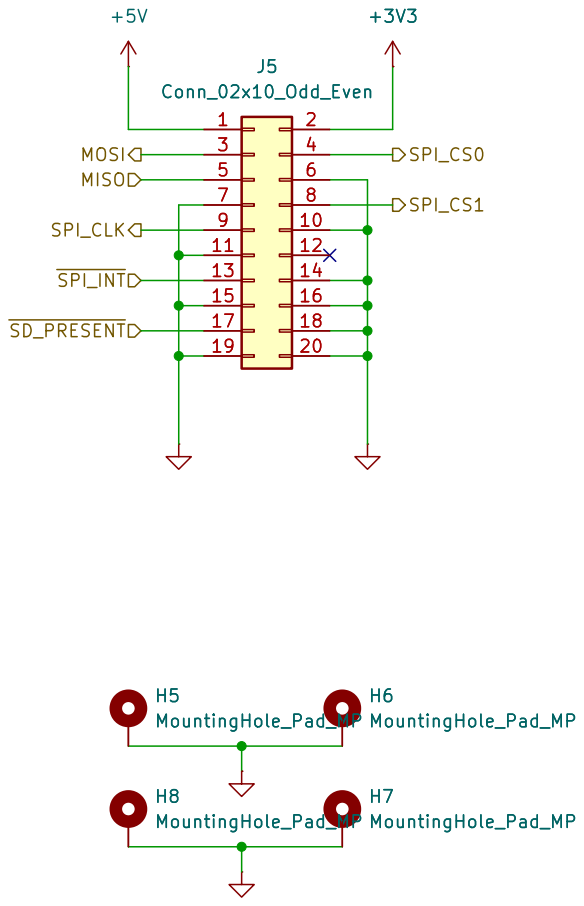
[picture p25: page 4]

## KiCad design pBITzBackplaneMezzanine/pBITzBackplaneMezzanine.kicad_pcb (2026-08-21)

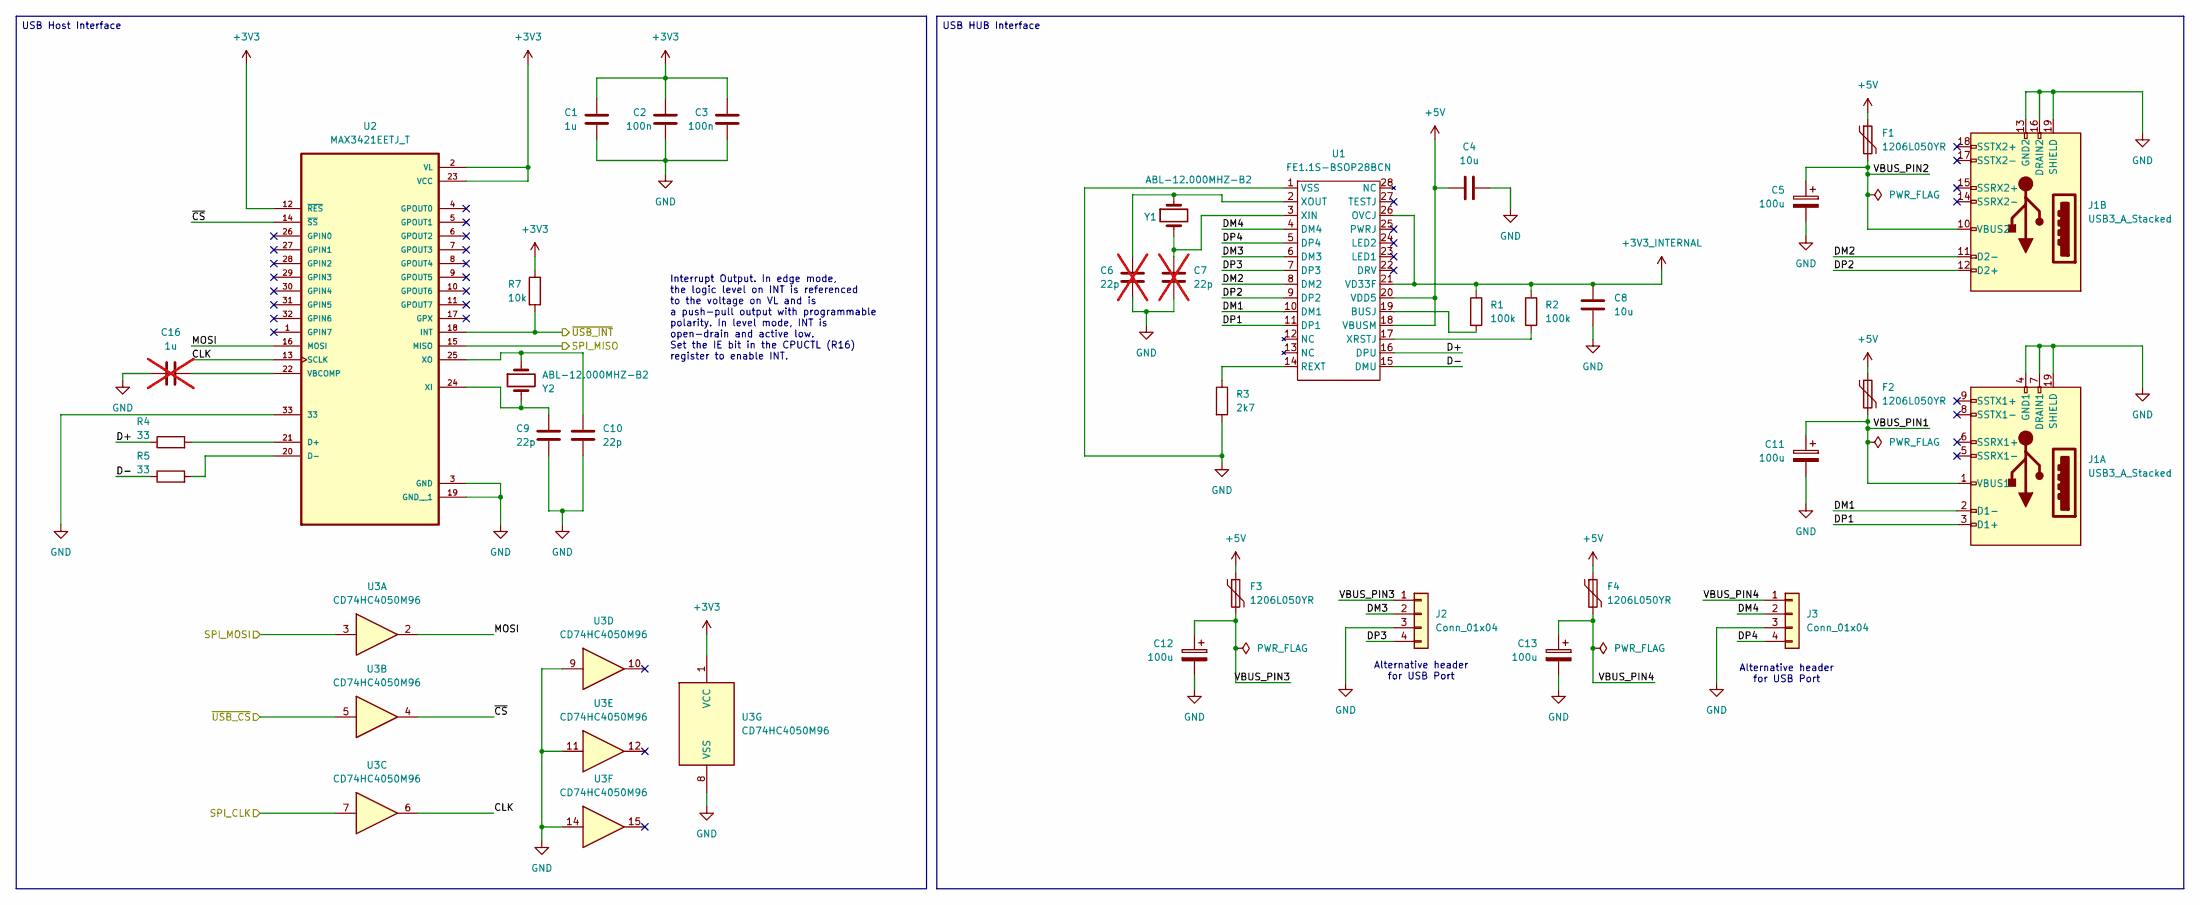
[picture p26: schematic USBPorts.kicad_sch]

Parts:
C1: 1u; C_0603_1608Metric; MANUFACTURER_PART_NUMBER C0603C105K4RACTU
C2, C3: 100n; C_0603_1608Metric; MANUFACTURER_PART_NUMBER C0603C104K5RACTU
C4, C8: 10u; C_0603_1608Metric; MANUFACTURER_PART_NUMBER CL10X106MO8NRNC
C5, C11, C12, C13: 100u; CP_Radial_D5.0mm_P2.50mm; MANUFACTURER_PART_NUMBER ECA-1CHG101I
C6, C7: 22p; C_0603_1608Metric; not fitted
C9, C10: 22p; C_0603_1608Metric; MANUFACTURER_PART_NUMBER KGM15ACG1C220KT
C16: 1u; C_0603_1608Metric; MANUFACTURER_PART_NUMBER CL10X106MO8NRNC; not fitted
F1, F2, F3, F4: 1206L050YR; Fuse_1206_3216Metric; MANUFACTURER_PART_NUMBER 1206L050YR
J1: USB3_A_Stacked; USB3_A_Molex_48406-0001_Horizontal_Stacked; MANUFACTURER_PART_NUMBER 0484060001
J2, J3: Conn_01x04; PinHeader_1x04_P2.54mm_Vertical; MANUFACTURER_PART_NUMBER 732-5301-ND
R1, R2: 100k; R_0603_1608Metric; MANUFACTURER_PART_NUMBER RMCF0603FT100K
R3: 2k7; R_0603_1608Metric; MANUFACTURER_PART_NUMBER RC0603JR-072K7L
R4, R5: 33; R_0603_1608Metric; MANUFACTURER_PART_NUMBER RC0603FR-0733RL
R7: 10k; R_0603_1608Metric; MANUFACTURER_PART_NUMBER RC0603FR-0710KL
U1: FE1.1S-BSOP28BCN; SSOP-28_5.3x10.2mm_P0.65mm; MANUFACTURER_PART_NUMBER FE1.1S-BSOP28BCN
U2: MAX3421EETJ_T; QFN50P500X500X80-33N; MANUFACTURER_PART_NUMBER MAX3421EETJ+T
U3: CD74HC4050M96; SOIC-16_3.9x9.9mm_P1.27mm; MANUFACTURER_PART_NUMBER CD74HC4050M96
Y1, Y2: ABL-12.000MHZ-B2; Crystal_HC49-U_Vertical; MANUFACTURER_PART_NUMBER ABL-12.000MHZ-B2

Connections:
+3V3: C1.2, C2.2, C3.2, R7.1, U2.2 (VL), U2.12 (~RES), U2.23 (VCC), U3.1 (VCC); also elsewhere on the board
+3V3_INTERNAL: C8.1, R1.1, R2.1, U1.21 (VD33F), U1.26 (OVCJ)
+5V: C4.1, F1.1, F2.1, F3.1, F4.1, U1.18 (VBUSM), U1.20 (VDD5); also elsewhere on the board
/MezzanineConnector/MISO: U2.15 (MISO); also elsewhere on the board
/MezzanineConnector/MOSI: U3.3; also elsewhere on the board
/MezzanineConnector/SPI_CLK: U3.7; also elsewhere on the board
/MezzanineConnector/SPI_CS0: U3.5; also elsewhere on the board
/MezzanineConnector/~SPI_INT: R7.2, U2.18 (INT); also elsewhere on the board
/USBPorts/CLK: U2.13 (SCLK), U3.6
/USBPorts/D+: R4.1, U1.16 (DPU)
/USBPorts/D-: R5.1, U1.15 (DMU)
/USBPorts/DM1: J1.2 (D1-), U1.10 (DM1)
/USBPorts/DM2: J1.11 (D2-), U1.8 (DM2)
/USBPorts/DM3: J2.2, U1.6 (DM3)
/USBPorts/DM4: J3.2, U1.4 (DM4)
/USBPorts/DP1: J1.3 (D1+), U1.11 (DP1)
/USBPorts/DP2: J1.12 (D2+), U1.9 (DP2)
/USBPorts/DP3: J2.4, U1.7 (DP3)
/USBPorts/DP4: J3.4, U1.5 (DP4)
/USBPorts/MOSI: U2.16 (MOSI), U3.2
/USBPorts/VBUS_PIN1: C11.1, F2.2, J1.1 (VBUS1)
/USBPorts/VBUS_PIN2: C5.1, F1.2, J1.10 (VBUS2)
/USBPorts/VBUS_PIN3: C12.1, F3.2, J2.1
/USBPorts/VBUS_PIN4: C13.1, F4.2, J3.1
/USBPorts/~CS: U2.14 (~SS), U3.4
GND: C1.1, C2.1, C3.1, C4.2, C5.2, C6.1, C7.1, C8.2, C9.1, C10.1, C11.2, C12.2, C13.2, C16.1, J1.4 (GND1), J1.7 (DRAIN1), J1.13 (GND2), J1.16 (DRAIN2), J1.19 (SHIELD), J2.3, J3.3, R3.2, U1.1 (VSS), U2.3 (GND), U2.19 (GND__1), U2.33, U3.8 (VSS), U3.9, U3.11, U3.14; also elsewhere on the board
unnamed: R1.2, U1.19 (BUSJ)
unnamed: R3.1, U1.14 (REXT)
unnamed: C7.2, U1.3 (XIN), Y1.2
unnamed: C6.2, U1.2 (XOUT), Y1.1
unnamed: R2.2, U1.17 (XRSTJ)
unnamed: R4.2, U2.21 (D+)
unnamed: R5.2, U2.20 (D-)
unnamed: C16.2, U2.22 (VBCOMP)
unnamed: C9.2, U2.24 (XI), Y2.2
unnamed: C10.2, U2.25 (XO), Y2.1

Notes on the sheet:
Interrupt Output. In edge mode, the logic level on INT is referenced to the voltage on VL and is a push-pull output with programmable polarity. In level mode, INT is open-drain and active low. Set the IE bit in the CPUCTL (R16) register to enable INT.
Alternative header for USB Port
USB HUB Interface
USB Host Interface

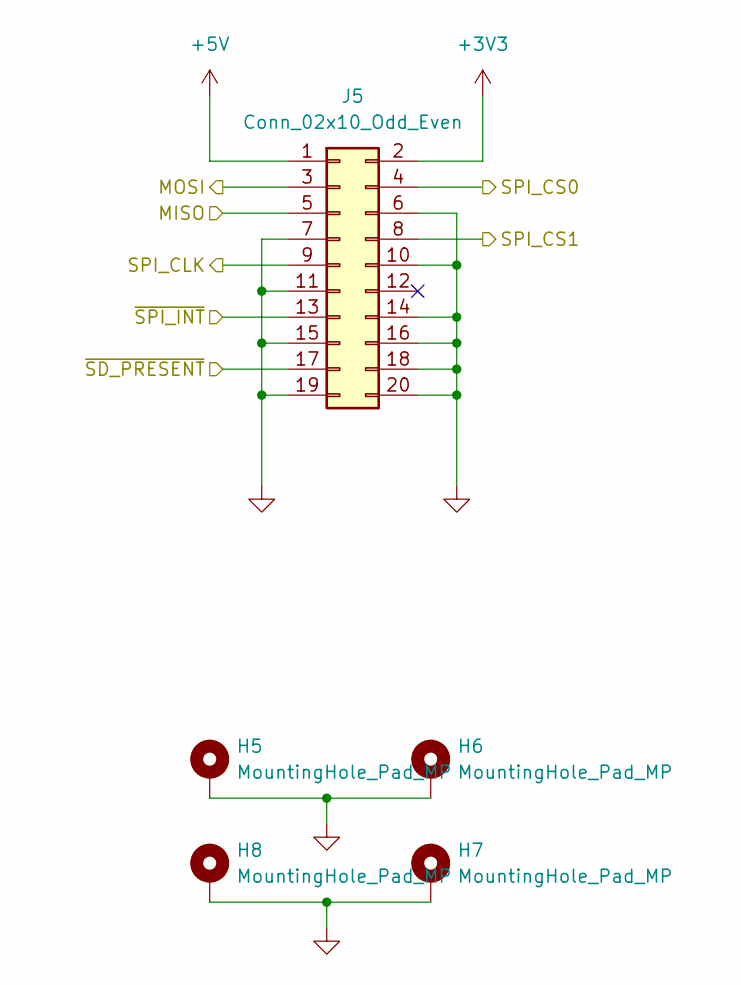
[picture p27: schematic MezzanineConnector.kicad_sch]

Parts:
H5, H6, H7, H8: MountingHole_Pad_MP; MountingHole_3.2mm_M3_Pad_TopBottom
J5: Conn_02x10_Odd_Even; IDC-Header_2x10_P2.54mm_Vertical; MANUFACTURER_PART_NUMBER SBH11-PBPC-D10-ST-BK

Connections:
+3V3: J5.2; also elsewhere on the board
+5V: J5.1; also elsewhere on the board
/MezzanineConnector/MISO: J5.5; also elsewhere on the board
/MezzanineConnector/MOSI: J5.3; also elsewhere on the board
/MezzanineConnector/SPI_CLK: J5.9; also elsewhere on the board
/MezzanineConnector/SPI_CS0: J5.4; also elsewhere on the board
/MezzanineConnector/SPI_CS1: J5.8; also elsewhere on the board
/MezzanineConnector/~SD_PRESENT: J5.17; also elsewhere on the board
/MezzanineConnector/~SPI_INT: J5.13; also elsewhere on the board
GND: H5.MP, H6.MP, H7.MP, H8.MP, J5.6, J5.7, J5.10, J5.11, J5.14, J5.15, J5.16, J5.18, J5.19, J5.20; also elsewhere on the board

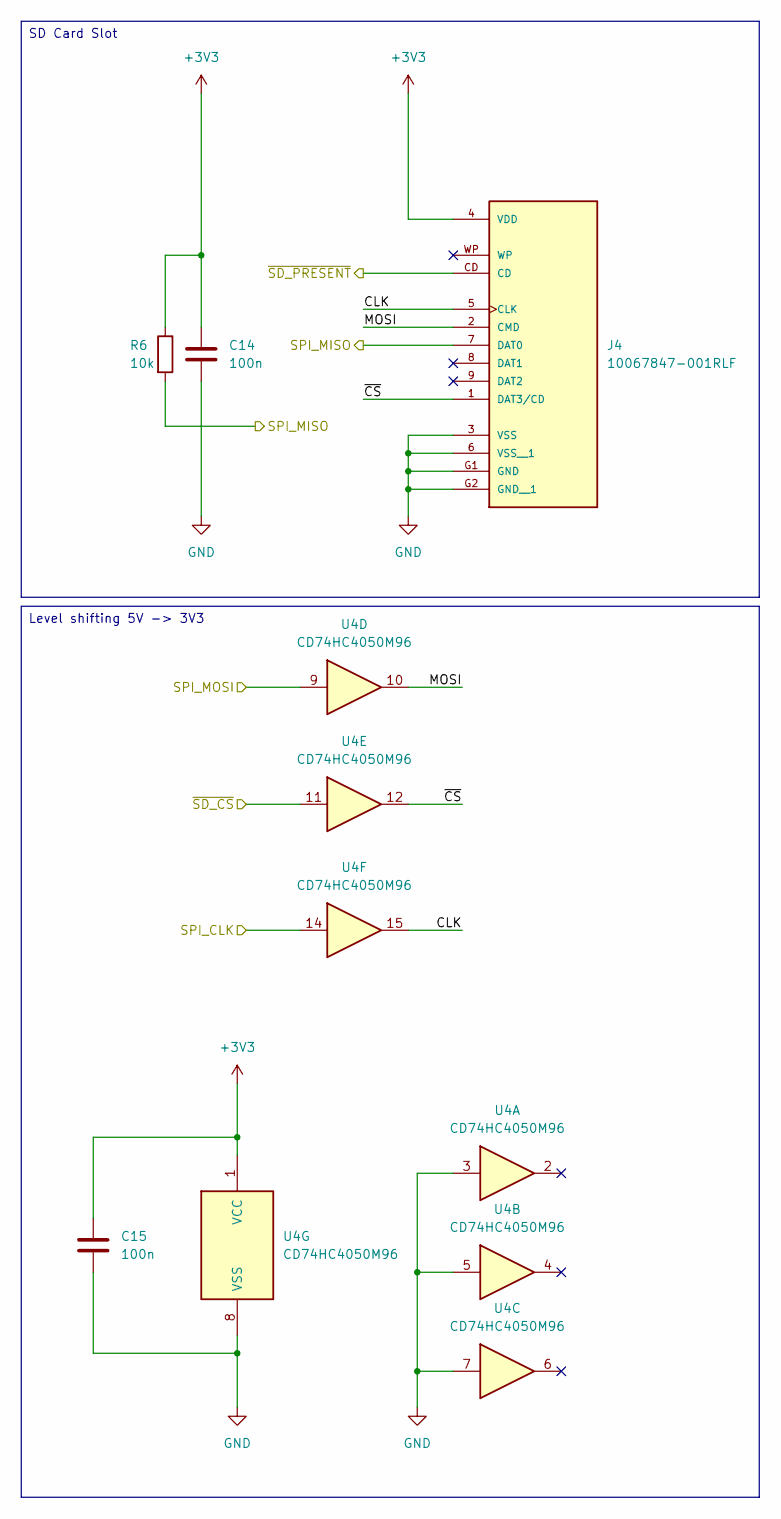
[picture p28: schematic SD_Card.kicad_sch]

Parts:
C14, C15: 100n; C_0603_1608Metric; MANUFACTURER_PART_NUMBER C0603C104K5RACTU
J4: 10067847-001RLF; AMPHENOL_10067847-001RLF; PARTREV K
R6: 10k; R_0603_1608Metric; MANUFACTURER_PART_NUMBER RC0603FR-0710KL
U4: CD74HC4050M96; SOIC-16_3.9x9.9mm_P1.27mm; MANUFACTURER_PART_NUMBER CD74HC4050M96

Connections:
+3V3: C14.1, C15.1, J4.4 (VDD), R6.1, U4.1 (VCC); also elsewhere on the board
/MezzanineConnector/MISO: J4.7 (DAT0), R6.2; also elsewhere on the board
/MezzanineConnector/MOSI: U4.9; also elsewhere on the board
/MezzanineConnector/SPI_CLK: U4.14; also elsewhere on the board
/MezzanineConnector/SPI_CS1: U4.11; also elsewhere on the board
/MezzanineConnector/~SD_PRESENT: J4.CD; also elsewhere on the board
/SD_Card/CLK: J4.5 (CLK), U4.15
/SD_Card/MOSI: J4.2 (CMD), U4.10
/SD_Card/~CS: J4.1 (DAT3/CD), U4.12
GND: C14.2, C15.2, J4.3 (VSS), J4.6 (VSS__1), J4.G1 (GND), J4.G2 (GND__1), U4.3, U4.5, U4.7, U4.8 (VSS); also elsewhere on the board

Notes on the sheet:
Level shifting 5V -> 3V3
SD Card Slot

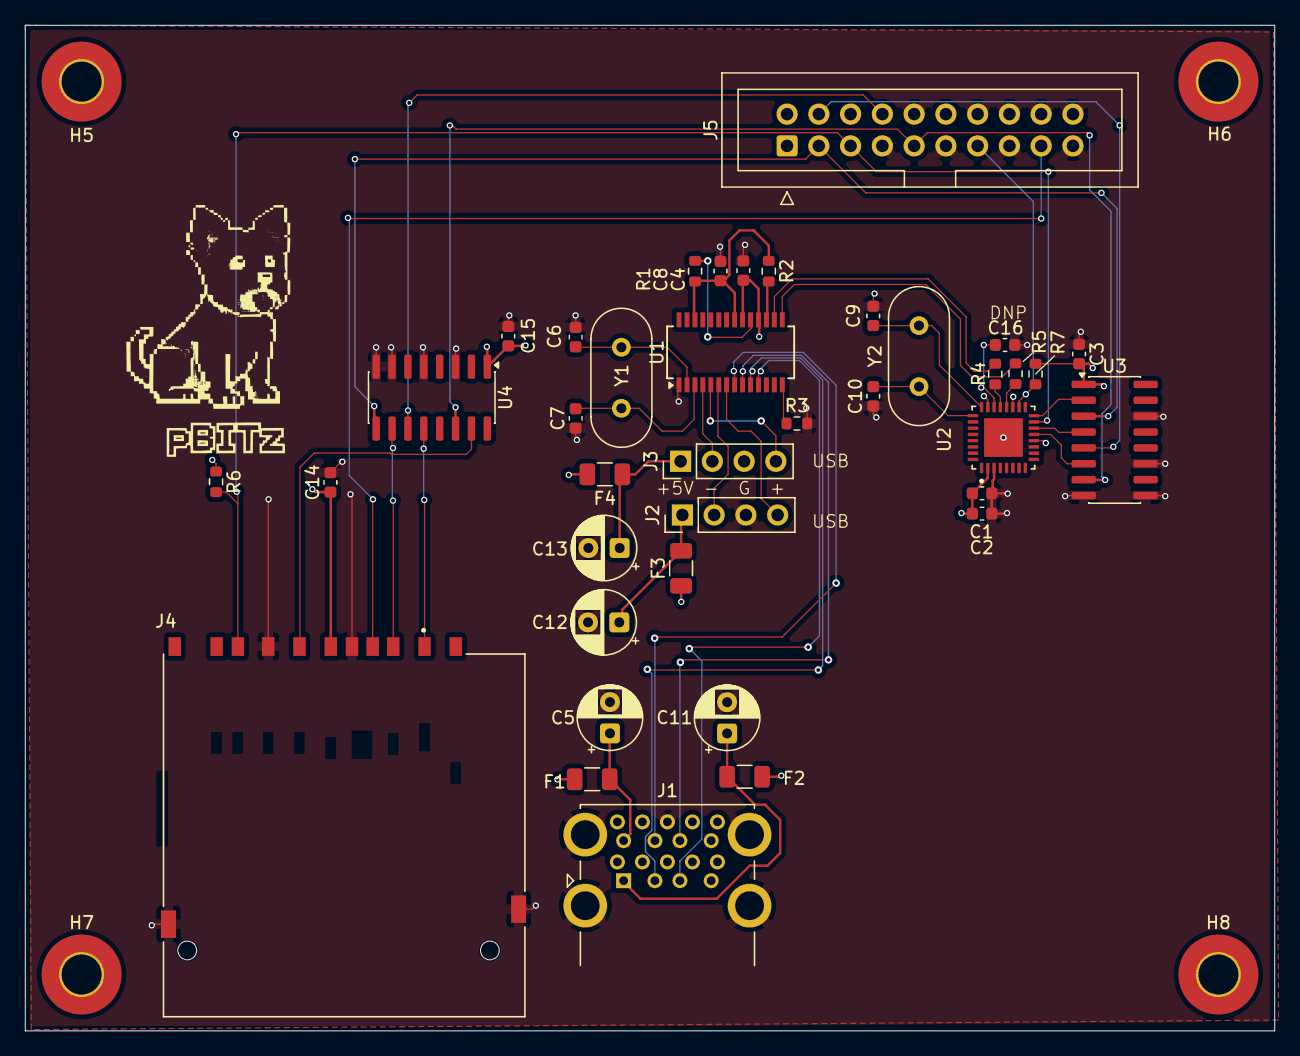
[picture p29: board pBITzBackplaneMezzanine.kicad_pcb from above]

Board: 4 copper layers, 99.9 x 80.4 mm, 42 parts (0 on the bottom side), 41 nets.

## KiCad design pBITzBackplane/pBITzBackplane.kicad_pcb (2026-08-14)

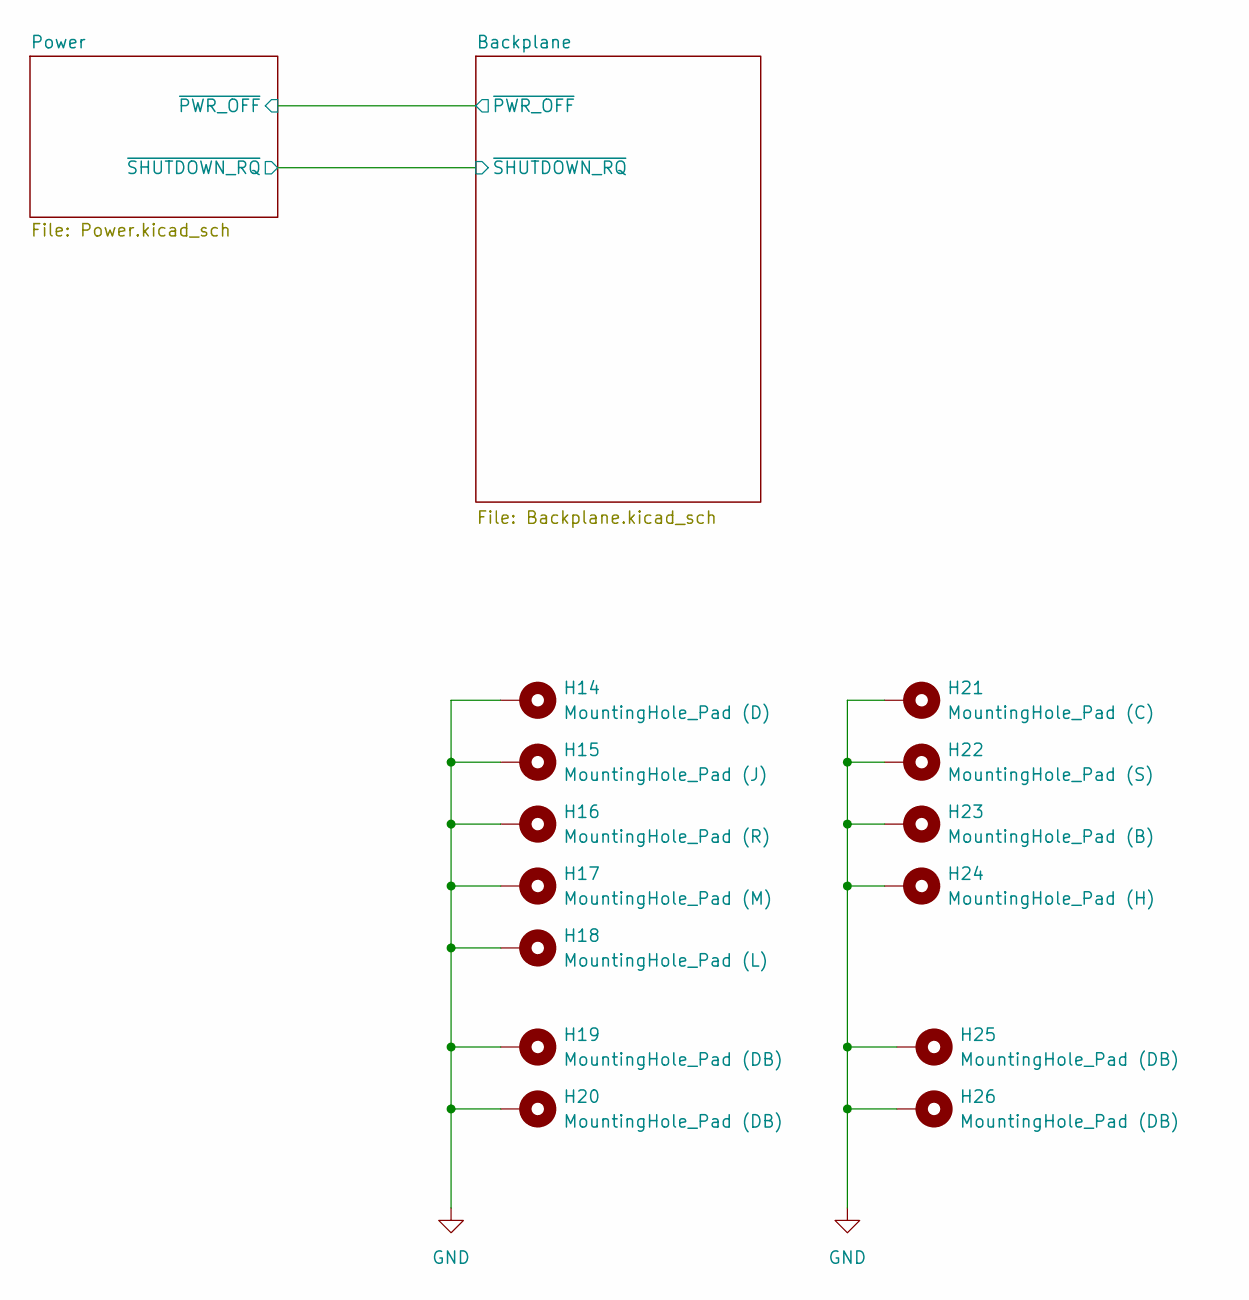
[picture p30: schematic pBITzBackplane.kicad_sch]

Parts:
H14: MountingHole_Pad (D); MountingHole_3.5mm_Pad_TopBottom
H15: MountingHole_Pad (J); MountingHole_3.5mm_Pad_TopBottom
H16: MountingHole_Pad (R); MountingHole_3.5mm_Pad_TopBottom
H17: MountingHole_Pad (M); MountingHole_3.5mm_Pad_TopBottom
H18: MountingHole_Pad (L); MountingHole_3.5mm_Pad_TopBottom
H19, H20, H25, H26: MountingHole_Pad (DB); MountingHole_3.5mm_Pad_TopBottom
H21: MountingHole_Pad (C); MountingHole_3.5mm_Pad_TopBottom
H22: MountingHole_Pad (S); MountingHole_3.5mm_Pad_TopBottom
H23: MountingHole_Pad (B); MountingHole_3.5mm_Pad_TopBottom
H24: MountingHole_Pad (H); MountingHole_3.5mm_Pad_TopBottom

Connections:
GND: H14.1 (1_1), H15.1 (1_1), H16.1 (1_1), H17.1 (1_1), H18.1 (1_1), H19.1 (1_1), H20.1 (1_1), H21.1 (1_1), H22.1 (1_1), H23.1 (1_1), H24.1 (1_1), H25.1 (1_1), H26.1 (1_1); also elsewhere on the board

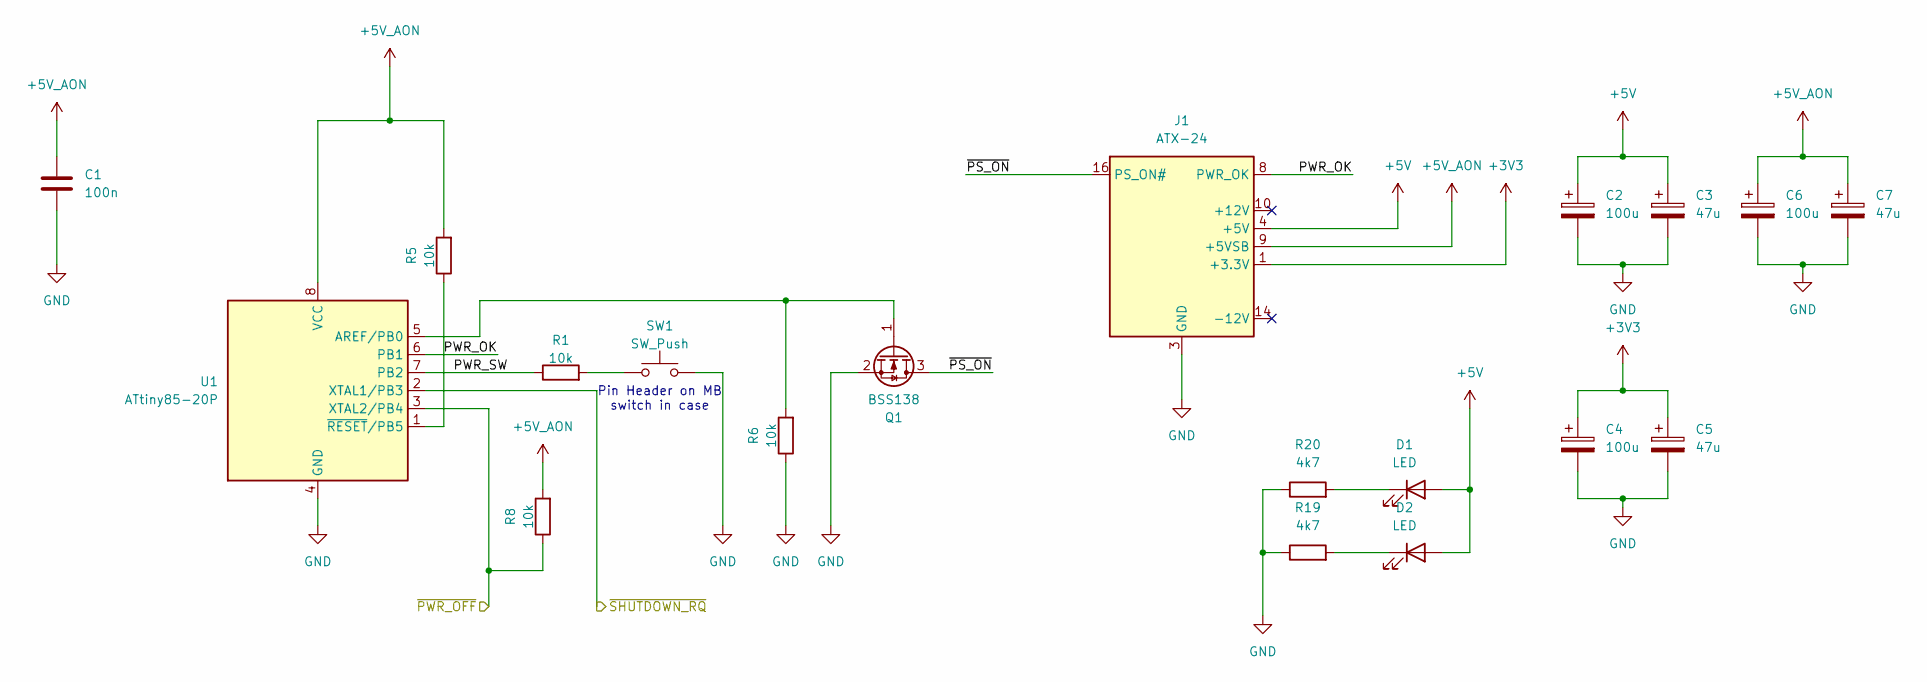
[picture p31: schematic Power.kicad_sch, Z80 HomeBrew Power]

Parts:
C1: 100n; C_1206_3216Metric_Pad1.33x1.80mm_HandSolder; MANUFACTURER_PART_NUMBER C1206C104K3RACTU
C2, C4, C6: 100u; CP_Radial_D5.0mm_P2.00mm; MANUFACTURER_PART_NUMBER 25YXJ100MTA5X11
C3, C5, C7: 47u; CP_Radial_D5.0mm_P2.00mm; MANUFACTURER_PART_NUMBER 25YXJ47MTA5X11
D1: LED; LED_D5.0mm
D2: LED; PinHeader_2x01_P2.54mm_Vertical
J1: ATX-24; MOLEX_39281243; MANUFACTURER_PART_NUMBER 0039281243
Q1: BSS138; SOT-23; MANUFACTURER_PART_NUMBER BSS138
R1, R5, R6, R8: 10k; R_1206_3216Metric_Pad1.30x1.75mm_HandSolder; MANUFACTURER_PART_NUMBER RC1206FR-0710KL
R19, R20: 4k7; R_1206_3216Metric_Pad1.30x1.75mm_HandSolder; MANUFACTURER_PART_NUMBER RC1206FR-074K7L
SW1: SW_Push; PinHeader_1x02_P2.54mm_Vertical
U1: ATtiny85-20P; DIP-8_W7.62mm; MANUFACTURER_PART_NUMBER A 08-LC-TT

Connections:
+3V3: C4.1, C5.1, J1.1 (+3.3V), J1.2 (+3.3V), J1.12 (+3.3V), J1.13 (+3.3V); also elsewhere on the board
+5V: C2.1, C3.1, D1.2 (A), D2.2 (A), J1.4 (+5V), J1.6 (+5V), J1.21 (+5V), J1.22 (+5V), J1.23 (+5V); also elsewhere on the board
+5V_AON: C1.1, C6.1, C7.1, J1.9 (+5VSB), R5.2, R8.2, U1.8 (VCC)
/Backplane/~PWR_OFF: R8.1, U1.3 (XTAL2/PB4); also elsewhere on the board
/Backplane/~SHUTDOWN_RQ: U1.2 (XTAL1/PB3); also elsewhere on the board
/Power/PWR_OK: J1.8 (PWR_OK), U1.6 (PB1)
/Power/PWR_SW: R1.1, U1.7 (PB2)
/Power/~PS_ON: J1.16 (PS_ON#), Q1.3 (D)
GND: C1.2, C2.2, C3.2, C4.2, C5.2, C6.2, C7.2, J1.3 (GND), J1.5 (GND), J1.7 (GND), J1.15 (GND), J1.17 (GND), J1.18 (GND), J1.19 (GND), J1.24 (GND), Q1.2 (S), R6.1, R19.1, R20.1, SW1.2, U1.4 (GND); also elsewhere on the board
unnamed: D1.1 (K), R20.2
unnamed: D2.1 (K), R19.2
unnamed: Q1.1 (G), R6.2, U1.5 (AREF/PB0)
unnamed: R1.2, SW1.1
unnamed: R5.1, U1.1 (~RESET/PB5)

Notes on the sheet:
Pin Header on MB switch in case

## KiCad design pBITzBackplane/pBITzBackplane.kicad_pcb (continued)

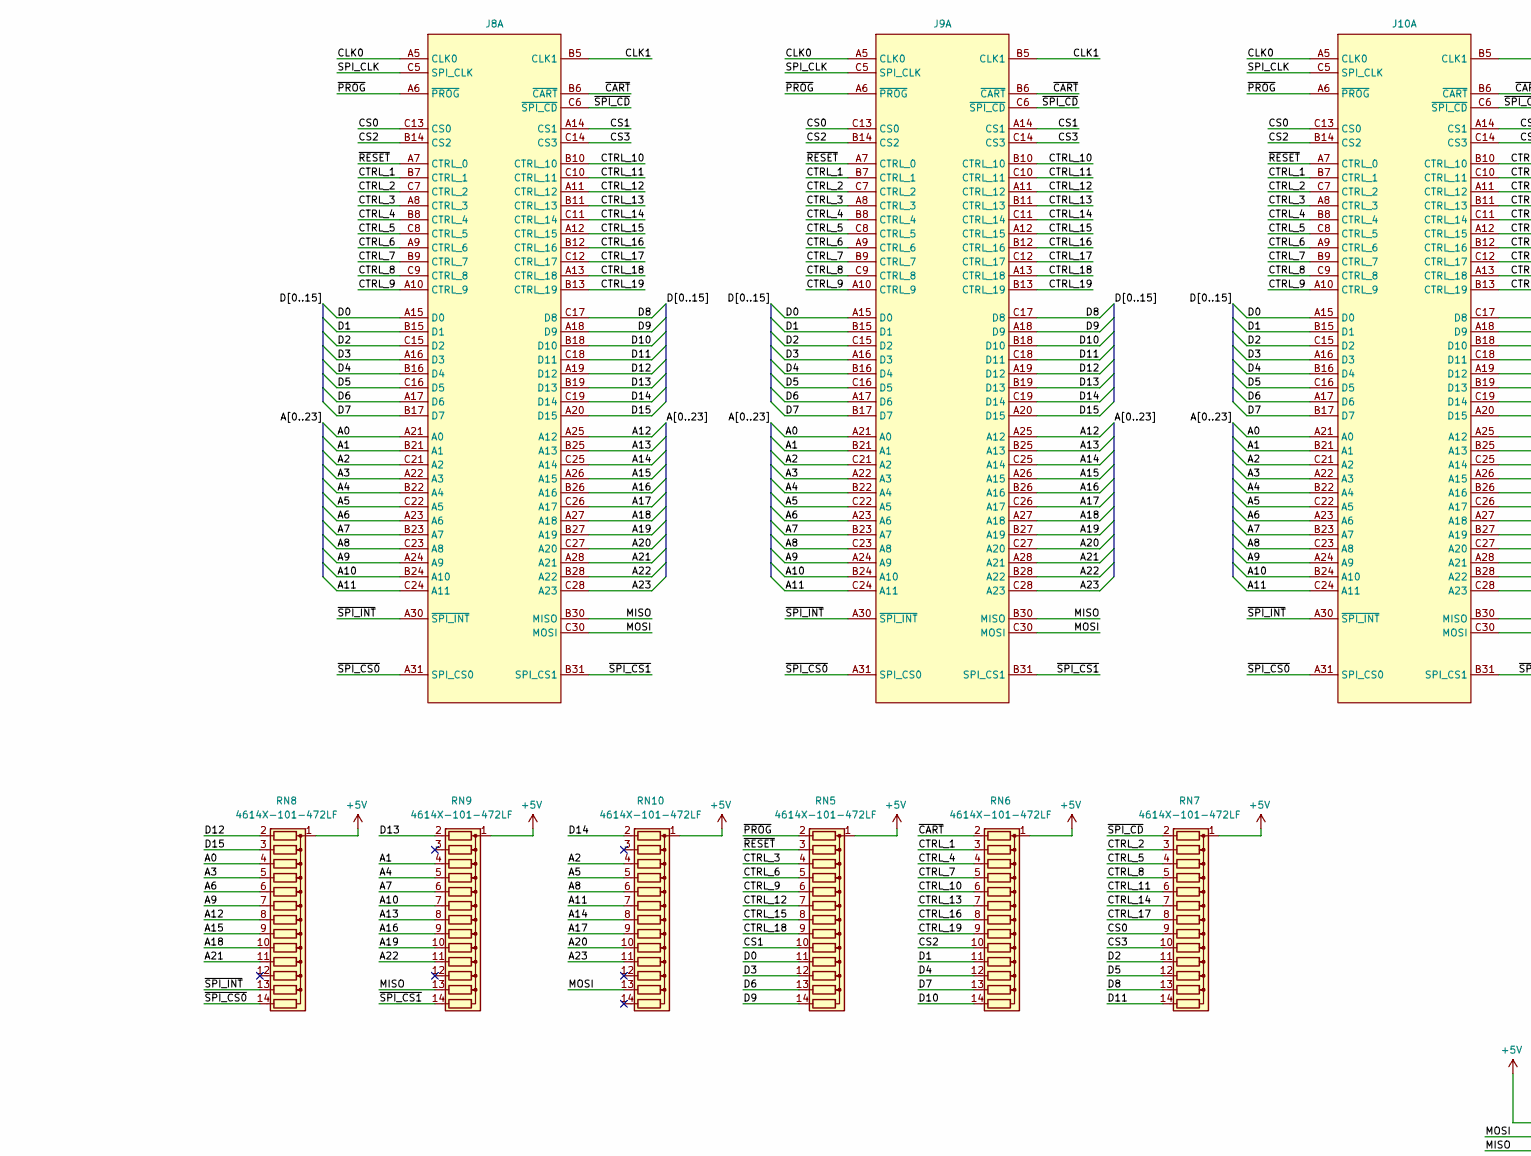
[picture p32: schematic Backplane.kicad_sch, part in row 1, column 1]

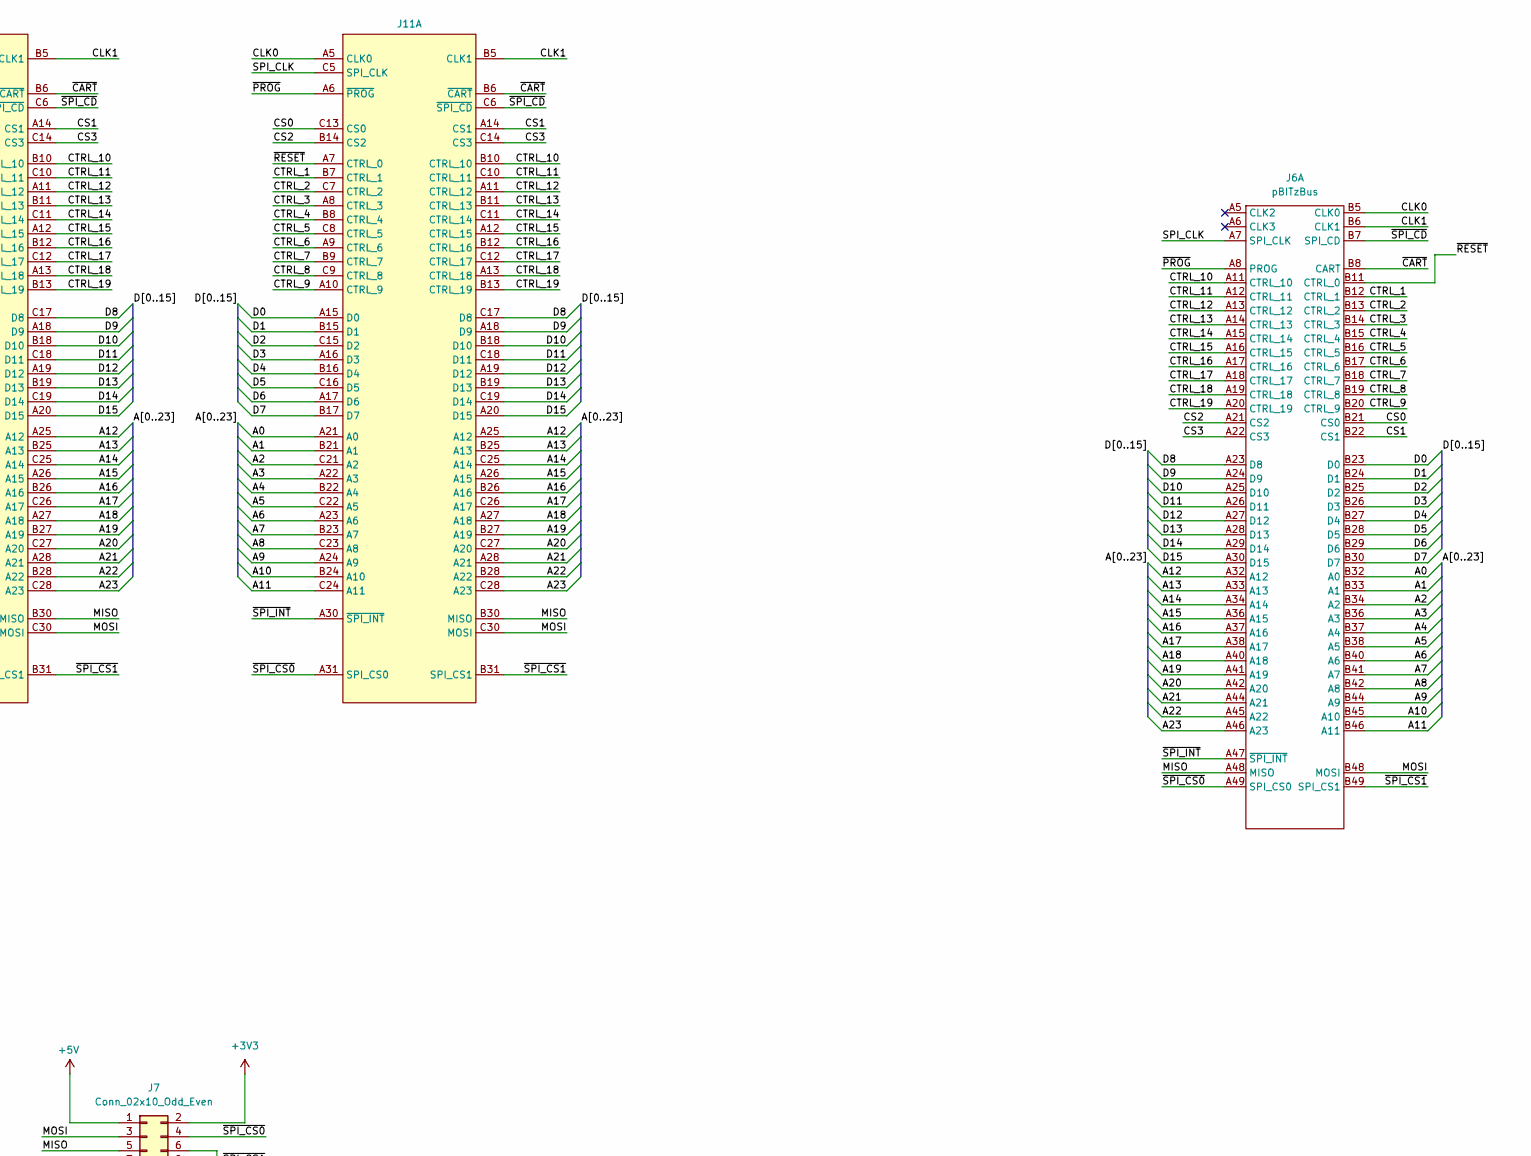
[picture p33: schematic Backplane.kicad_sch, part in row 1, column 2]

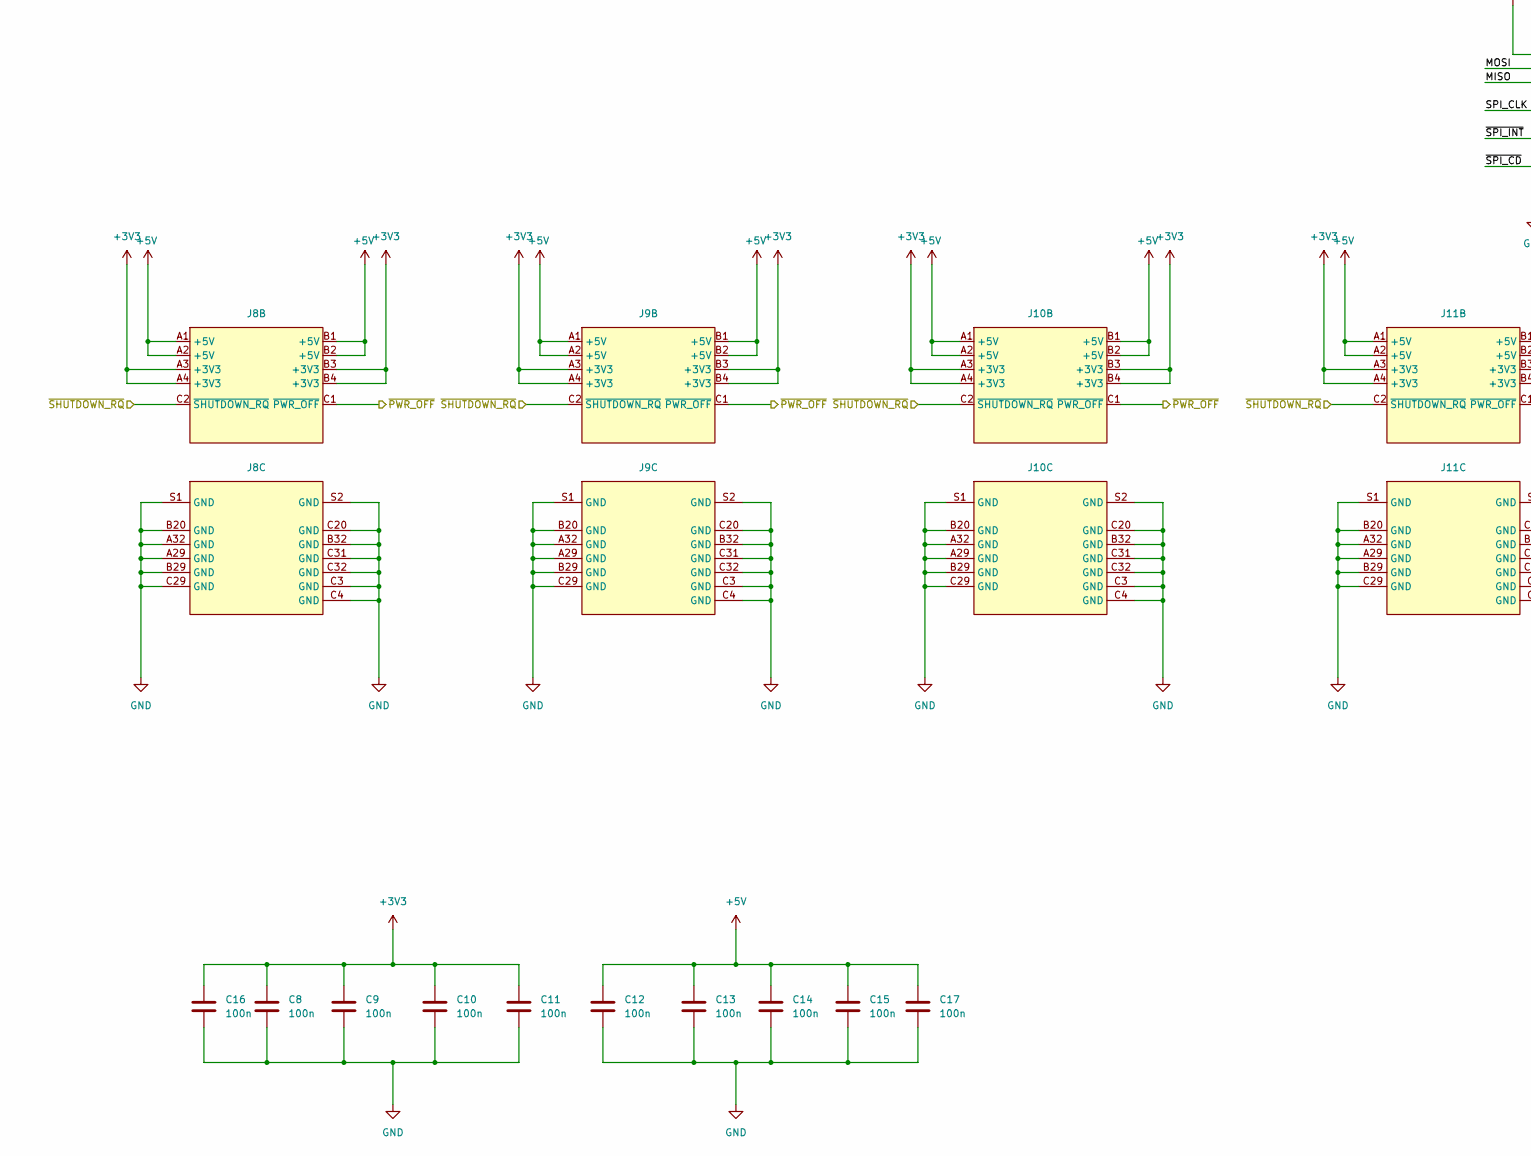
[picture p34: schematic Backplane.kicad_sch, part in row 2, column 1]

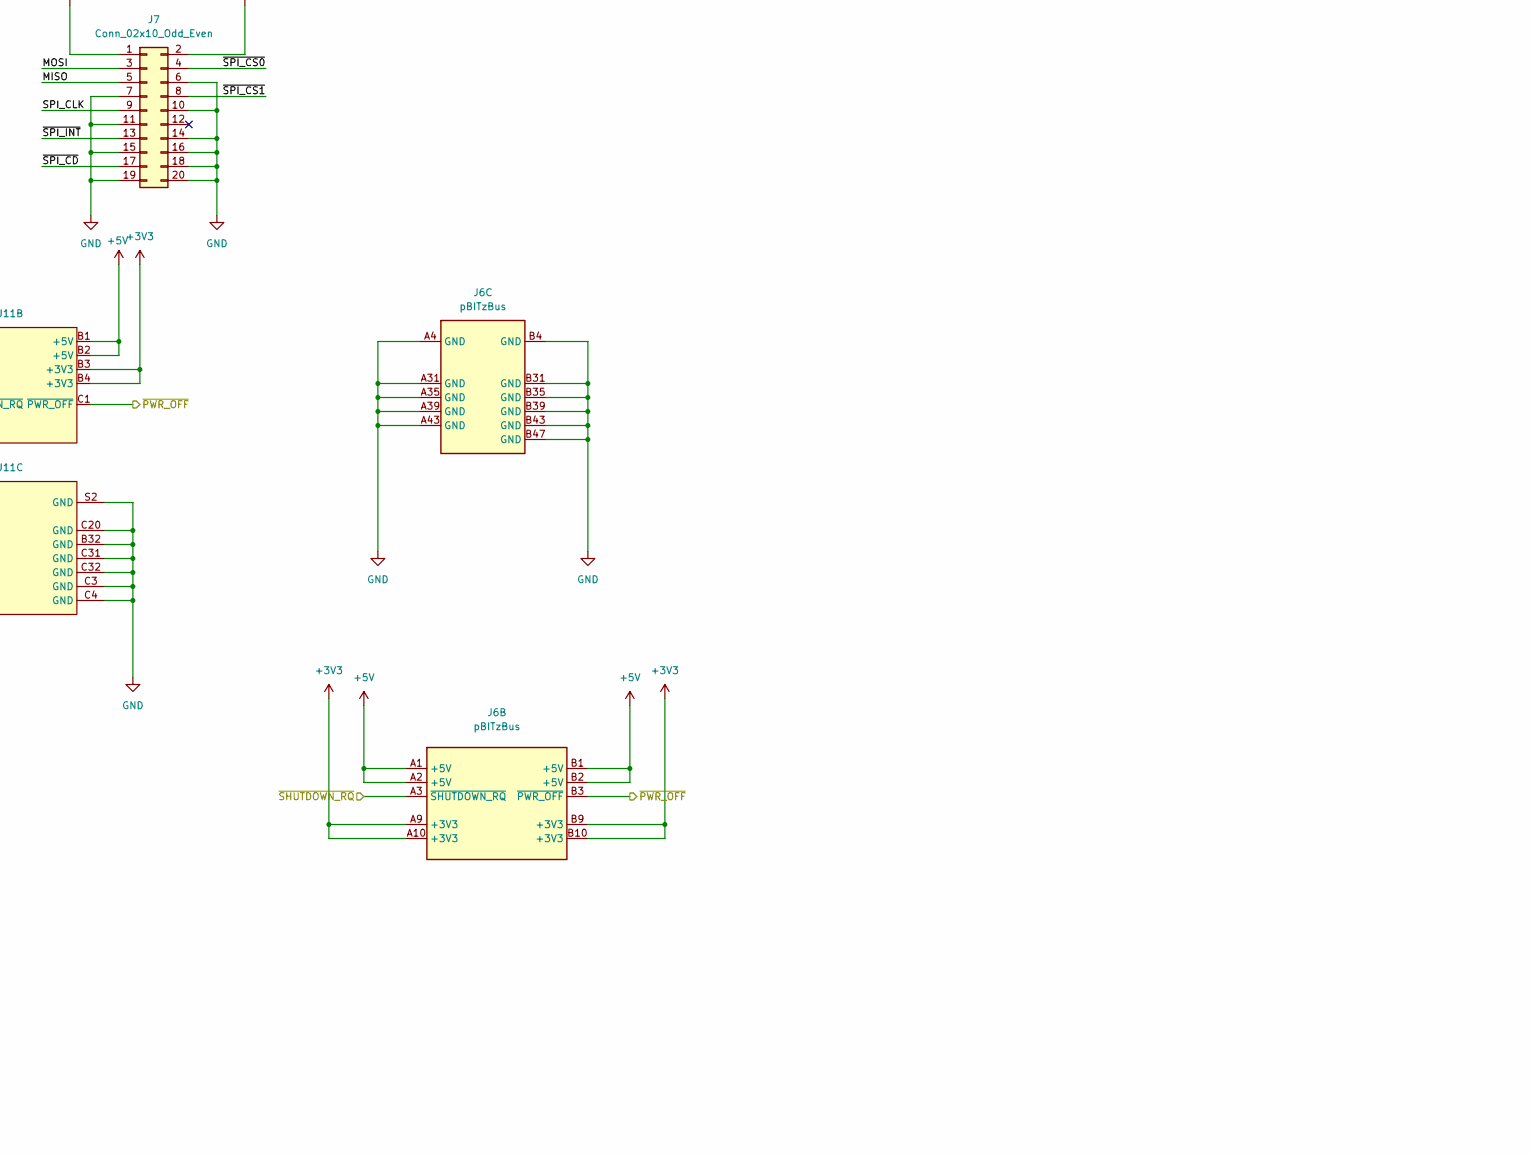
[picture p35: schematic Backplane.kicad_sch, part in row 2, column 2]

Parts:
C8, C9, C10, C11, C12, C13, C14, C15, C16, C17: 100n; C_1206_3216Metric_Pad1.33x1.80mm_HandSolder; MANUFACTURER_PART_NUMBER C1206C104K3RACTU
J6: pBITzBus; SAMTEC_PCIE-098-02-X-D-RA; MANUFACTURER_PART_NUMBER PCIE-098-02-X-D-RA
J7: Conn_02x10_Odd_Even; IDC-Header_2x10_P2.54mm_Vertical; MANUFACTURER_PART_NUMBER SBH11-PBPC-D10-ST-BK
J8, J9, J10, J11: AMPHENOL_86093968114T55F1LF; MANUFACTURER_PART_NUMBER 86093968114T55F1LF
RN5, RN6, RN7, RN8, RN9, RN10: 4614X-101-472LF; R_Array_SIP14; MANUFACTURER_PART_NUMBER 4614X-101-472LF

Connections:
+3V3: C8.1, C9.1, C10.1, C11.1, C16.1, J6.A9 (+3V3), J6.A10 (+3V3), J6.B9 (+3V3), J6.B10 (+3V3), J7.2, J8.A3 (+3V3), J8.A4 (+3V3), J8.B3 (+3V3), J8.B4 (+3V3), J9.A3 (+3V3), J9.A4 (+3V3), J9.B3 (+3V3), J9.B4 (+3V3), J10.A3 (+3V3), J10.A4 (+3V3), J10.B3 (+3V3), J10.B4 (+3V3), J11.A3 (+3V3), J11.A4 (+3V3), J11.B3 (+3V3), J11.B4 (+3V3); also elsewhere on the board
+5V: C12.1, C13.1, C14.1, C15.1, C17.1, J6.A1 (+5V), J6.A2 (+5V), J6.B1 (+5V), J6.B2 (+5V), J7.1, J8.A1 (+5V), J8.A2 (+5V), J8.B1 (+5V), J8.B2 (+5V), J9.A1 (+5V), J9.A2 (+5V), J9.B1 (+5V), J9.B2 (+5V), J10.A1 (+5V), J10.A2 (+5V), J10.B1 (+5V), J10.B2 (+5V), J11.A1 (+5V), J11.A2 (+5V), J11.B1 (+5V), J11.B2 (+5V), RN5.1 (common), RN6.1 (common), RN7.1 (common), RN8.1 (common), RN9.1 (common), RN10.1 (common); also elsewhere on the board
/Backplane/A0: J6.B32 (A0), J8.A21 (A0), J9.A21 (A0), J10.A21 (A0), J11.A21 (A0), RN8.4 (R3)
/Backplane/A1: J6.B33 (A1), J8.B21 (A1), J9.B21 (A1), J10.B21 (A1), J11.B21 (A1), RN9.4 (R3)
/Backplane/A2: J6.B34 (A2), J8.C21 (A2), J9.C21 (A2), J10.C21 (A2), J11.C21 (A2), RN10.4 (R3)
/Backplane/A3: J6.B36 (A3), J8.A22 (A3), J9.A22 (A3), J10.A22 (A3), J11.A22 (A3), RN8.5 (R4)
/Backplane/A4: J6.B37 (A4), J8.B22 (A4), J9.B22 (A4), J10.B22 (A4), J11.B22 (A4), RN9.5 (R4)
/Backplane/A5: J6.B38 (A5), J8.C22 (A5), J9.C22 (A5), J10.C22 (A5), J11.C22 (A5), RN10.5 (R4)
/Backplane/A6: J6.B40 (A6), J8.A23 (A6), J9.A23 (A6), J10.A23 (A6), J11.A23 (A6), RN8.6 (R5)
/Backplane/A7: J6.B41 (A7), J8.B23 (A7), J9.B23 (A7), J10.B23 (A7), J11.B23 (A7), RN9.6 (R5)
/Backplane/A8: J6.B42 (A8), J8.C23 (A8), J9.C23 (A8), J10.C23 (A8), J11.C23 (A8), RN10.6 (R5)
/Backplane/A9: J6.B44 (A9), J8.A24 (A9), J9.A24 (A9), J10.A24 (A9), J11.A24 (A9), RN8.7 (R6)
/Backplane/A10: J6.B45 (A10), J8.B24 (A10), J9.B24 (A10), J10.B24 (A10), J11.B24 (A10), RN9.7 (R6)
/Backplane/A11: J6.B46 (A11), J8.C24 (A11), J9.C24 (A11), J10.C24 (A11), J11.C24 (A11), RN10.7 (R6)
/Backplane/A12: J6.A32 (A12), J8.A25 (A12), J9.A25 (A12), J10.A25 (A12), J11.A25 (A12), RN8.8 (R7)
/Backplane/A13: J6.A33 (A13), J8.B25 (A13), J9.B25 (A13), J10.B25 (A13), J11.B25 (A13), RN9.8 (R7)
/Backplane/A14: J6.A34 (A14), J8.C25 (A14), J9.C25 (A14), J10.C25 (A14), J11.C25 (A14), RN10.8 (R7)
/Backplane/A15: J6.A36 (A15), J8.A26 (A15), J9.A26 (A15), J10.A26 (A15), J11.A26 (A15), RN8.9 (R8)
/Backplane/A16: J6.A37 (A16), J8.B26 (A16), J9.B26 (A16), J10.B26 (A16), J11.B26 (A16), RN9.9 (R8)
/Backplane/A17: J6.A38 (A17), J8.C26 (A17), J9.C26 (A17), J10.C26 (A17), J11.C26 (A17), RN10.9 (R8)
/Backplane/A18: J6.A40 (A18), J8.A27 (A18), J9.A27 (A18), J10.A27 (A18), J11.A27 (A18), RN8.10 (R9)
/Backplane/A19: J6.A41 (A19), J8.B27 (A19), J9.B27 (A19), J10.B27 (A19), J11.B27 (A19), RN9.10 (R9)
/Backplane/A20: J6.A42 (A20), J8.C27 (A20), J9.C27 (A20), J10.C27 (A20), J11.C27 (A20), RN10.10 (R9)
/Backplane/A21: J6.A44 (A21), J8.A28 (A21), J9.A28 (A21), J10.A28 (A21), J11.A28 (A21), RN8.11 (R10)
/Backplane/A22: J6.A45 (A22), J8.B28 (A22), J9.B28 (A22), J10.B28 (A22), J11.B28 (A22), RN9.11 (R10)
/Backplane/A23: J6.A46 (A23), J8.C28 (A23), J9.C28 (A23), J10.C28 (A23), J11.C28 (A23), RN10.11 (R10)
/Backplane/CLK0: J6.B5 (CLK0), J8.A5 (CLK0), J9.A5 (CLK0), J10.A5 (CLK0), J11.A5 (CLK0)
/Backplane/CLK1: J6.B6 (CLK1), J8.B5 (CLK1), J9.B5 (CLK1), J10.B5 (CLK1), J11.B5 (CLK1)
/Backplane/CS0: J6.B21 (CS0), J8.C13 (CS0), J9.C13 (CS0), J10.C13 (CS0), J11.C13 (CS0), RN7.9 (R8)
/Backplane/CS1: J6.B22 (CS1), J8.A14 (CS1), J9.A14 (CS1), J10.A14 (CS1), J11.A14 (CS1), RN5.10 (R9)
/Backplane/CS2: J6.A21 (CS2), J8.B14 (CS2), J9.B14 (CS2), J10.B14 (CS2), J11.B14 (CS2), RN6.10 (R9)
/Backplane/CS3: J6.A22 (CS3), J8.C14 (CS3), J9.C14 (CS3), J10.C14 (CS3), J11.C14 (CS3), RN7.10 (R9)
/Backplane/CTRL_1: J6.B12 (CTRL_1), J8.B7 (CTRL_1), J9.B7 (CTRL_1), J10.B7 (CTRL_1), J11.B7 (CTRL_1), RN6.3 (R2)
/Backplane/CTRL_2: J6.B13 (CTRL_2), J8.C7 (CTRL_2), J9.C7 (CTRL_2), J10.C7 (CTRL_2), J11.C7 (CTRL_2), RN7.3 (R2)
/Backplane/CTRL_3: J6.B14 (CTRL_3), J8.A8 (CTRL_3), J9.A8 (CTRL_3), J10.A8 (CTRL_3), J11.A8 (CTRL_3), RN5.4 (R3)
/Backplane/CTRL_4: J6.B15 (CTRL_4), J8.B8 (CTRL_4), J9.B8 (CTRL_4), J10.B8 (CTRL_4), J11.B8 (CTRL_4), RN6.4 (R3)
/Backplane/CTRL_5: J6.B16 (CTRL_5), J8.C8 (CTRL_5), J9.C8 (CTRL_5), J10.C8 (CTRL_5), J11.C8 (CTRL_5), RN7.4 (R3)
/Backplane/CTRL_6: J6.B17 (CTRL_6), J8.A9 (CTRL_6), J9.A9 (CTRL_6), J10.A9 (CTRL_6), J11.A9 (CTRL_6), RN5.5 (R4)
/Backplane/CTRL_7: J6.B18 (CTRL_7), J8.B9 (CTRL_7), J9.B9 (CTRL_7), J10.B9 (CTRL_7), J11.B9 (CTRL_7), RN6.5 (R4)
/Backplane/CTRL_8: J6.B19 (CTRL_8), J8.C9 (CTRL_8), J9.C9 (CTRL_8), J10.C9 (CTRL_8), J11.C9 (CTRL_8), RN7.5 (R4)
/Backplane/CTRL_9: J6.B20 (CTRL_9), J8.A10 (CTRL_9), J9.A10 (CTRL_9), J10.A10 (CTRL_9), J11.A10 (CTRL_9), RN5.6 (R5)
/Backplane/CTRL_10: J6.A11 (CTRL_10), J8.B10 (CTRL_10), J9.B10 (CTRL_10), J10.B10 (CTRL_10), J11.B10 (CTRL_10), RN6.6 (R5)
/Backplane/CTRL_11: J6.A12 (CTRL_11), J8.C10 (CTRL_11), J9.C10 (CTRL_11), J10.C10 (CTRL_11), J11.C10 (CTRL_11), RN7.6 (R5)
/Backplane/CTRL_12: J6.A13 (CTRL_12), J8.A11 (CTRL_12), J9.A11 (CTRL_12), J10.A11 (CTRL_12), J11.A11 (CTRL_12), RN5.7 (R6)
/Backplane/CTRL_13: J6.A14 (CTRL_13), J8.B11 (CTRL_13), J9.B11 (CTRL_13), J10.B11 (CTRL_13), J11.B11 (CTRL_13), RN6.7 (R6)
/Backplane/CTRL_14: J6.A15 (CTRL_14), J8.C11 (CTRL_14), J9.C11 (CTRL_14), J10.C11 (CTRL_14), J11.C11 (CTRL_14), RN7.7 (R6)
/Backplane/CTRL_15: J6.A16 (CTRL_15), J8.A12 (CTRL_15), J9.A12 (CTRL_15), J10.A12 (CTRL_15), J11.A12 (CTRL_15), RN5.8 (R7)
/Backplane/CTRL_16: J6.A17 (CTRL_16), J8.B12 (CTRL_16), J9.B12 (CTRL_16), J10.B12 (CTRL_16), J11.B12 (CTRL_16), RN6.8 (R7)
/Backplane/CTRL_17: J6.A18 (CTRL_17), J8.C12 (CTRL_17), J9.C12 (CTRL_17), J10.C12 (CTRL_17), J11.C12 (CTRL_17), RN7.8 (R7)
/Backplane/CTRL_18: J6.A19 (CTRL_18), J8.A13 (CTRL_18), J9.A13 (CTRL_18), J10.A13 (CTRL_18), J11.A13 (CTRL_18), RN5.9 (R8)
/Backplane/CTRL_19: J6.A20 (CTRL_19), J8.B13 (CTRL_19), J9.B13 (CTRL_19), J10.B13 (CTRL_19), J11.B13 (CTRL_19), RN6.9 (R8)
/Backplane/D0: J6.B23 (D0), J8.A15 (D0), J9.A15 (D0), J10.A15 (D0), J11.A15 (D0), RN5.11 (R10)
/Backplane/D1: J6.B24 (D1), J8.B15 (D1), J9.B15 (D1), J10.B15 (D1), J11.B15 (D1), RN6.11 (R10)
/Backplane/D2: J6.B25 (D2), J8.C15 (D2), J9.C15 (D2), J10.C15 (D2), J11.C15 (D2), RN7.11 (R10)
/Backplane/D3: J6.B26 (D3), J8.A16 (D3), J9.A16 (D3), J10.A16 (D3), J11.A16 (D3), RN5.12 (R11)
/Backplane/D4: J6.B27 (D4), J8.B16 (D4), J9.B16 (D4), J10.B16 (D4), J11.B16 (D4), RN6.12 (R11)
/Backplane/D5: J6.B28 (D5), J8.C16 (D5), J9.C16 (D5), J10.C16 (D5), J11.C16 (D5), RN7.12 (R11)
/Backplane/D6: J6.B29 (D6), J8.A17 (D6), J9.A17 (D6), J10.A17 (D6), J11.A17 (D6), RN5.13 (R12)
/Backplane/D7: J6.B30 (D7), J8.B17 (D7), J9.B17 (D7), J10.B17 (D7), J11.B17 (D7), RN6.13 (R12)
/Backplane/D8: J6.A23 (D8), J8.C17 (D8), J9.C17 (D8), J10.C17 (D8), J11.C17 (D8), RN7.13 (R12)
/Backplane/D9: J6.A24 (D9), J8.A18 (D9), J9.A18 (D9), J10.A18 (D9), J11.A18 (D9), RN5.14 (R13)
/Backplane/D10: J6.A25 (D10), J8.B18 (D10), J9.B18 (D10), J10.B18 (D10), J11.B18 (D10), RN6.14 (R13)
/Backplane/D11: J6.A26 (D11), J8.C18 (D11), J9.C18 (D11), J10.C18 (D11), J11.C18 (D11), RN7.14 (R13)
/Backplane/D12: J6.A27 (D12), J8.A19 (D12), J9.A19 (D12), J10.A19 (D12), J11.A19 (D12), RN8.2 (R1)
/Backplane/D13: J6.A28 (D13), J8.B19 (D13), J9.B19 (D13), J10.B19 (D13), J11.B19 (D13), RN9.2 (R1)
/Backplane/D14: J6.A29 (D14), J8.C19 (D14), J9.C19 (D14), J10.C19 (D14), J11.C19 (D14), RN10.2 (R1)
/Backplane/D15: J6.A30 (D15), J8.A20 (D15), J9.A20 (D15), J10.A20 (D15), J11.A20 (D15), RN8.3 (R2)
/Backplane/MISO: J6.A48 (MISO), J7.5, J8.B30 (MISO), J9.B30 (MISO), J10.B30 (MISO), J11.B30 (MISO), RN9.13 (R12)
/Backplane/MOSI: J6.B48 (MOSI), J7.3, J8.C30 (MOSI), J9.C30 (MOSI), J10.C30 (MOSI), J11.C30 (MOSI), RN10.13 (R12)
/Backplane/SPI_CLK: J6.A7 (SPI_CLK), J7.9, J8.C5 (SPI_CLK), J9.C5 (SPI_CLK), J10.C5 (SPI_CLK), J11.C5 (SPI_CLK)
/Backplane/~CART: J6.B8 (CART), J8.B6 (~CART), J9.B6 (~CART), J10.B6 (~CART), J11.B6 (~CART), RN6.2 (R1)
/Backplane/~PROG: J6.A8 (PROG), J8.A6 (~PROG), J9.A6 (~PROG), J10.A6 (~PROG), J11.A6 (~PROG), RN5.2 (R1)
/Backplane/~PWR_OFF: J6.B3 (~PWR_OFF), J8.C1 (~PWR_OFF), J9.C1 (~PWR_OFF), J10.C1 (~PWR_OFF), J11.C1 (~PWR_OFF); also elsewhere on the board
/Backplane/~RESET: J6.B11 (CTRL_0), J8.A7 (CTRL_0), J9.A7 (CTRL_0), J10.A7 (CTRL_0), J11.A7 (CTRL_0), RN5.3 (R2)
/Backplane/~SHUTDOWN_RQ: J6.A3 (~SHUTDOWN_RQ), J8.C2 (~SHUTDOWN_RQ), J9.C2 (~SHUTDOWN_RQ), J10.C2 (~SHUTDOWN_RQ), J11.C2 (~SHUTDOWN_RQ); also elsewhere on the board
/Backplane/~SPI_CD: J6.B7 (SPI_CD), J7.17, J8.C6 (~SPI_CD), J9.C6 (~SPI_CD), J10.C6 (~SPI_CD), J11.C6 (~SPI_CD), RN7.2 (R1)
/Backplane/~SPI_CS0: J6.A49 (SPI_CS0), J7.4, J8.A31 (SPI_CS0), J9.A31 (SPI_CS0), J10.A31 (SPI_CS0), J11.A31 (SPI_CS0), RN8.14 (R13)
/Backplane/~SPI_CS1: J6.B49 (SPI_CS1), J7.8, J8.B31 (SPI_CS1), J9.B31 (SPI_CS1), J10.B31 (SPI_CS1), J11.B31 (SPI_CS1), RN9.14 (R13)
/Backplane/~SPI_INT: J6.A47 (~SPI_INT), J7.13, J8.A30 (~SPI_INT), J9.A30 (~SPI_INT), J10.A30 (~SPI_INT), J11.A30 (~SPI_INT), RN8.13 (R12)
GND: C8.2, C9.2, C10.2, C11.2, C12.2, C13.2, C14.2, C15.2, C16.2, C17.2, J6.A4 (GND), J6.A31 (GND), J6.A35 (GND), J6.A39 (GND), J6.A43 (GND), J6.B4 (GND), J6.B31 (GND), J6.B35 (GND), J6.B39 (GND), J6.B43 (GND), J6.B47 (GND), J7.6, J7.7, J7.10, J7.11, J7.14, J7.15, J7.16, J7.18, J7.19, J7.20, J8.A29 (GND), J8.A32 (GND), J8.B20 (GND), J8.B29 (GND), J8.B32 (GND), J8.C3 (GND), J8.C4 (GND), J8.C20 (GND), J8.C29 (GND), J8.C31 (GND), J8.C32 (GND), J8.S1 (GND), J8.S2 (GND), J9.A29 (GND), J9.A32 (GND), J9.B20 (GND), J9.B29 (GND), J9.B32 (GND), J9.C3 (GND), J9.C4 (GND), J9.C20 (GND), J9.C29 (GND), J9.C31 (GND), J9.C32 (GND), J9.S1 (GND), J9.S2 (GND), J10.A29 (GND), J10.A32 (GND), J10.B20 (GND), J10.B29 (GND), J10.B32 (GND), J10.C3 (GND), J10.C4 (GND), J10.C20 (GND), J10.C29 (GND), J10.C31 (GND), J10.C32 (GND), J10.S1 (GND), J10.S2 (GND), J11.A29 (GND), J11.A32 (GND), J11.B20 (GND), J11.B29 (GND), J11.B32 (GND), J11.C3 (GND), J11.C4 (GND), J11.C20 (GND), J11.C29 (GND), J11.C31 (GND), J11.C32 (GND), J11.S1 (GND), J11.S2 (GND); also elsewhere on the board

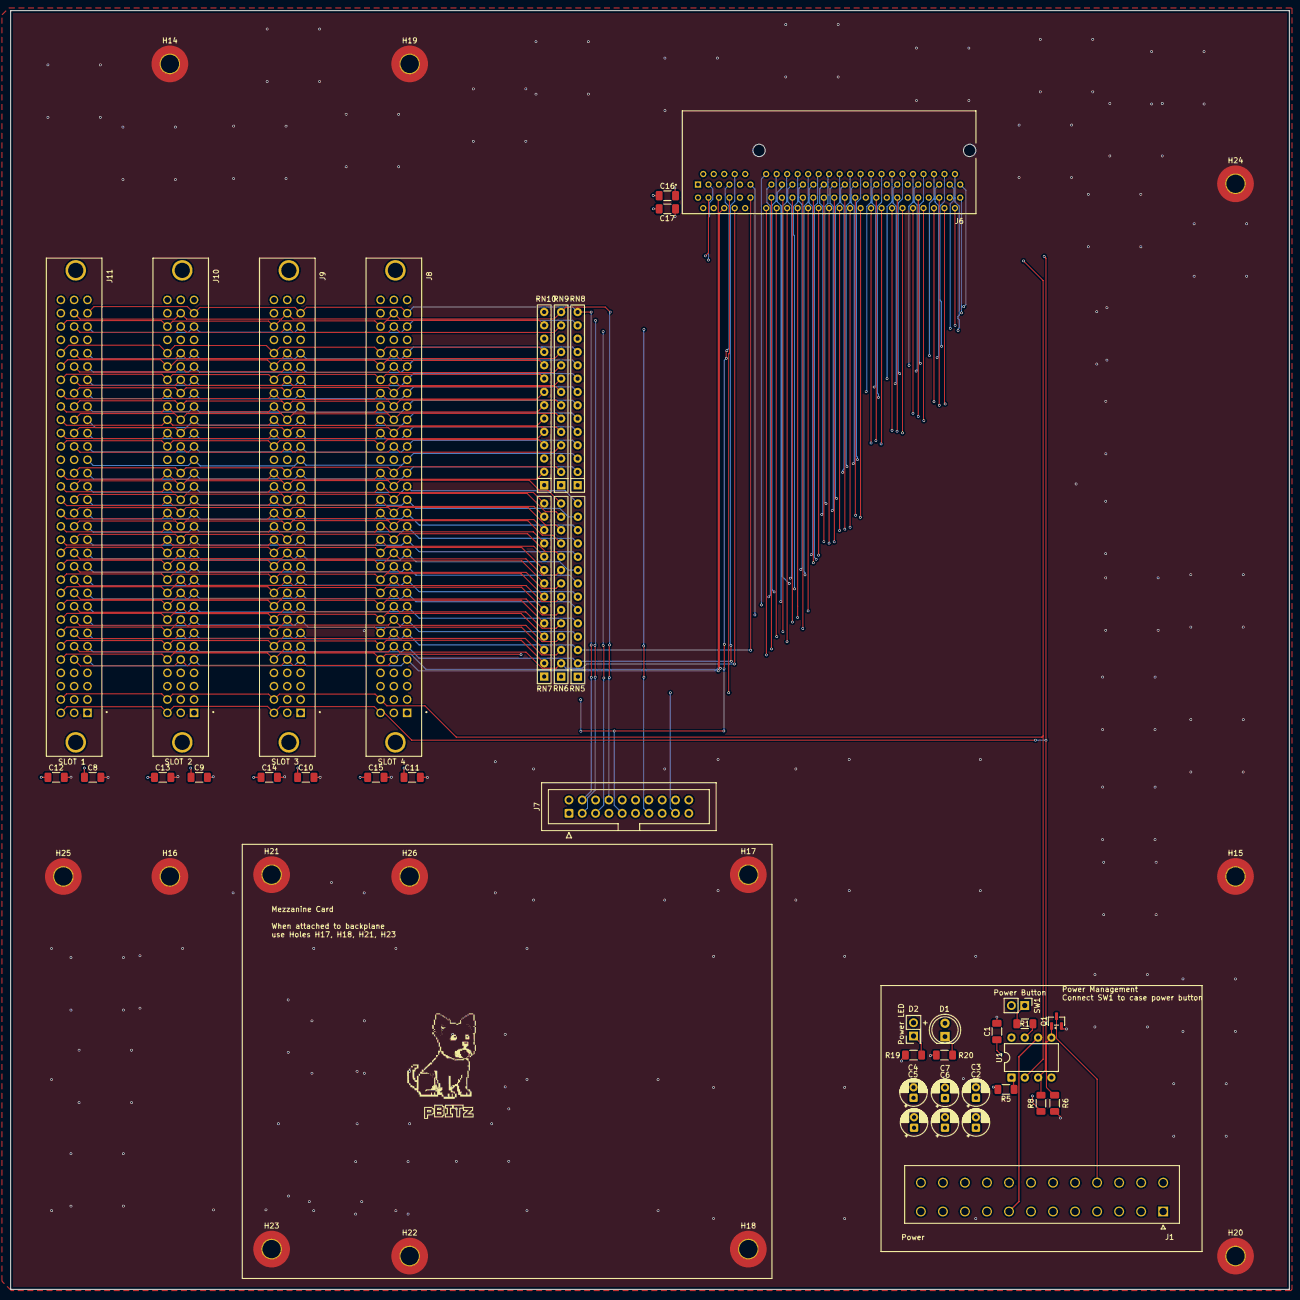
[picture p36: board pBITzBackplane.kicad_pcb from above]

Board: 6 copper layers, 243.8 x 243.8 mm, 54 parts (0 on the bottom side), 89 nets.

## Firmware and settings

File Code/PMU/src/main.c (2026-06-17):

#include <stdint.h>

#include <util/delay.h>

#include "config.h"
#include "power_controller.h"

static void psu_off(void);

/*
 * Configure the PMU GPIO.
 *
 * Active-low external inputs use internal pull-ups. PWR_OK is left without an
 * internal pull-up because it is driven by the ATX PSU. Outputs start with the
 * IO Controller held in reset and the PSU disabled.
 */
static void io_init(void)
{
#if !PMU_IGNORE_IO_CONTROLLER_SIGNALS
    PWR_OFF_RQ_DDR &= ~_BV(PWR_OFF_RQ_PIN);
    PWR_OFF_RQ_PORT |= _BV(PWR_OFF_RQ_PIN);
#endif

    PWR_SW_DDR &= ~_BV(PWR_SW_PIN);
    PWR_SW_PORT |= _BV(PWR_SW_PIN);

    PWR_OK_DDR &= ~_BV(PWR_OK_PIN);
    PWR_OK_PORT &= ~_BV(PWR_OK_PIN);

#if !PMU_IGNORE_IO_CONTROLLER_SIGNALS
    PWR_STATE_DDR |= _BV(PWR_STATE_PIN);
    PWR_STATE_PORT |= _BV(PWR_STATE_PIN);
#else
    PWR_STATE_DDR &= ~_BV(PWR_STATE_PIN);
    PWR_STATE_PORT &= ~_BV(PWR_STATE_PIN);
#endif

    PS_ON_DDR |= _BV(PS_ON_PIN);
    psu_off();
}

static uint8_t pwr_off_requested(void)
{
    /* PWR_OFF_RQ is asserted by the IO Controller when low. */
#if PMU_IGNORE_IO_CONTROLLER_SIGNALS
    return 0;
#else
    return (PWR_OFF_RQ_PINR & _BV(PWR_OFF_RQ_PIN)) == 0;
#endif
}

static uint8_t pwr_switch_pressed(void)
{
    /* The enclosure power switch shorts the input low when pressed. */
    return (PWR_SW_PINR & _BV(PWR_SW_PIN)) == 0;
}

static uint8_t pwr_ok(void)
{
    /* ATX PWR_OK is high when the supply reports stable outputs. */
    return (PWR_OK_PINR & _BV(PWR_OK_PIN)) != 0;
}

static void psu_on(void)
{
    /* Enable the MOSFET so ATX PS_ON# is pulled low. */
#if PS_ON_MOSFET_ON_LEVEL
    PS_ON_PORT |= _BV(PS_ON_PIN);
#else
    PS_ON_PORT &= ~_BV(PS_ON_PIN);
#endif
}

static void psu_off(void)
{
    /* Disable the MOSFET so ATX PS_ON# is released inactive. */
#if PS_ON_MOSFET_OFF_LEVEL
    PS_ON_PORT |= _BV(PS_ON_PIN);
#else
    PS_ON_PORT &= ~_BV(PS_ON_PIN);
#endif
}

static void hold_io_reset(void)
{
    /* PWR_STATE high tells the IO Controller to hold the system in reset. */
#if !PMU_IGNORE_IO_CONTROLLER_SIGNALS
    PWR_STATE_PORT |= _BV(PWR_STATE_PIN);
#endif
}

static void release_io_reset(void)
{
    /* PWR_STATE low tells the IO Controller that the system may run. */
#if !PMU_IGNORE_IO_CONTROLLER_SIGNALS
    PWR_STATE_PORT &= ~_BV(PWR_STATE_PIN);
#endif
}

static void apply_controller_action(power_controller_action_t action)
{
    if (action & POWER_CONTROLLER_ACTION_PSU_ON) {
        psu_on();
    }

    if (action & POWER_CONTROLLER_ACTION_PSU_OFF) {
        psu_off();
    }

    if (action & POWER_CONTROLLER_ACTION_HOLD_IO_RESET) {
        hold_io_reset();
    }

    if (action & POWER_CONTROLLER_ACTION_RELEASE_IO_RESET) {
        release_io_reset();
    }
}

int main(void)
{
    power_controller_t controller;

    io_init();
    power_controller_init(&controller, pwr_switch_pressed(), pwr_ok());

    for (;;) {
        const power_controller_inputs_t inputs = {
            .pwr_switch_pressed = pwr_switch_pressed(),
            .pwr_ok = pwr_ok(),
            .pwr_off_requested = pwr_off_requested(),
        };

        apply_controller_action(power_controller_step(&controller, &inputs));
        _delay_ms(POLL_INTERVAL_MS);
    }
}

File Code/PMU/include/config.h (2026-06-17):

#ifndef CONFIG_H
#define CONFIG_H

#include <avr/io.h>

#include "power_controller.h"

/*
 * Set to 1 to run the PMU without participating in the IO Controller
 * handshake. In that mode the firmware ignores PWR_OFF_RQ and does not drive
 * PWR_STATE.
 */
#ifndef PMU_IGNORE_IO_CONTROLLER_SIGNALS
#define PMU_IGNORE_IO_CONTROLLER_SIGNALS 1
#endif

/*
 * PMU power-controller pin map.
 *
 * Each signal defines the data-direction register, output/input register, and
 * bit used by main.c. Keeping these names signal-oriented makes the firmware
 * easier to check against the schematic.
 */

/* IO Controller asks the PMU to shut down the PSU. Active low input. */
#define PWR_OFF_RQ_DDR  DDRB
#define PWR_OFF_RQ_PORT PORTB
#define PWR_OFF_RQ_PINR PINB
#define PWR_OFF_RQ_PIN  PB4

/* PWR_STATE high holds the IO Controller in reset; low allows it to run. */
#define PWR_STATE_DDR   DDRB
#define PWR_STATE_PORT  PORTB
#define PWR_STATE_PIN   PB3

/* Enclosure power switch. Active low input, handled as an edge/hold signal. */
#define PWR_SW_DDR      DDRB
#define PWR_SW_PORT     PORTB
#define PWR_SW_PINR     PINB
#define PWR_SW_PIN      PB2

/* ATX PSU power-good signal. Active high input from the ATX connector. */
#define PWR_OK_DDR      DDRB
#define PWR_OK_PORT     PORTB
#define PWR_OK_PINR     PINB
#define PWR_OK_PIN      PB1

/* MOSFET gate that controls the ATX PS_ON# line. */
#define PS_ON_DDR       DDRB
#define PS_ON_PORT      PORTB
#define PS_ON_PIN       PB0

/*
 * PB0 drives a MOSFET gate, not the ATX PS_ON# net directly.
 * PB0 high enables the MOSFET and pulls ATX PS_ON# low.
 * PB0 low disables the MOSFET and lets ATX PS_ON# return inactive.
 */
#define PS_ON_MOSFET_ON_LEVEL  1
#define PS_ON_MOSFET_OFF_LEVEL 0

/* Timing values are based on the polling loop in main.c. */
#define POLL_INTERVAL_MS   POWER_CONTROLLER_POLL_INTERVAL_MS

#endif

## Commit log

2026-06-17 Initial Commit... splitting the platform from the Zephyr-80 code/schem
    [039281243.stp, 1-2199300-2.STEP, 10018783-10202TLF.step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]
2026-06-17 Moved modules
    [Backplane.kicad_sch, ClockTree.kicad_sch, Power.kicad_sch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]
2026-06-17 First pass of validation
    [ClockTree.kicad_sch, USBPorts.kicad_sch, pBITzBackplaneMezzanine.kicad_pcb]
2026-06-17 updated the pullups for the power on sequence pins
    [Backplane.kicad_sch, Power.kicad_sch]
2026-06-17 fixed the pullups in the PCB
2026-06-17 Corrections post review
    [MezzanineConnector.kicad_sch, USBPorts.kicad_sch, pBITzBackplaneMezzanine.kicad_pcb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]
2026-06-28 Added production files for mezzanine
    [bom.csv, designators.csv, pBITzBackplaneMezzanine.kicad_pcb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]
2026-06-28 Moved all the KiCad 3D models to a new folder called "3D-Models" and renamed some of the footprints to have a more descriptive name. Added new datasheets for Analog and Peripheral components. Added n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
    [LM4871MX_NOPB.step, RU_20_ADI.step]
2026-07-31 Changed the pBITz backplane connector from a PCIe 8x to a DIN 41612 connector.
    [86093968114T55F1LF.step, Backplane.kicad_sch, bom.csv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]
2026-08-03 Moved to the DIN Connector
    [86093967113T55F1LF.step, IO Controller.kicad_sch, VideoOut.kicad_sch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]
2026-08-03 Fixed the location of the IDC connector the the mezannine
    [designators.csv, pBITzBackplane.kicad_pcb, positions.csv]
2026-08-14 updated part #s
    [Backplane.kicad_sch, Power.kicad_sch, pBITzBackplane.kicad_pcb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]
2026-08-16 Document pBITz device selection and pull-ups
2026-08-16 Tighten pBITz select semantics
2026-08-16 Keep control document current
2026-08-16 Clarify reserved device address zero
2026-08-16 Update backplane architecture for DIN bus and cartridge slot
2026-08-21 Fixed the footprint for the FE1.1
    [pBITzBackplaneMezzanine.kicad_pcb]
2026-08-21 Fixed the footprint for the FE1.1 (missing file)
    [USBPorts.kicad_sch]
